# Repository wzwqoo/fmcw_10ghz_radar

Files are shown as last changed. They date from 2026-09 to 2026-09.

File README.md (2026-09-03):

# 10 GHz FMCW Radar Sensing Platform

A single-board **1TX / 3RX, 10 GHz FMCW radar**, its **Artix-7 range–Doppler–CFAR
backend**, and the **carrier board** that mounts the radar alongside a
global-shutter camera and an impact microphone.

The target application is a golf launch monitor: recover a ball's speed, launch
direction, spin rate and spin axis from one radar and one camera. That
application drives every architectural choice here — three non-collinear
receivers (the minimum that gives a radar-native spin axis), per-receiver
*complex* range–Doppler maps published to DDR3 (the phase the spin-axis
interferometer consumes), and a once-per-shot Ethernet offload so the heavy
post-processing runs on a host PC instead of in fabric.

```
┌─ rf_frontend/ — 10 GHz FMCW front-end ────────────────────────────────────┐
│                                                                           │
│  ADF4159 ramp PLL ──► HMC1163 10 GHz VCO ──► 4 dB branchline coupler      │
│                                                │             │            │
│                                     TX patch column    1→3 Wilkinson tree │
│                                                              │ LO         │
│  RX patch column ×3 ──► PMA3-14LN+ ──► LTC5548 ◄─────────────┘            │
│                                           │                               │
│                           ADA4940-2 IF ───┴──► ADAR7251  4 ch, 16-bit,    │
│                                                          simultaneous     │
│                                                                           │
└───────────────────────────────────────────────────────────────────────────┘
                                        │  40-pin FPC
                                        ▼
┌─ carrier_board/ — camera + radar carrier ─────────────────────────────────┐
│                                                                           │
│  radar 40-pin FPC ────────────────────────┐                               │
│  OV9281 ──MIPI──► TC358748 ──parallel─────┼──► 140-pin B2B ──► FPGA module│
│  INMP441 ──────────I2S────────────────────┘                               │
│                                                                           │
│  RTL8211F 1 GbE ◄─────────────────────────────────────────── UDP offload  │
│                                                                           │
└───────────────────────────────────────────────────────────────────────────┘
                                        │  parallel + I2S over the B2B connector
                                        ▼
┌─ fpga/ — Artix-7 backend ─────────────────────────────────────────────────┐
│                                                                           │
│  PPI bytes ──► TDM ──► BPF + Hilbert FIR ──► range FFT ×3 ──► DDR A       │
│                                                                │          │
│                        Doppler FFT ×3 ◄────────────────────────┘          │
│                              ├──► DDR B   per-RX complex RD maps          │
│                              └──► Σ|X|² ──► DDR C ──► CFAR ──► DDR D      │
│                                                                           │
│  audio + speed trigger ──► one-shot B/C/D dump ──► UDP packetizer         │
│                                                                           │
└───────────────────────────────────────────────────────────────────────────┘
                                        │
                                        ▼  host PC — trajectory, angle of arrival, spin
```

## Repository structure

| Path | Subsystem |
|---|---|
| [`rf_frontend/`](rf_frontend/) | The 10 GHz 1TX/3RX FMCW front-end: KiCad schematics and PCB on Isola 370HR, plus the ADS/Momentum EM results for every distributed structure |
| [`fpga/`](fpga/) | Artix-7 gateware: the raw-ADC → range–Doppler → CFAR pipeline, the DDR-to-host UDP offload path, MicroBlaze firmware, and the simulation stack |
| [`carrier_board/`](carrier_board/) | The carrier PCB that ties camera, radar, FPGA module, Ethernet and audio together, plus the CS-mount lens mechanics |

Each subsystem has its own README with the detail; the tables below are the map.

### `rf_frontend/` — 10 GHz FMCW front-end

A closed-loop fractional-N ramp PLL (ADF4159) drives a 10 GHz VCO (HMC1163)
across a 192 MHz sweep in 108 µs. The VCO fundamental is tapped through a 4 dB
branchline coupler and a 1→3 Wilkinson tree to supply a coherent LO to three
LNA-first receive chains (PMA3-14LN+ → LTC5548 → ADA4940-2), which land on an
ADAR7251's simultaneously-sampled channels. The antennas are series-fed patch
columns arranged in a staggered "^", stepped λ/2 between adjacent phase centres
in both array axes, so per-Doppler-bin angles never wrap.

→ [`rf_frontend/README.md`](rf_frontend/README.md)

### `fpga/` — Artix-7 digital backend

`01_adar7251_ppi_rx` → TDM mux → band-pass + Hilbert FIR → per-RX range FFT →
transposed DDR scatter (region A) → Doppler sequencer → per-RX Doppler FFT →
non-coherent integration (region C) + per-RX complex cache (region B) →
streaming cell-averaging CFAR (region D). A 128 × 256 grid, double-buffered so
software never reads a torn frame. An audio-plus-speed trigger picks the first
frame after impact that clears both gates and dumps its B/C/D regions to the
host over UDP.

→ [`fpga/README.md`](fpga/README.md)

### `carrier_board/` — camera + radar carrier

Hosts the camera FPC, the radar's 40-pin FPC, a 140-pin B2B connector to the
FPGA module, I2S audio headers, gigabit Ethernet and the power tree. Two
revisions live here: the current OV9281 design (schematics complete, layout not
yet drawn) and the earlier IMX477 design, which is where the completed layout
is.

→ [`carrier_board/README.md`](carrier_board/README.md)

## Status

| Item | State |
|---|---|
| `rf_frontend/` schematics + PCB layout | Complete; every distributed structure verified in ADS/Momentum |
| `fpga/` RTL pipeline (`01`…`08`) | Complete; unit tests and a raw-ADC-to-CFAR xsim run against the real Xilinx FFT/FIR IP |
| `fpga/` host offload (streamer, packetizer, receiver) | Complete and unit-tested |
| `fpga/firmware/audio_dsp.c` | Complete |
| `fpga/firmware/fusion_control.c` | **Work in progress** — the audio + speed trigger FSM and its frame-selection policy are still being written |
| `carrier_board/ov9281/` | **Work in progress** — schematics done, PCB layout not yet started |
| `carrier_board/imx477/` | Obsolete and not optimized — rolling-shutter sensor, hand-unfriendly USB 3.0 BGA. Kept as the revision with a finished layout |

## Toolchain

| Tool | Used for |
|---|---|
| KiCad ≥ 8 | `rf_frontend/kicad/`, `carrier_board/ov9281/`, `carrier_board/imx477/` |
| Keysight ADS + Momentum | EM verification of the antenna, coupler, splitter and LO tree |
| Vivado 2025.1 | Block design, IP generation, synthesis, the xsim end-to-end run |
| Icarus Verilog | The RTL unit tests — they need no vendor IP (`fpga/sim/run_unit_tests.sh`) |
| Python 3 (numpy, matplotlib) | Stimulus generation, CFAR golden checks, the UDP frame receiver |
| FreeCAD | `carrier_board/mechanical/CS-mount.FCStd` |

Large generated trees are deliberately out of the repository: the Vivado
project's `.runs`/`.gen`/`.cache` output, xsim build directories, and the ADS
workspace (its results are captured as images in `rf_frontend/ads/`).

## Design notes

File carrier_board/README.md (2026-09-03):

# `carrier_board/` — camera + radar carrier

The board everything else plugs into: the camera, the radar, the FPGA module,
the impact microphone, Ethernet, and the power tree.

Two revisions live here. **`ov9281/` is the current design and is a work in
progress** — the schematics are complete, the PCB layout is not yet drawn.
`imx477/` is the earlier revision, superseded but kept because it is the one
with a finished layout.

---

## `ov9281/` — current revision (work in progress)

Built around the **OV9281 global-shutter sensor**. Its interfaces:

| Sheet | Interface |
|---|---|
| `extension.kicad_sch` (CAM) | Camera **FPC connector**; the sensor's MIPI CSI-2 lanes into a **TC358748XBG** bridge, which presents them as a parallel bus (PD0–PD23, PCLK, HVALID, VVALID) the FPGA captures directly. PCA9543 I²C switch and TXS0108E level shifters alongside |
| `FPGA.kicad_sch` | **140-pin board-to-board connector** (2×70, 0.5 mm) carrying the parallel camera bus, radar bus and control to the FPGA module; JTAG; and the **I²S audio headers** (BCLK / LRCLK / SD) for the impact microphone |
| `FMCW.kicad_sch` | **40-pin shielded FPC connector** to the radar front-end, with TXS0108E level translation |
| `ETH.kicad_sch` | **Gigabit Ethernet**: RTL8211F-CG PHY, HY911130A RJ45 with integrated magnetics, SN74LVC2G34 buffers |
| `power.kicad_sch` | 12 V barrel jack → TPS54302 buck and TPS74801 LDO rails |
| `footprints/` | Project-local footprint libraries |

**Layout status: not started.** `ov9281/` is schematics only — there is no
`.kicad_pcb` in this revision.

### Why Ethernet and not USB 3.0

The IMX477 revision used a CYUSB3014 for the host link. That part is a
**121-ball TFBGA**, which is not realistically hand-reflowable, and it dictated
the whole main-board stackup and layout. The OV9281 revision drops it for
gigabit Ethernet through an RTL8211F, which is a QFN and reflows by hand
without difficulty.

That change also settled the processing split. Because frames are **buffered in
DDR and then sent to a PC for processing**, rather than being consumed live on
the FPGA, the **on-FPGA blob-detection logic from the IMX477 era is obsolete**.
The FPGA's job is now capture, buffer, and offload; detection, trajectory
fitting and spin estimation all happen on the host. The radar path in
[`../fpga`](../fpga) follows the same store-and-forward pattern.

---

## `imx477/` — earlier revision (obsolete)

Built around the **IMX477**, split across a `main_board/` (FPGA module, USB 3.0
host link, power) and a separate `sensor_board/`, joined by a DF40C/DF40HC
60-pin board-to-board pair.

**The IMX477 is obsolete for this application, and this revision is not
optimized.** The sensor is rolling-shutter, which smears a fast-moving ball
across the frame in a way no amount of downstream processing recovers — a
global-shutter sensor is the requirement, and that is what the OV9281 revision
exists to satisfy. The USB 3.0 host path is the second reason it was dropped
(see above).

It is kept here because it is the only revision that carries a completed PCB
layout, and because its power tree and B2B pinout carry over.

| Path | Contents |
|---|---|
| `imx477/main_board/main_board.kicad_pro` / `.kicad_sch` / `.kicad_pcb` | KiCad project, schematics, and the finished layout |
| `imx477/main_board/USB3.kicad_sch` | CYUSB3014 USB 3.0 controller, AT24CM02 config EEPROM, VBUS switching — the path replaced by Ethernet |
| `imx477/main_board/FPGA.kicad_sch` | 2×70 B2B to the FPGA module, JTAG |
| `imx477/main_board/extension.kicad_sch` | DF40HC 60-pin B2B to the sensor board |
| `imx477/main_board/power.kicad_sch` | TLV62130 / AP3417C / MIC5504 rails |
| `imx477/sensor_board/` | The IMX477 sensor board: `sensors.kicad_sch`, `power.kicad_sch`, and its layout |
| `imx477/footprints/` | Project-local footprint libraries |

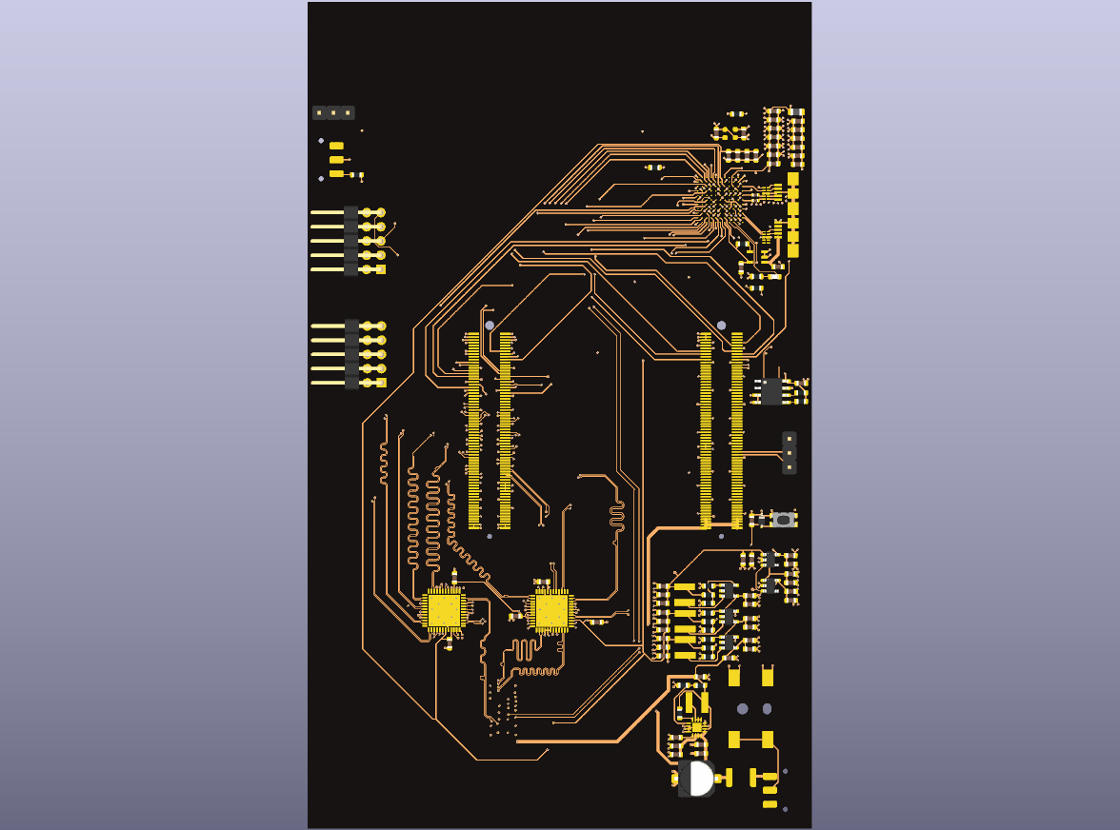
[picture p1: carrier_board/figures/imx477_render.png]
IMX477 main-board layout


---

## `mechanical/`

`CS-mount.FCStd` — a FreeCAD CS-mount lens holder, drawn for the IMX477 sensor
board. `lens_spec.png` records the optics it was sized around: a 4 mm lens
giving roughly 90° horizontal field of view, paired with 940 nm IR flood
illumination so exposures stay short enough for 200 fps and above.

---

## Opening the boards

```
kicad carrier_board/ov9281/hardware.kicad_pro           # KiCad 8 or newer
kicad carrier_board/imx477/main_board/main_board.kicad_pro
kicad carrier_board/imx477/sensor_board/sensor_board.kicad_pro
```

The render above was produced with `kicad-cli pcb render`.

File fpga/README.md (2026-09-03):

# `fpga/` — Artix-7 range–Doppler–CFAR backend

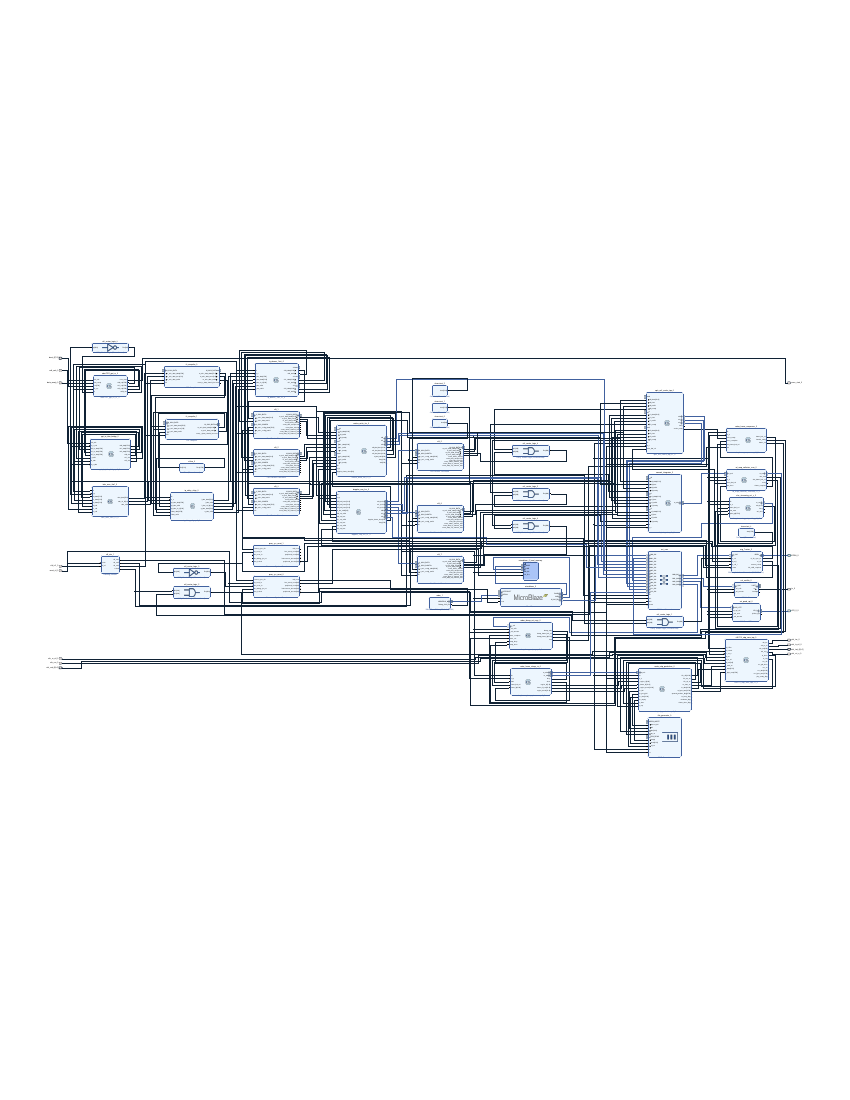
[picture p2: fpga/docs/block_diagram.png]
Block diagram


The digital half of the platform. It ingests raw ADAR7251 PPI bytes from
[`../rf_frontend`](../rf_frontend), turns them into three per-receiver complex
range–Doppler maps plus a summed power map and a packed CFAR detection map in
DDR3, and — once per shot — ships one selected frame to a host PC over UDP.

Everything that has to run at line rate is in fabric. Everything that benefits
from floating point and libraries (clustering, tracking, angle-of-arrival, the
spin-axis interferometry) is deliberately not: it runs on the host, on a frame
the FPGA has already reduced to ~516 KiB.

## Pipeline

```
 ADAR7251 PPI bytes
        │
   01   ├─ adar7251_ppi_rx          byte capture, channel framing
   01b  ├─ ppi_to_tdm_bridge
   02   ├─ tdm_mux_3to1             3 RX → one tagged TDM stream
        ├─ FIR Compiler             band-pass + Hilbert (quadrature by DSP,
        │                           not by a hardware I/Q receiver)
   03   ├─ iq_delay_align           matches the Hilbert group delay on I
   04   ├─ iq_demux_1to3            back out to 3 per-RX lanes
        ├─ xfft ×3                  range FFT, 128 bins
   05a  ├─ scatter_write_3rx  ─────► DDR region A   (transposed / range-major,
        │                                            ping-pong)
   05b  ├─ doppler_seq_3rx    ◄─────  reads each range bin as one burst
        ├─ xfft ×3                  Doppler FFT, 256 bins
   06b  ├─ cplx_cell_cache_top ────► DDR region B   3 × complex RD map, 384 KiB
   06a  ├─ noncoh_integrator        Σ|X|² across the 3 receivers
   07a  ├─ rd_map_collector_summed ► DDR region C   summed power map, 128 KiB
   08   └─ cfar_detector      ─────► DDR region D   packed detections, 4 KiB
```

**Grid:** 128 range bins × 256 Doppler bins. **Corner turn:** done in the DDR
address map rather than in a transpose buffer — the range-FFT scatter writer
stores each receiver's output range-major, so the Doppler sequencer reads each
range bin as a single contiguous burst.

**Publication protocol:** region A ping-pongs on its own; B, C and D switch
together on one `frame_buf_sel` bit, so software can never read region B from
one frame and region D from another. `rtl/radar_params.vh` is the single source
of truth for the geometry and the whole address map.

## Host offload

The FPGA does not stream continuously. It buffers, waits for a trigger, then
sends exactly one frame:

```
DDR3 ─AXI4─► radar_frame_dump_streamer ─AXIS─► radar_udp_packetizer ─► FIFO ─► udp_tx ─► PHY ─► host
```

Region A is not dumped — B is the Doppler transform of A, so A is redundant for
every target metric, and it has an independent ping-pong that would need
freezing to stay coherent. B + C + D is ~516 KiB per shot, 1040-byte UDP
packets, 16-byte big-endian header. `host/recv_radar_frame_udp.py` reassembles
it and can render the range–Doppler map.

`host/README.md` has the packet format, the region table, and the block-design
wiring.

## Layout

| Path | Contents |
|---|---|
| [`rtl/`](rtl/) | The pipeline, numbered in dataflow order `01_adar7251_ppi_rx.v` … `08_cfar_detector.v`, plus `radar_params.vh` |
| [`host/`](host/) | Frame sequencer, DDR dump streamer, UDP packetizer, AXI-Lite control registers, their testbenches, and the Python host receiver — see [`host/README.md`](host/README.md) |
| [`firmware/`](firmware/) | MicroBlaze C: `audio_dsp` (I2S impact detector) and `fusion_control` (the trigger FSM) |
| [`sim/`](sim/) | Unit tests and the raw-ADC-to-CFAR end-to-end run — see [`sim/README.md`](sim/README.md) |
| [`utilization/`](utilization/) | Per-module out-of-context utilization reports and their `summary.txt` |
| [`docs/`](docs/) | Block diagram, resource-breakdown and timing-budget figures, and `block_design.pdf` (the full Vivado block design) |

## Firmware (`firmware/`)

`audio_dsp.c` is the impact detector: an INMP441 over AXI-I2S into a DMA'd
ring buffer, then high-pass → onset detection → feature extraction →
club/no-club classification. It forwards labels to the trigger FSM and never
resets it.

`fusion_control.c` is the trigger FSM: on a club label it arms a short window;
for each completed frame it scans the region-C summed power map already in DDR
for peak, mean, SNR and the peak's Doppler velocity; the first armed frame that
clears both the speed and the SNR gate requests that frame's dump and asserts
`halt`, so the 2-deep ping-pong cannot overwrite the chosen frame while it
streams. With only two buffer sets, "remember the best frame across the whole
trajectory" is not available — first-over-threshold with an early stop is.

> **`fusion_control.c` is still a work in progress.** The state machine and the
> host-testable scaffolding are there (`-DTRIG_TESTBENCH`), but the gates in
> `fusion_control.h` are placeholders: `TRIG_VEL_RES_CMS` in particular must be
> derived from the real chirp rate and PRF rather than the value currently
> stubbed in, and the DDR region-C scan is not yet wired to the AXI register
> block that pulses `start`.

## Resource utilization (`utilization/`)

Out-of-context synthesis of every block-design IP plus the RTL, targeting
`xc7a100tfgg484-2`. The radar datapath itself is small — 942 LUT and 6 DSP for
every hand-written module except CFAR — and total device usage is dominated by
the AXI SmartConnect (~24.5k LUT), the MIG (~5.2k LUT) and MicroBlaze (~1.2k
LUT). The design fits comfortably on `xc7a100t` at ~58% LUT; it does not fit
`xc7a35t` without reducing the interconnect.

> Read `summary.txt`'s `cfar_streaming_axi_verilog` row and its `TOTAL` with
> care. Synthesized out of context, CFAR's 37-row sliding window infers as
> registers and F7/F8 muxes rather than BRAM (that row reports 0 BRAM against
> 702k FF), so both it and the summed total are artifacts of OOC synthesis, not
> the in-context cost. The per-module rows for everything else are
> representative.

## Building and running

Unit tests need only Icarus Verilog:

```bash
bash sim/run_unit_tests.sh          # expect RESULT: PASS from each testbench
```

The end-to-end simulation instantiates the real Xilinx FFT and FIR IP, so it
needs Vivado and a generated block design:

```bash
export VIVADO_SETTINGS=/path/to/Vivado/settings64.sh
export BD_GEN=/path/to/<project>.gen/sources_1/bd/<bd_name>
bash sim/run_e2e_3rx.sh             # ~30 min with the real FFT IP
```

The Vivado project itself (`.runs`, `.gen`, `.cache` — several hundred MB of
generated output) is not tracked. `docs/block_design.pdf` is the block design it
builds; regenerate the IP in Vivado before running the end-to-end simulation.

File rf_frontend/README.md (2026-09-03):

# `rf_frontend/` — 10 GHz 1TX/3RX FMCW front-end

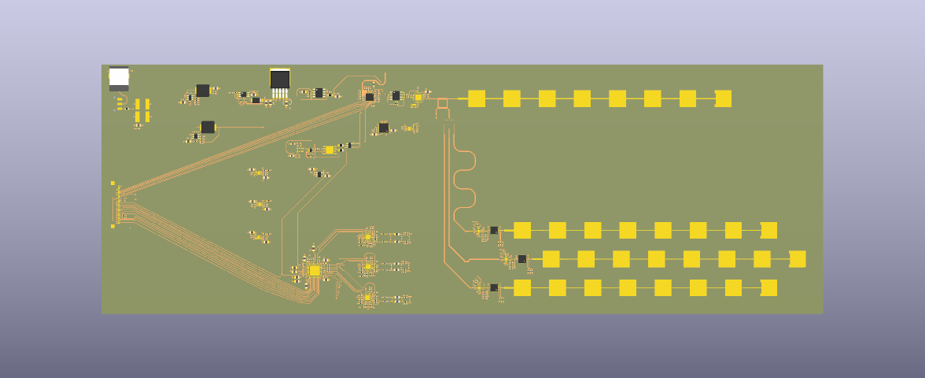
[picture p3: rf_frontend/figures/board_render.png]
Board render — the four series-fed patch columns are on the right edge


The analog half of the platform: a coherent FMCW radar that sweeps 192 MHz
around 10 GHz in 108 µs, radiates it from a series-fed patch column, and lands
three receive chains on an ADAR7251's simultaneously-sampled ADC channels.
Simultaneous sampling is the point — it is what preserves the inter-receiver
phase that angle-of-arrival and the spin-axis interferometer downstream consume.

Everything is discrete MMIC rather than an integrated transceiver, so each
channel's gain, noise figure and LO drive is set and measurable on its own.

## Signal chain

```
                     ┌──────────────┐
  KT2520K ──ref──►   │   ADF4159    │  fractional-N ramp PLL, type 2
                     │  ramp gen +  │──── CP ──► ADA4625-1 loop filter ──┐
                     │     PFD      │                                    │
                     └──────▲───────┘                                    ▼
                            │ ÷2 output (feedback only)          ┌──────────────┐
                            └────────────────────────────────────│   HMC1163    │
                                                                 │ 10 GHz VCO   │
                                                                 └──────┬───────┘
                                                        11 dBm fundamental
                                                                        │
                                        ┌───────── 4 dB branchline coupler ─────────┐
                                        │                                           │
                              TX patch column                          1 → 3 Wilkinson tree
                                (+7 dBm radiated)                       │      │      │
                                                                        ▼      ▼      ▼
     RX column ×3 ──► PMA3-14LN+ ──► LTC5548 ◄──────────────────────── LO (≈0 dBm at each mixer)
                       (+22.6 dB)      │
                                       ▼
                                  ADA4940-2 differential IF driver ──► ADAR7251 (4 ch, 16-bit)
```

Key consequence of the LNA-first ordering: the LNA contributes no line of its
own to the link budget — it lifts signal and noise together — but it is why the
cascaded noise figure is ≈2 dB rather than the ≈12 dB of a mixer-first chain.
The LTC5548's ≈8.5 dB conversion loss enters only as added noise, divided down
by the LNA gain.

## Key components

| Function | Part |
|---|---|
| Ramp PLL (fractional-N, type 2) | ADF4159 |
| VCO, 10 GHz fundamental + ÷2 | HMC1163 |
| Loop-filter amplifier (JFET input) | ADA4625-1 |
| Reference oscillator / buffer | KT2520K, NB3N551 |
| LNA, ×3 | PMA3-14LN+ |
| Downconversion mixer, ×3 | LTC5548 |
| Differential IF driver | ADA4940-2 |
| ADC — 4 channels, simultaneous sampling | ADAR7251 |
| LO distribution | 4 dB branchline coupler + 1→3 Wilkinson splitter (both distributed, on-board) |
| Pad attenuators | PAT1220 (4 dB / 6 dB) |
| Supplies | TPS7A4701 and TPS7A91 (low-noise LDO for the RF rails), TPS54302, MIC29302A, ADP1613 boost |
| Host interface | 40-pin shielded FPC to the carrier board |

## Antenna array

Three receive columns plus one transmit column, all series-fed patches on the
top layer:

- **Series-fed columns, not single patches.** On this substrate a lone patch
  radiates poorly at 10 GHz; an 8-element column reaches ≈15.5 dBi directivity
  and ≈8.5 dBi realized gain at ≈18% radiation efficiency, so the column's
  directivity buys back most of what the dielectric burns as heat.
- **Staggered "^" geometry.** Adjacent phase centres are stepped λ/2 (15 mm) in
  *both* array axes, so neither measured adjacent-pair phase ever wraps, and
  their sum supplies a full-λ baseline whose ambiguity is already spent. The
  solve stays unambiguous across ±90° on both principal axes.
- **TX–RX separation of 75 mm** — simultaneously the isolation the array needs
  and the largest separation the LO trace-loss budget allows.

## Substrate

Isola 370HR, Dk 3.92, tanδ 0.025, 0.254 mm dielectric. It is a lossy laminate
for X-band, chosen deliberately over a PTFE alternative on cost; the antenna
design in `ads/` is what makes it work rather than the substrate.

## Layout

| Path | Contents |
|---|---|
| `kicad/hardware.kicad_pro`, `hardware.kicad_sch` | KiCad project and top-level sheet |
| `kicad/TX.kicad_sch` | VCO, ramp PLL, loop filter, coupler, LO tree, TX feed |
| `kicad/RX.kicad_sch` | 3× LNA → mixer receive chains |
| `kicad/IF.kicad_sch` | IF conditioning and the ADAR7251 |
| `kicad/power.kicad_sch` | Power tree, with the RF rails on low-noise LDOs |
| `kicad/hardware.kicad_pcb` | Board layout |
| `kicad/Design1.pll`, `Design2.pll` | ADIsimPLL loop designs |
| `kicad/footprints/` | Project-local libraries — including the hand-drawn `antenna`, `splitter` and `branchline` distributed structures |
| `ads/` | Momentum results (see below) |
| `figures/` | Link budget, array spacing / precision, near-field analysis, board render |

The distributed structures are *footprints*, not components: the patch column,
the Wilkinson splitter and the branchline coupler are drawn as copper in
`kicad/footprints/*.pretty` and placed like parts.

## EM verification (`ads/`)

Each on-board distributed structure was simulated in ADS/Momentum on the 370HR
stackup before being committed to copper. The workspace itself is too large to
track, so each result is captured as an image:

| File | Result |
|---|---|
| `patch_antenna.png`, `patch_antenna_schema.png`, `patch_antenna_result.png` | The series-fed column: geometry, feed schema, and realized gain / efficiency |
| `splitter_result.png` | 1→3 Wilkinson tree, per-port split and match |
| `coupler_result.png` | 4 dB branchline coupler |
| `LO_tree.png`, `LO_tree_result.png` | The assembled coupler + splitter LO distribution — ≈0 dBm landing at each mixer, −11 dB worst-case tree loss from the 11 dBm VCO |
| `LNA_gain.png` | Receive-chain gain |
| `TX_RX_isolation.png` | ≈−60 dB against a −30 dB requirement |
| `3RX_coupling.png` | Adjacent-RX coupling of −35 to −45 dB, which bounds worst-case angle-of-arrival error below 0.5° |

## Opening the board

```
kicad rf_frontend/kicad/hardware.kicad_pro     # KiCad 8 or newer
```

The render at the top of this page was produced with `kicad-cli pcb render`.

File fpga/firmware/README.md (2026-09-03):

# `fpga/firmware/` — MicroBlaze C

Two modules. `audio_dsp` decides *that* a ball was struck; `fusion_control`
decides *which* radar frame to keep and ship. Both are written so the logic
compiles and runs on a host PC with no Xilinx BSP in sight — the board-specific
layer is behind `#ifdef`.

| File | Role |
|---|---|
| `audio_dsp.c` / `.h` | INMP441 impact detector |
| `fusion_control.c` / `.h` | Audio + speed trigger FSM and frame selection |

## `audio_dsp`

INMP441 → AXI I2S receiver → AXI DMA (simple S2MM, no scatter-gather) → a pair
of ping-pong buffers. From there, per hop:

```
hpf_process() → check_onset() → extract_features() → classify()
```

Features are peak frequency and spectral centroid (both approximated from
zero-crossing rate), ZCR itself, decay time constant, and crest factor; an LDA
classifier turns them into `CLUB` / `WALL` / `OTHER` / `NONE`. Labels are
forwarded to `fusion_control_submit_audio()`. This module never resets the
trigger FSM — that is `fusion_control`'s alone.

Three compilation tiers:

| Define | Compiles |
|---|---|
| *(none)* | The DSP core only — portable C, no board dependencies |
| `MICROBLAZE_AUDIO_MAIN` | The hardware layer: DMA init, the FreeRTOS task, `audio_main()` |
| `TESTBENCH` | Introspection hooks (`audio_dsp_feat_win_size`, `audio_dsp_hpf_gain`) for host-side checks of the filter and framing constants |

## `fusion_control` — work in progress

The trigger FSM: `IDLE → ARMED → COOLDOWN`.

1. A `CLUB` label from `audio_dsp` arms a short window.
2. For each completed radar frame, scan the region-C summed |X|² map already in
   DDR for peak, mean, SNR (`peak/mean`) and the peak's Doppler velocity. All in
   software — there is no hardware peak tracker.
3. The **first** armed frame that clears both the speed gate and the SNR gate
   requests that frame's dump and asserts `halt`, so the 2-deep ping-pong cannot
   overwrite it mid-stream.

With only two buffer sets, keeping the best frame across a whole trajectory is
not possible — it gets overwritten. First-over-threshold with an early stop is
the policy that fits the memory budget.

The FSM logic and its host tests are done:

```bash
gcc -O2 -DTRIG_TESTBENCH fusion_control.c -lm -o trig_tb && ./trig_tb
# RESULT: PASS
```

**What is still outstanding:**

- The gates in `fusion_control.h` are placeholders. `TRIG_VEL_RES_CMS`
  (cm/s per Doppler bin) is stubbed at 55 and must be derived from the real
  chirp rate and PRF; `TRIG_SPEED_CMS` and the SNR ratio are first guesses.
- The region-C scan is not yet wired to `radar_dump_axi_regs.v`, the AXI-Lite
  block that actually pulses `start` on the frame dump streamer.
- No camera / computer-vision fusion, despite the module's name — the current
  scope is audio plus radar speed only.

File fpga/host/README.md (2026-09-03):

# radar_3rx host readout — one-shot B/C/D frame dump over UDP

Ships the **highest-power radar frame**'s post-Doppler DDR3 product regions
(B/C/D) to a host PC so the host can run post-CFAR / trajectory / spin
processing. One-shot per shot, bounded (~516 KiB for 3 RX), triggered by
software (the audio+speed fusion FSM decides *which* frame is the highest-power
one and pulses `start`).

Region **A** (range-FFT scratch) is intentionally **not** dumped: B is the
Doppler transform of A (so A is redundant for all target metrics), and A has an
independent ping/pong that would need freezing to stay coherent. Dumping only
B/C/D — which share one `frame_buf_sel` — makes the transfer coherent with a
single select bit.

## Datapath

```
DDR3 (MIG) ─AXI4─ AXI SmartConnect ─AXI4─ radar_frame_dump_streamer ─AXIS(32b)─ radar_udp_packetizer ─32b─ fifo_generator ─ udp_tx ─ PHY ─► host
                                          (.m_axis + sideband)         (.s_axis + sideband)         (Vivado IP)   (UDP core)
```

Two verified blocks in this folder, feeding the block design's FIFO + UDP core:

- **`radar_frame_dump_streamer.v`** — AXI4 read master that walks B→C→D of the
  selected frame buffer and emits the frame as one 32-bit AXI-Stream:
  - `start` (1-cycle) + `frame_buf_sel` (0=B0/C0/D0, 1=B1/C1/D1) +
    `frame_id` → `busy`, then `done` (1-cycle) after region D's last beat.
  - Sideband while a region streams: `region_id` (0=A,1=B,2=C,3=D), `frame_id_out`,
    `region_words`; `tuser` marks a region's first beat, `tlast` its last beat.
  - Output skid holds `tvalid`/`tdata` until `tready` — correct under UDP FIFO
    backpressure (verified by `tb_radar_frame_dump_streamer.v`).

- **`radar_udp_packetizer.v`** — drives the `fifo_generator` + `udp_tx`
  `tx_start_en/tx_data/tx_byte_num/tx_req/tx_done` idiom. Chops the stream into
  fixed `PAYLOAD_WORDS`-word UDP packets (default 256 = 1024-byte payload, +16-byte
  header = `PACKET_BYTES`=1040), filling the header from the streamer sideband and
  driving `region_first`/`region_last` flags from offsets. Header words are
  big-endian on the wire; payload words are byte-swapped to little-endian to match
  the host `recv_radar_frame_udp.py` (`>IIBBHI` header, `<u4` payload). Verified by
  `tb_radar_udp_packetizer.v`.

  Every region word-count is an exact multiple of `PAYLOAD_WORDS`, so all packets
  are full — there is no padding or ragged-tail logic.

## UDP packet header (16 bytes, big-endian)

| offset | size | field | notes |
|---:|-----:|---|---|
| 0 | u32  | magic | `0x52414446` = `'RADF'` |
| 4 | u32  | frame_id | echo of `frame_id_out` |
| 8 | u8 | region_id | 0=A, 1=B, 2=C, 3=D |
| 9 | u8 | flags | bit0 = region_first, bit1 = region_last  |
| 10 | u16  | reserved | 0 |
| 12 | u32  | byte_offset  | byte offset of this payload in region |

Payload after the header is raw little-endian `uint32` region data.

## Region sizes (3 RX, from radar_params.vh)

| region | id | contents | bytes |
|---|----|---|---|
| B | 1  | per-RX complex RD map (3 RX)  | 384 KiB |
| C | 2  | summed \|X\|² RD map | 128 KiB |
| D | 3  | packed CFAR det map | 4 KiB |

Total ~516 KiB. Region A (id 0) is not dumped. C is one summed map
(RX-independent): 128×256×4 = 128 KiB, the range-Doppler magnitude image.

## How to connect (block design wiring)

Five connection groups. The streamer is an **AXI4 read master** and an **AXIS
master**; the packetizer is the AXIS slave + the existing FIFO/UDP TX path.

1. **Clock/reset** — drive `clk`/`rst_n` of both blocks from the same domain as
   the MIG user clock (or cross with a CDC FIFO if your UDP core runs on a
   different clock). `rst_n` active-low.

2. **Streamer AXI4 read → SmartConnect → MIG.** Wire `m_axi_ar*`/`m_axi_r*` to a
   slave port of the AXI SmartConnect that already feeds the MIG (the same one
   `doppler_seq_*` / `cfar` read through). Tie `m_axi_arsize`/`arburst` are driven
   by the block. No write channel needed (read-only).

3. **Streamer AXIS + sideband → packetizer.**
   `m_axis_tdata/tvalid/tready/tlast/tuser` → `s_axis_*`, and the sideband
   `region_id → s_region_id`, `frame_id_out → s_frame_id`, `region_words →
   s_region_words`.

4. **Packetizer → FIFO Generator → udp_tx.** Connect
   `fifo_din/fifo_wr_en/fifo_full/fifo_prog_full` and `fifo_dout/fifo_rd_en/
   fifo_empty` to a Vivado **FIFO Generator** (32-bit, common clock, depth ≥ a few
   packets = ≥ ~1024 words), and `tx_start_en/tx_data/tx_byte_num/tx_req/tx_done`
   to the `udp`/`udp_tx` core.

5. **Control (the trigger).** Pulse `start` for one cycle with `frame_buf_sel` and
   `frame_id` valid. Source options:
   - **Software (recommended for "highest-power frame"):** a MicroBlaze AXI-Lite
     register block — `radar_dump_axi_regs.v` in this folder — whose write sets
     `frame_buf_sel`/`frame_id` and pulses `start`. The audio+speed trigger FSM
     ([`../firmware/fusion_control.c`](../firmware/fusion_control.c), still a
     work in progress) decides which buffered frame is the highest-power one and
     issues the dump.
   - **Hardware:** gate `start` off `cplx_cell_cache_top.cache_ready` (frame
     complete) when a peak-power threshold is met. `busy` blocks re-triggering;
     wait for `done` before the next `start`.

```verilog
radar_frame_dump_streamer u_dump (
    .clk(clk), .rst_n(rst_n),
    .start(dump_start), .frame_buf_sel(dump_sel),
    .frame_id(dump_frame_id), .busy(dump_busy), .done(dump_done),
    // AXI4 read -> SmartConnect slave port -> MIG
    .m_axi_araddr(ar_addr), .m_axi_arlen(ar_len), .m_axi_arsize(ar_size),
    .m_axi_arburst(ar_burst), .m_axi_arvalid(ar_valid), .m_axi_arready(ar_ready),
    .m_axi_rdata(r_data), .m_axi_rresp(r_resp), .m_axi_rlast(r_last),
    .m_axi_rvalid(r_valid), .m_axi_rready(r_ready),
    // AXIS payload + sideband -> packetizer
    .m_axis_tdata(ax_tdata), .m_axis_tvalid(ax_tvalid), .m_axis_tlast(ax_tlast),
    .m_axis_tuser(ax_tuser), .m_axis_tready(ax_tready),
    .region_id(ax_region), .frame_id_out(ax_frame), .region_words(ax_words)
);

radar_udp_packetizer #(.PAYLOAD_WORDS(256), .PACKET_BYTES(16'd1040)) u_pkt (
    .clk(clk), .rst_n(rst_n),
    .s_axis_tdata(ax_tdata), .s_axis_tvalid(ax_tvalid), .s_axis_tready(ax_tready),
    .s_axis_tuser(ax_tuser), .s_axis_tlast(ax_tlast),
    .s_region_id(ax_region), .s_frame_id(ax_frame), .s_region_words(ax_words),
    .fifo_din(fifo_din), .fifo_wr_en(fifo_wr_en), .fifo_full(fifo_full),
    .fifo_prog_full(fifo_prog_full), .fifo_dout(fifo_dout),
    .fifo_rd_en(fifo_rd_en), .fifo_empty(fifo_empty),
    .tx_start_en(tx_start_en), .tx_data(tx_data), .tx_byte_num(tx_byte_num),
    .tx_done(tx_done), .tx_req(tx_req),
    .queued_packets_dbg(), .tx_busy_dbg(), .underrun_dbg(), .frame_done_dbg()
);
```

> Ordering rule: only `start` a dump on a frame buffer software has *finished*
> reading-back is not required, but PL must not be overwriting that same
> `frame_buf_sel` B/C/D set while it streams. Trigger on a completed, idle buffer.

## Host receiver

```
python3 recv_radar_frame_udp.py --port 6000 --outdir ./capture --show
```

Reassembles each region by `byte_offset`, writes `frame_<id>_B/C/D.bin`, prints
a completeness report, and with `--show` renders the C range-Doppler map.

## Simulation

```
iverilog -g2012 -I ../rtl -o /tmp/dump_tb \
    tb_radar_frame_dump_streamer.v radar_frame_dump_streamer.v
vvp /tmp/dump_tb        # expect: total_beats = 230400, errors = 0, RESULT: PASS
```

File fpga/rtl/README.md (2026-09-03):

# `fpga/rtl/` — the pipeline

Files are numbered in dataflow order. Everything runs on one fast clock domain
except the ADC byte-capture front end, and every module that crosses an AXI
`RVALID`/`TVALID` seam carries a skid buffer so it stays correct under
backpressure.

| File | Module | Does |
|---|---|---|
| `01_adar7251_ppi_rx.v` | `adar7251_ppi_rx` | Byte capture from a single ADAR7251 in PPI byte-wide mode. The part always streams all four physical channels (8 bytes per sample set), so this receives all 8 bytes — preserving SCLK / DATA_READY timing and the byte-7 valid pulse — and exposes the three that are wired to antennas |
| `01b_ppi_to_tdm_bridge.v` | `ppi_to_tdm_bridge` | Adapts three simultaneously-valid channels (one `sclk_adc` cycle every ~833 ns) into the staggered one-per-cycle presentation the TDM mux expects |
| `02_tdm_mux_3to1.v` | `tdm_mux_3to1` | Three slow channels into one tagged TDM stream at 3× the input rate |
| `03_iq_delay_align.v` | `iq_delay_align` | Delays I to match the Hilbert FIR's group delay on Q, so the pair recombines in phase |
| `04_iq_demux_1to3.v` | `iq_demux_1to3` | Splits the TDM I/Q stream back into three per-RX lanes |
| `05a_scatter_write_master.v` | `scatter_write_master` | Writes one receiver's range-FFT output to DDR3 **transposed** (column-major), at `buf_base + rx·RX_STRIDE + (k·N_CHIRPS + n)·SAMPLE_BYTES`, with the A-region ping-pong integrated |
| `05a_scatter_write_3rx.v` | `scatter_write_3rx` | Three-lane wrapper — one writer per range FFT |
| `05b_doppler_seq_ctrl.v` | `doppler_seq_ctrl` | Reads region A back as one contiguous `N_CHIRPS`-beat burst per range bin and streams it into a Doppler FFT. The transpose done on the write side is what makes this a single burst |
| `05b_doppler_seq_3rx.v` | `doppler_seq_3rx` | Three-lane wrapper, one per Doppler FFT IP |
| `06a_noncoh_integrator.v` | `noncoh_integrator` | Per cell, `Σ_rx (I² + Q²)` across the three receivers, saturated to `OUT_W` bits |
| `06b_cplx_cell_writer.v` | `cplx_cell_writer` | Writes one receiver's complex Doppler-FFT output to DDR3 region B — the per-Doppler-bin phase the host's AoA and spin-axis processing reads |
| `06b_cplx_cell_cache_top.v` | `cplx_cell_cache_top` | Three writers, three separate AXI4 master ports; the SmartConnect arbitrates on the MIG side |
| `07a_rd_map_collector_summed.v` | `rd_map_collector_summed` | Writes the summed power map to region C and hands it to CFAR |
| `08_cfar_detector.v` | `cfar_streaming_axi_verilog` | Streaming 2-D cell-averaging CFAR: a 37-row sliding window held in BRAM, one cell per cycle, packed detections to region D |
| `radar_params.vh` | — | Frame geometry and the complete DDR address map |

## `radar_params.vh`

Every stage and every testbench includes it, and nothing else defines these
numbers:

```
RADAR_RANGE_BINS    128
RADAR_DOPPLER_BINS  256
RADAR_RX_COUNT      3
```

Per-frame DDR products, and the ping-pong discipline:

| Region | Contents | Size |
|---|---|---|
| A | Range-FFT scratch, transposed, 3 RX | 384 KiB — ping-pongs independently |
| B | Per-RX complex range–Doppler maps | 384 KiB |
| C | Summed \|X\|² map, and the CFAR input image | 128 KiB |
| D | Packed CFAR detection bitmap | 4 KiB |

B, C and D switch together on one `frame_buf_sel` bit and are spaced on a 1 MiB
stride. Software must never read B from one frame and D from another — that is
the reason for the single select bit rather than three.

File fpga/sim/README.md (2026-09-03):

# `fpga/sim/` — simulation

Two tiers: unit tests that need nothing but Icarus Verilog, and a full
raw-ADC-to-CFAR run that instantiates the real Xilinx FFT and FIR IP.

## Unit tests

```bash
bash run_unit_tests.sh          # each testbench prints RESULT: PASS
```

| Test | Verifies |
|---|---|
| `tb_noncoh_integrator3.v` | 3-input Σ\|X\|² with saturation, and `tlast` propagation through the adder tree |
| `tb_tdm_frontend3.v` | `tdm_mux_3to1` mod-3 tag sequencing and `iq_demux_1to3` routing |
| `../host/tb_radar_frame_dump_streamer.v` | B→C→D DDR dump: region order, `region_id`, `tuser`/`tlast`, and correctness under backpressure |
| `../host/tb_radar_udp_packetizer.v` | Packet chopping, header fields, byte order, `region_first`/`region_last` |
| `../host/tb_radar_dump_regs.v` | AXI-Lite control register block |
| `../host/tb_radar_frame_sequencer.v` | `bundle_ready` pulse, frame-set report, `frame_buf_sel` toggle, and that `halt` holds the toggle |

The script builds into `$TMPDIR/radar_3rx_tests` and needs no vendor IP.

## End-to-end (`run_e2e_3rx.sh`)

One shot of raw ADAR7251 PPI bytes all the way to CFAR detections, through the
real vendor FFT/FIR IP — which is why it needs Vivado's `xsim` and a generated
block design rather than Icarus:

```
raw PPI → 3ch TDM → 3 range FFTs → scatter_write_3rx → DDR A
        → doppler_seq_3rx → 3 Doppler FFTs → {cplx_cell_cache, noncoh ×3} → C
        → CFAR → D
```

Each stage is checked for having written and read its DDR region.

```bash
export VIVADO_SETTINGS=/path/to/Vivado/settings64.sh
export BD_GEN=/path/to/<project>.gen/sources_1/bd/<bd_name>
bash run_e2e_3rx.sh
bash run_e2e_3rx.sh clean       # remove the xsim build directory
```

`BD_GEN` must point at the block design's generated IP tree — the script pulls
the FIR `.mif` files and the six FFT instances (3 range + 3 Doppler) from it,
and compiles the shared Xilinx IP support VHDL into a local `xsim.dir`.

Runtime is roughly 30 minutes with the real FFT IP. It defaults to turbo mode
(fast ADC byte clock, short clock periods); every knob is an environment
variable at the top of the script — `SMOKE_MODE=1` and `STIM_LIMIT_BYTES` give
a much shorter smoke run.

## Supporting scripts

| File | Purpose |
|---|---|
| `gen_ppi_hex_3rx.py` | Generates one frame of ADAR7251 PPI stimulus: a synthetic FMCW point target at a chosen range and velocity, with per-channel phases matching the array geometry in [`../../rf_frontend`](../../rf_frontend). Writes `ppi_stream.hex` (for `$readmemh`), a `.bin`, and a JSON metadata sidecar. No arguments — edit the constants at the top |
| `check_cfar_output.py` | Golden check on the CFAR detection map dumped from region D |
| `tb_e2e_3rx.v` | Behavioral end-to-end testbench |
| `tb_e2e_3rx_xsim.v` | The xsim variant, with the 3-lane behavioral DDR model that `run_e2e_3rx.sh` elaborates |

The summed region-C map and the region-D CFAR output are receiver-independent,
so the golden checks apply unchanged regardless of how the per-RX maps are
combined upstream.

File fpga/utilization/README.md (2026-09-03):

# `fpga/utilization/` — resource reports

Out-of-context (OOC) synthesis of every block-design IP plus the pipeline RTL,
targeting `xc7a100tfgg484-2` under Vivado 2025.1. One `.rpt` per module, plus
`summary.txt`, which is the LUT / FF / DSP / BRAM column extracted from each.

## What it says

The radar datapath itself is cheap. Summing every hand-written module in
`summary.txt` except CFAR (see below) gives **942 LUT, 2102 FF, 6 DSP** — the
whole `01`…`07` chain plus the three host-offload blocks. Device usage is
dominated by infrastructure, not by radar:

| Block | LUT |
|---|---|
| AXI SmartConnect | ~24.5k |
| MIG (DDR3 controller) | ~5.2k |
| MicroBlaze | ~1.2k |
| Each FFT instance (6 of them) | 628–660 |

The design fits `xc7a100t` at roughly 58% LUT. It does **not** fit `xc7a35t`
without cutting the interconnect down — the SmartConnect alone is most of a
35T.

## Reading `summary.txt`

Two rows are misleading and should not be taken at face value:

- **`cfar_streaming_axi_verilog` (432k LUT / 702k FF / 0 BRAM).** Synthesized
  out of context, CFAR's 37-row sliding window has nothing telling it to use
  block RAM, so it infers as registers and F7/F8 muxes. In context it maps to
  BRAM. The OOC number is an artifact of how the report was generated, not the
  module's real cost.
- **`TOTAL (sum of OOC)`.** It carries that artifact, so it is far above the
  real device usage.

Every other per-module row is representative.

Each `.rpt` is `report_utilization` output on a separately-synthesized module;
regenerate them from the Vivado project, which is not tracked here.

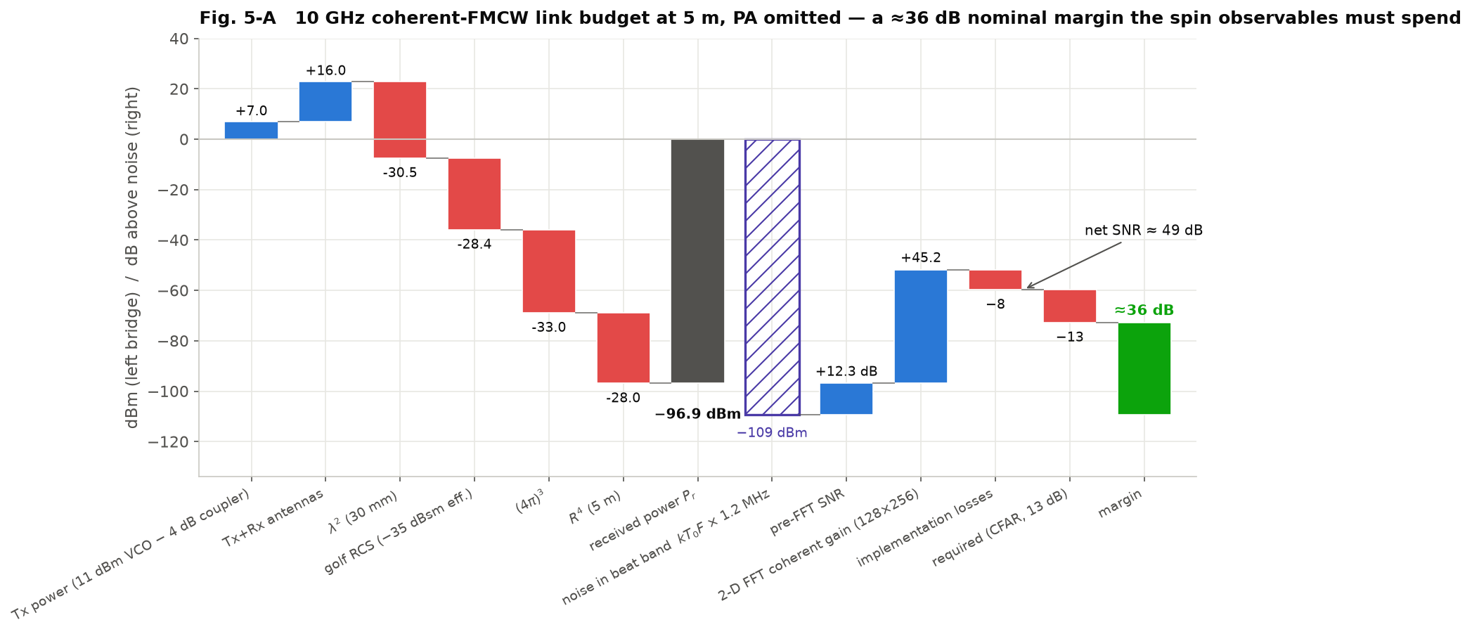
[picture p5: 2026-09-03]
rf_frontend/figures/fig_r5_linkbudget.png

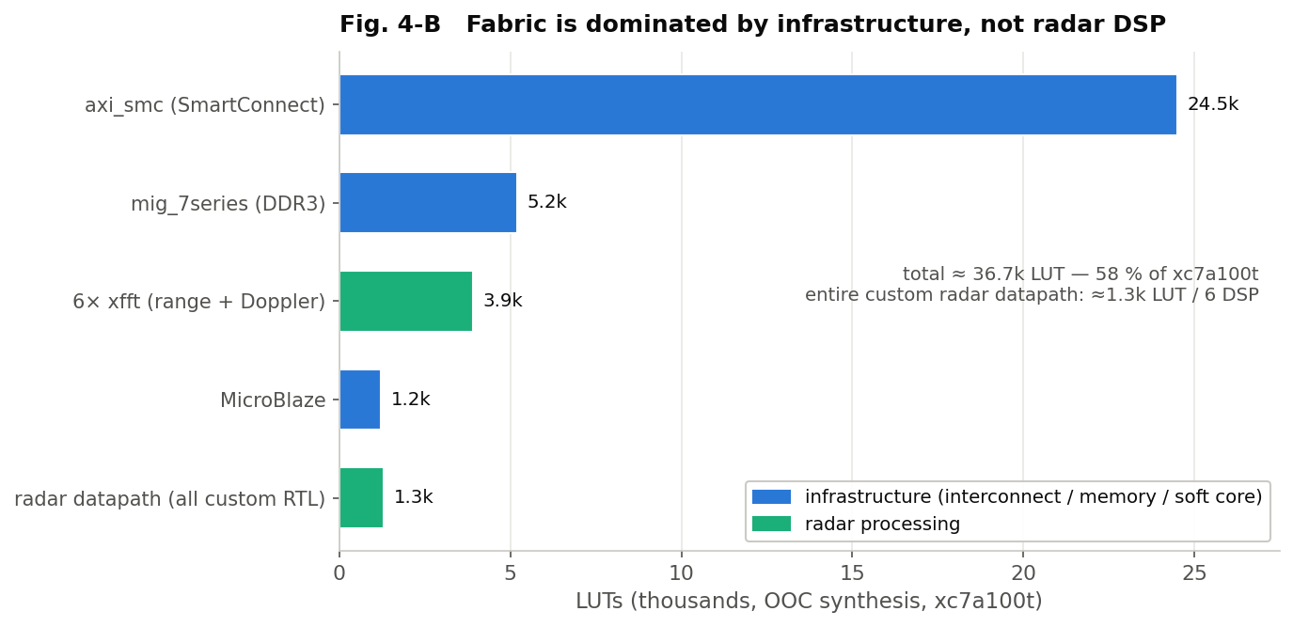
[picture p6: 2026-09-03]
fpga/docs/resource_breakdown.png

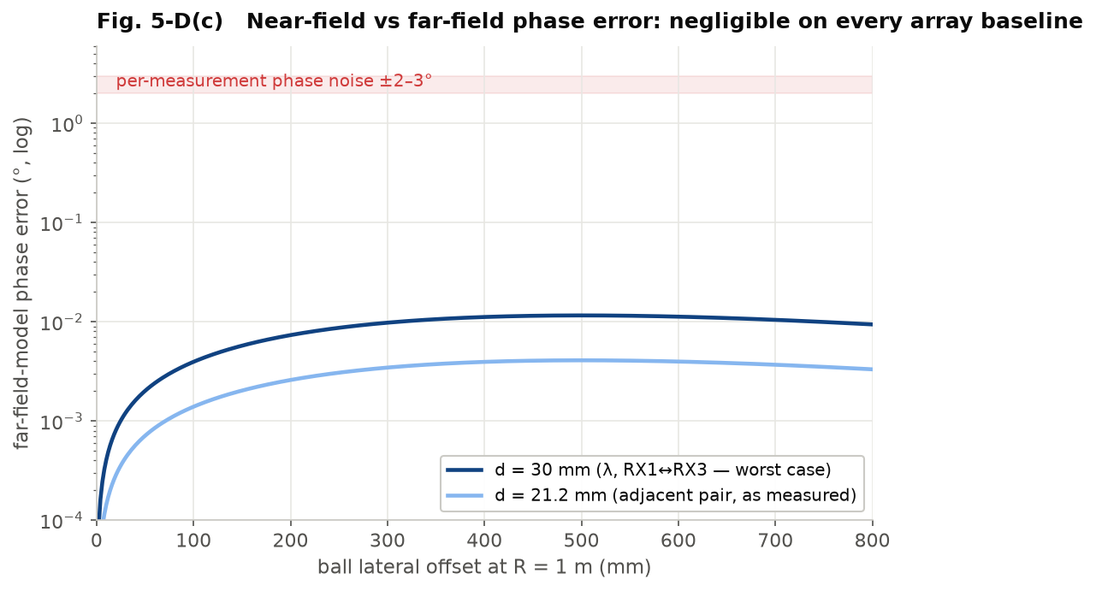
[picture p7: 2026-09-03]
rf_frontend/figures/fig_r5_nearfield.png

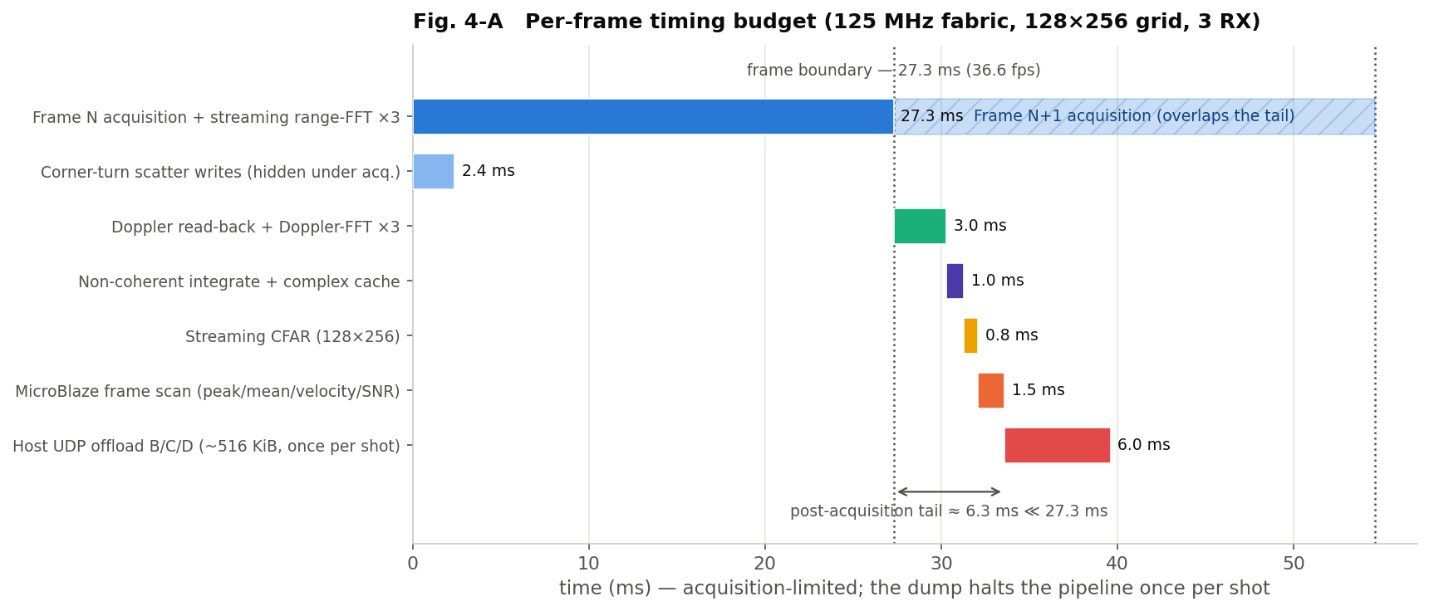
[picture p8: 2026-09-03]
fpga/docs/timing_budget.png

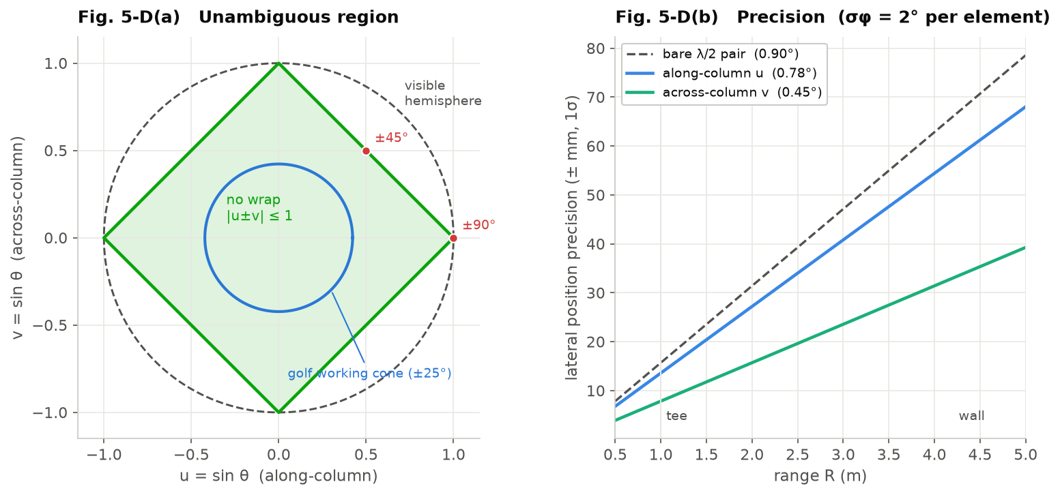
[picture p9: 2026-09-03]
rf_frontend/figures/fig_r5_array_spacing.png

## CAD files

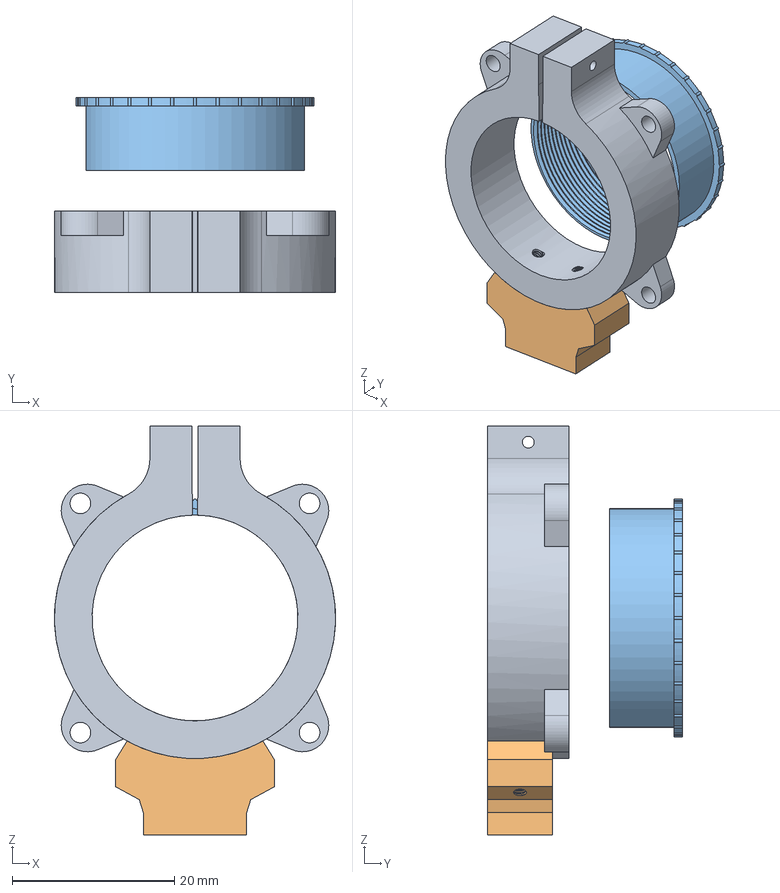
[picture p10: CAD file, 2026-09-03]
carrier_board/mechanical/CS-mount.FCStd
34.7 x 24.0 x 50.5 mm
ring
tripod mount
FlangeAdjustmentRIng

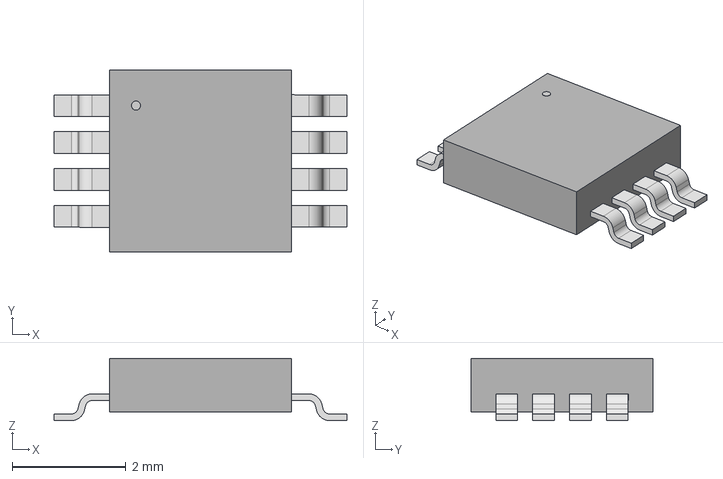
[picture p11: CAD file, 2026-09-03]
rf_frontend/kicad/footprints/ADP1613ARMZ_R7/RM_8_ADI.step
5.16 x 3.20 x 1.09 mm

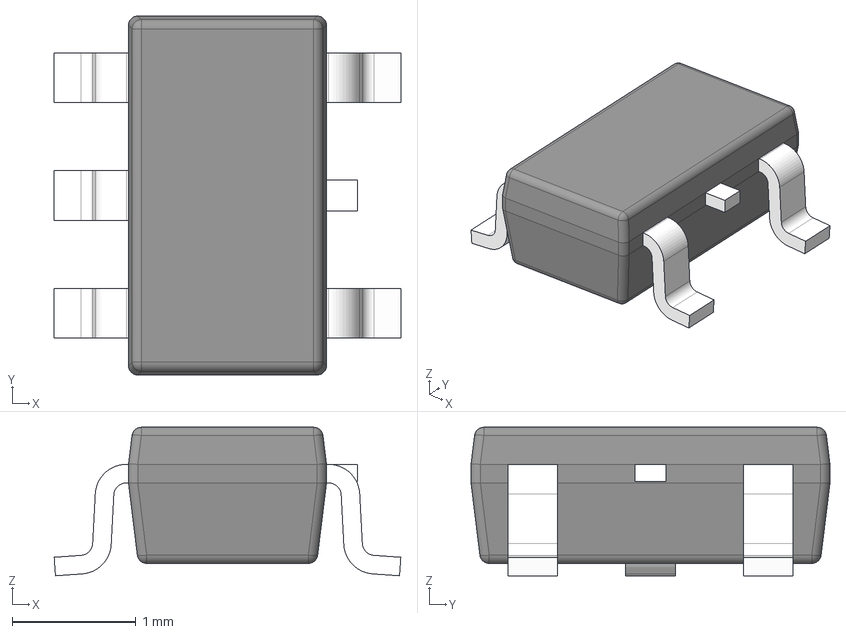
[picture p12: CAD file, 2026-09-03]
rf_frontend/kicad/footprints/SN74LVC1G17DBVR/DBV0005A.stp
2.80 x 2.90 x 1.20 mm
BODY-SOT
LEAD-SOT x 5
LEAD-DUMMY

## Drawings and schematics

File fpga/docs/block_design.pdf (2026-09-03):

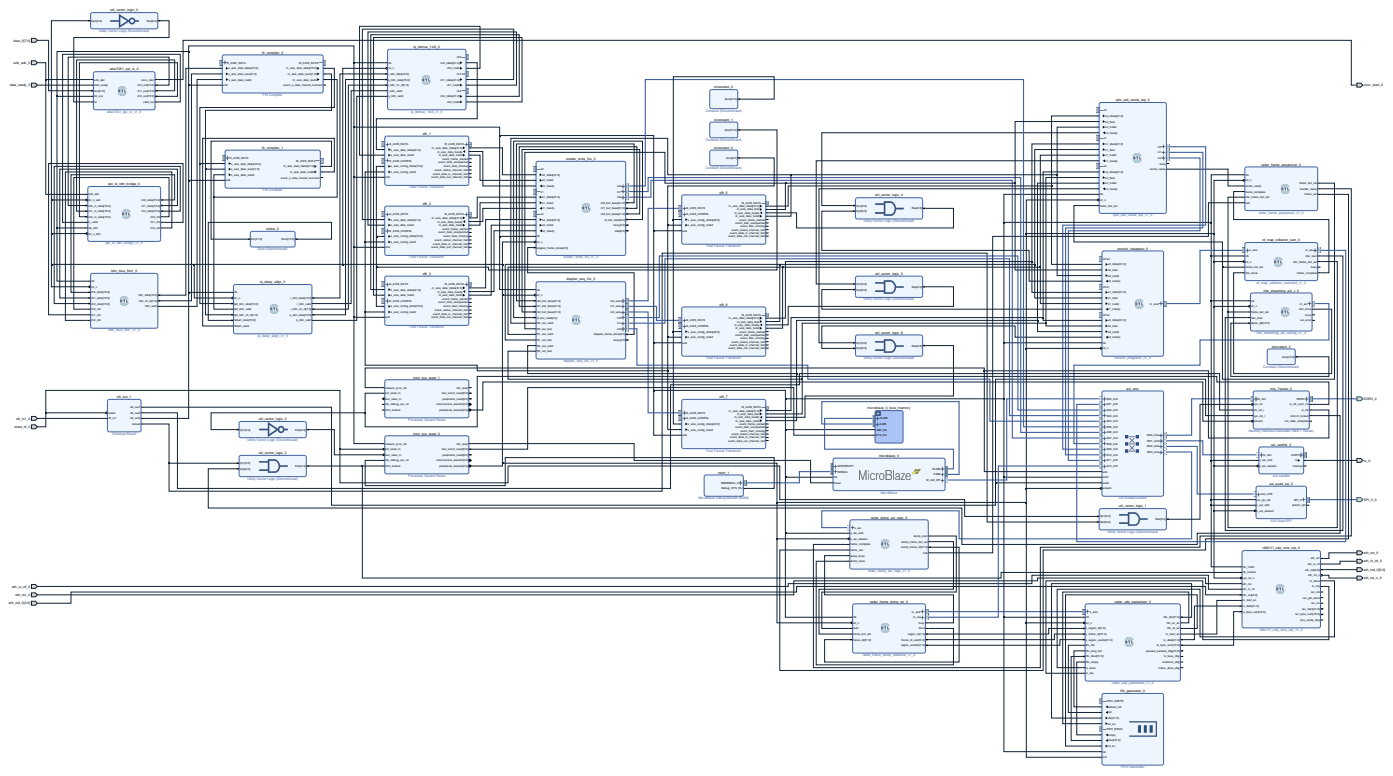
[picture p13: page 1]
DDR3_0; SPI_0_0; adar7251_ppi_rx_0; adar7251_ppi_rx_v1_0; sclk_adc data_ready dout[7:0]; conv_start ch0_out[15:0] ch1_out[15:0] ch2_out[15:0] valid_out clk_sys; rst; axi_quad_spi_0; SPI_0 AXI_LITE ext_spi_clk s_axi_aclk s_axi_aresetn; ip2intc_irpt; axi_smc; AXI SmartConnect; S00_AXI S01_AXI S02_AXI S03_AXI S04_AXI S05_AXI S06_AXI S07_AXI S08_AXI S09_AXI S10_AXI S11_AXI S12_AXI; M00_AXI M01_AXI M02_AXI M03_AXI; aclk aclk1; aclk2 aresetn; axi_uartlite_0; AXI Uartlite; S_AXI; UART; s_axi_aclk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

Utility Vector Logic (Discontinued)

fir_compiler_0 | iq_demux_1to3_0 ch0 clk rst_n ch0_tdata[31:0] ch0_tvalid i_tdm_data[15:0] q_tdm_data[15:0] ch1 ch1_tdata[31:0] ch1_tvalid i_tdm_ch_id[1:0] i_tdm_valid ch2 q_tdm_valid ch2_tdata[31:0] ch2_tvalid

ppi_to_tdm_bridge_0 sclk_adc rst_n_adc ch0_data[15:0] ch1_data[15:0] ch2_data[15:0] ch0_vld ch0_in_data[15:0] ch1_in_data[15:0] ch2_in_data[15:0] in_valid ch1_vld clk_tdm rst_n_tdm ch2_vld ppi_to_tdm_bridge_v1_0 | FIR Compiler | Fast Fourier Transform xfft_2 | xfft_5 | util_vector_logic_4

Fast Fourier Transform

Processor System Reset

Memory Interface Generator (MIG 7 Series)

MicroBlaze Debug Module (MDM)

AXI Quad SPI

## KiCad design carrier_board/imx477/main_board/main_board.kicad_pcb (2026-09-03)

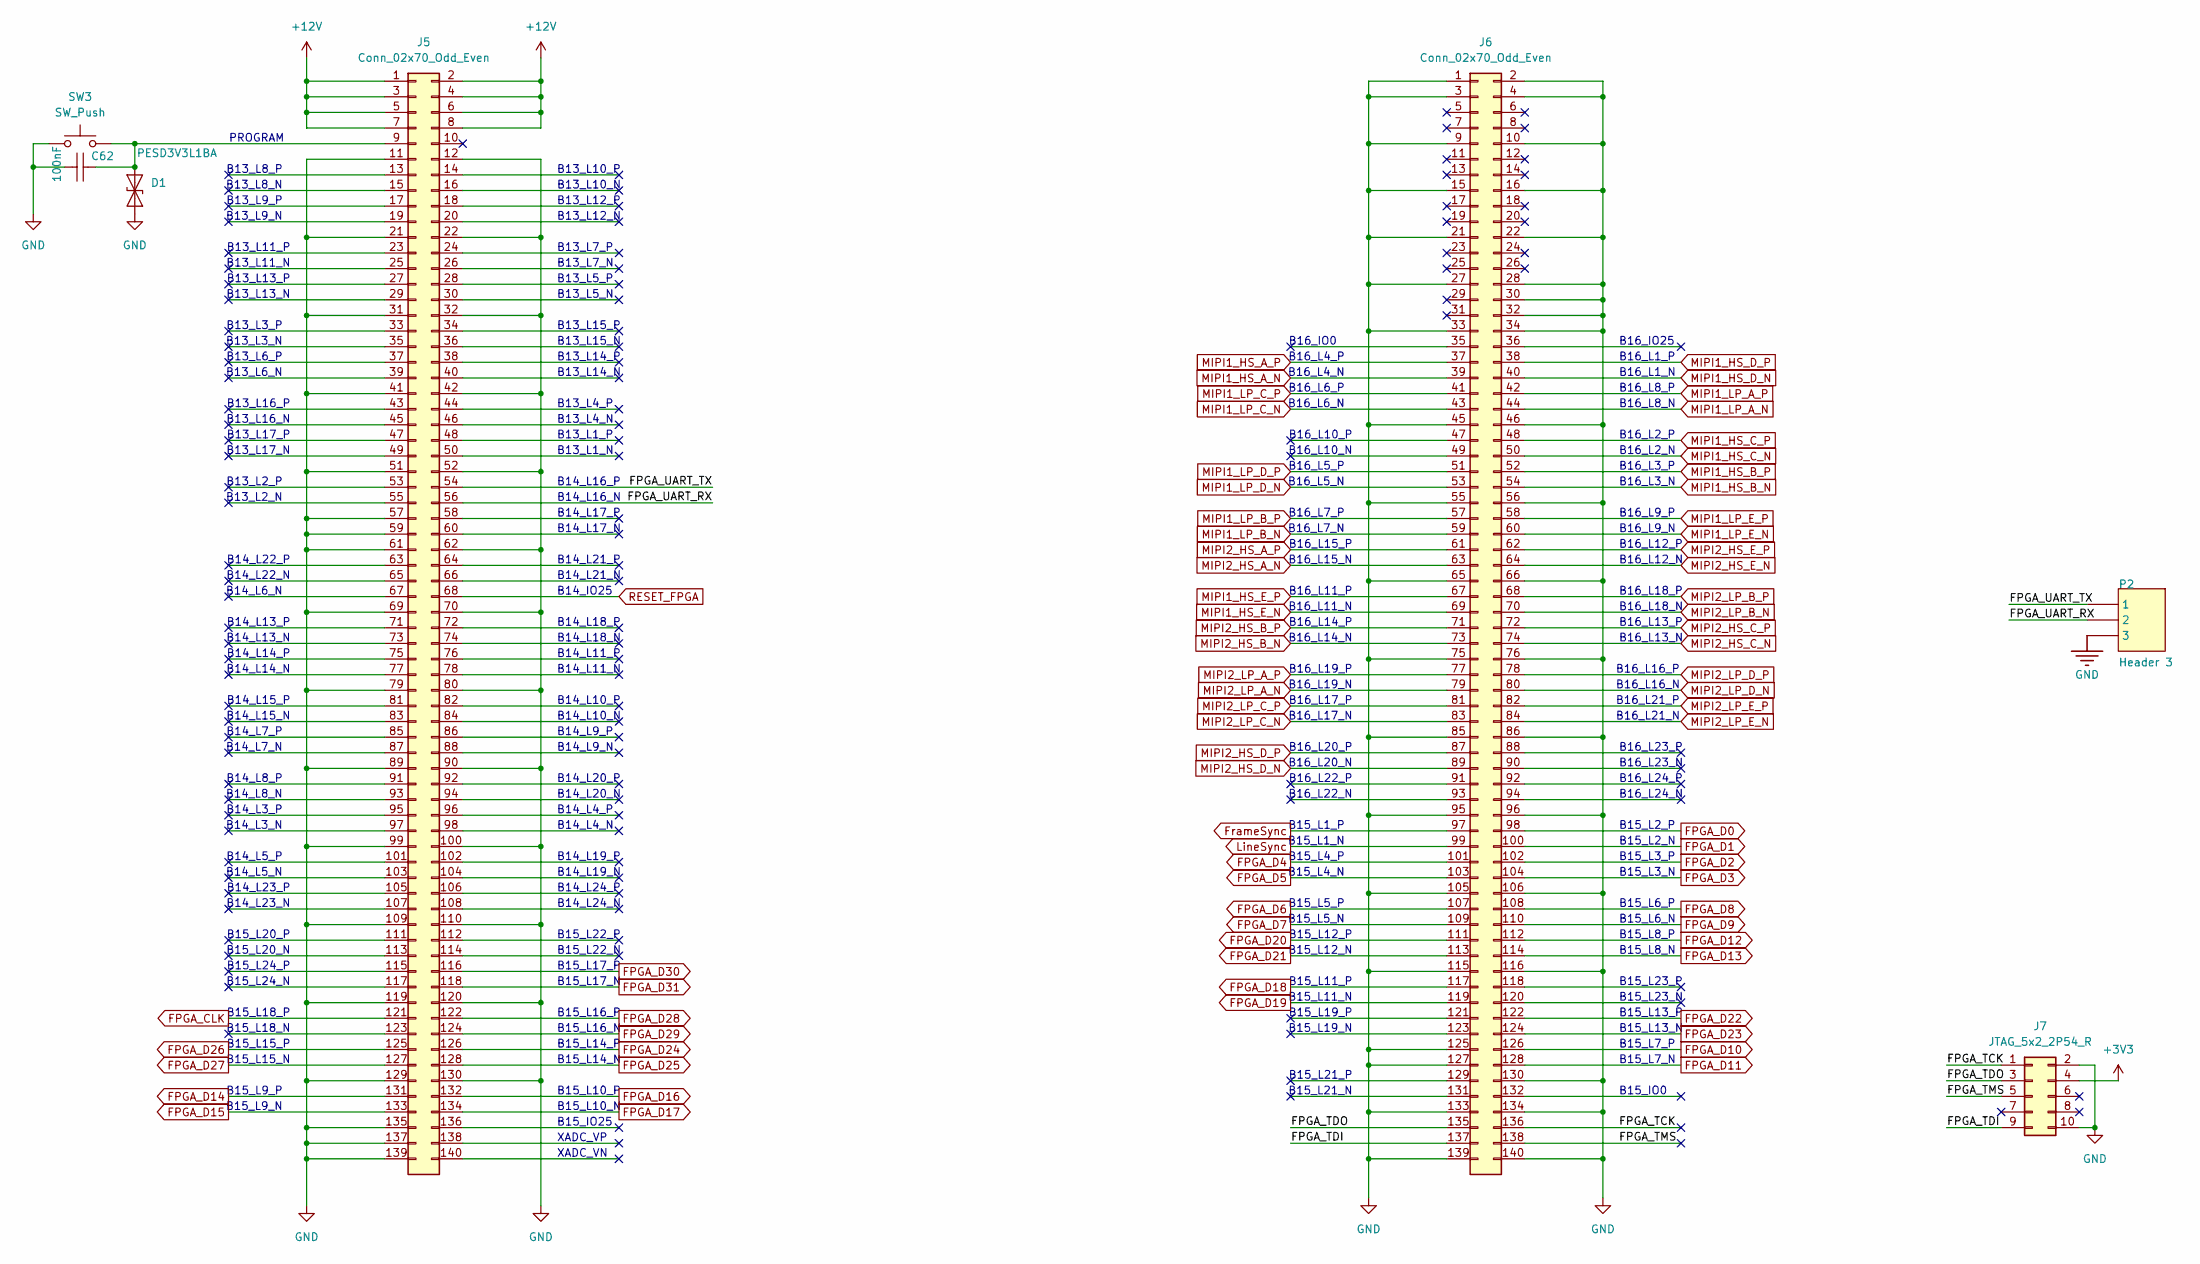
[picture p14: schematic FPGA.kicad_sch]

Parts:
C62: 100nF; C_0603_1608Metric; TOLERANCE ±10%; RATINGS 16V; X7R; MANUFACTURER PART NUMBE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 CC0402KRX7R7BB103
D1: PESD3V3L1BA; D_SOD-323
J5, J6: Conn_02x70_Odd_Even; CONN-SMD_140P-P0.50_B2BM-2X70-0P5_BZOOC
J7: JTAG_5x2_2P54_R; PinHeader_2x05_P2.54mm_Horizontal
P2: Header 3; PinHeader_1x03_P2.54mm_Vertical
SW3: SW_Push; SW_Push_1P1T_NO_CK_KMR2; Part# KMR242NGLFS; LCSC Part # C2804669

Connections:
+3V3: J7.4; also elsewhere on the board
+12V: J5.1, J5.2, J5.3, J5.4, J5.5, J5.6, J5.7, J5.8; also elsewhere on the board
/FPGA/FPGA_TCK: J6.136, J7.1
/FPGA/FPGA_TDI: J6.137, J7.9
/FPGA/FPGA_TDO: J6.135, J7.3
/FPGA/FPGA_TMS: J6.138, J7.5
/FPGA/FPGA_UART_RX: J5.56, P2.2
/FPGA/FPGA_UART_TX: J5.54, P2.1
FPGA_CLK: J5.121; also elsewhere on the board
FPGA_D0: J6.98; also elsewhere on the board
FPGA_D1: J6.100; also elsewhere on the board
FPGA_D2: J6.102; also elsewhere on the board
FPGA_D3: J6.104; also elsewhere on the board
FPGA_D4: J6.101; also elsewhere on the board
FPGA_D5: J6.103; also elsewhere on the board
FPGA_D6: J6.107; also elsewhere on the board
FPGA_D7: J6.109; also elsewhere on the board
FPGA_D8: J6.108; also elsewhere on the board
FPGA_D9: J6.110; also elsewhere on the board
FPGA_D10: J6.126; also elsewhere on the board
FPGA_D11: J6.128; also elsewhere on the board
FPGA_D12: J6.112; also elsewhere on the board
FPGA_D13: J6.114; also elsewhere on the board
FPGA_D14: J5.131; also elsewhere on the board
FPGA_D15: J5.133; also elsewhere on the board
FPGA_D16: J5.132; also elsewhere on the board
FPGA_D17: J5.134; also elsewhere on the board
FPGA_D18: J6.117; also elsewhere on the board
FPGA_D19: J6.119; also elsewhere on the board
FPGA_D20: J6.111; also elsewhere on the board
FPGA_D21: J6.113; also elsewhere on the board
FPGA_D22: J6.122; also elsewhere on the board
FPGA_D23: J6.124; also elsewhere on the board
FPGA_D24: J5.126; also elsewhere on the board
FPGA_D25: J5.128; also elsewhere on the board
FPGA_D26: J5.125; also elsewhere on the board
FPGA_D27: J5.127; also elsewhere on the board
FPGA_D28: J5.122; also elsewhere on the board
FPGA_D29: J5.124; also elsewhere on the board
FPGA_D30: J5.116; also elsewhere on the board
FPGA_D31: J5.118; also elsewhere on the board
FrameSync: J6.97; also elsewhere on the board
GND: C62.2, D1.1 (A1), J5.11, J5.12, J5.21, J5.22, J5.31, J5.32, J5.41, J5.42, J5.51, J5.52, J5.57, J5.59, J5.61, J5.62, J5.69, J5.70, J5.79, J5.80, J5.89, J5.90, J5.99, J5.100, J5.109, J5.110, J5.119, J5.120, J5.129, J5.130, J5.135, J5.137, J5.139, J6.1, J6.2, J6.3, J6.4, J6.9, J6.10, J6.15, J6.16, J6.21, J6.22, J6.27, J6.28, J6.30, J6.32, J6.33, J6.34, J6.45, J6.46, J6.55, J6.56, J6.65, J6.66, J6.75, J6.76, J6.85, J6.86, J6.95, J6.96, J6.105, J6.106, J6.115, J6.116, J6.125, J6.127, J6.130, J6.133, J6.134, J6.139, J6.140, J7.2, J7.10, P2.3, SW3.1; also elsewhere on the board
LineSync: J6.99; also elsewhere on the board
MIPI1_HS_A_N: J6.39; also elsewhere on the board
MIPI1_HS_A_P: J6.37; also elsewhere on the board
MIPI1_HS_B_N: J6.54; also elsewhere on the board
MIPI1_HS_B_P: J6.52; also elsewhere on the board
MIPI1_HS_C_N: J6.50; also elsewhere on the board
MIPI1_HS_C_P: J6.48; also elsewhere on the board
MIPI1_HS_D_N: J6.40; also elsewhere on the board
MIPI1_HS_D_P: J6.38; also elsewhere on the board
MIPI1_HS_E_N: J6.69; also elsewhere on the board
MIPI1_HS_E_P: J6.67; also elsewhere on the board
MIPI1_LP_A_N: J6.44; also elsewhere on the board
MIPI1_LP_A_P: J6.42; also elsewhere on the board
MIPI1_LP_B_N: J6.59; also elsewhere on the board
MIPI1_LP_B_P: J6.57; also elsewhere on the board
MIPI1_LP_C_N: J6.43; also elsewhere on the board
MIPI1_LP_C_P: J6.41; also elsewhere on the board
MIPI1_LP_D_N: J6.53; also elsewhere on the board
MIPI1_LP_D_P: J6.51; also elsewhere on the board
MIPI1_LP_E_N: J6.60; also elsewhere on the board
MIPI1_LP_E_P: J6.58; also elsewhere on the board
MIPI2_HS_A_N: J6.63; also elsewhere on the board
MIPI2_HS_A_P: J6.61; also elsewhere on the board
MIPI2_HS_B_N: J6.73; also elsewhere on the board
MIPI2_HS_B_P: J6.71; also elsewhere on the board
MIPI2_HS_C_N: J6.74; also elsewhere on the board
MIPI2_HS_C_P: J6.72; also elsewhere on the board
MIPI2_HS_D_N: J6.89; also elsewhere on the board
MIPI2_HS_D_P: J6.87; also elsewhere on the board
MIPI2_HS_E_N: J6.64; also elsewhere on the board
MIPI2_HS_E_P: J6.62; also elsewhere on the board
MIPI2_LP_A_N: J6.79; also elsewhere on the board
MIPI2_LP_A_P: J6.77; also elsewhere on the board
MIPI2_LP_B_N: J6.70; also elsewhere on the board
MIPI2_LP_B_P: J6.68; also elsewhere on the board
MIPI2_LP_C_N: J6.83; also elsewhere on the board
MIPI2_LP_C_P: J6.81; also elsewhere on the board
MIPI2_LP_D_N: J6.80; also elsewhere on the board
MIPI2_LP_D_P: J6.78; also elsewhere on the board
MIPI2_LP_E_N: J6.84; also elsewhere on the board
MIPI2_LP_E_P: J6.82; also elsewhere on the board
unnamed: C62.1, D1.2 (A2), J5.9, SW3.2
RESET_FPGA: J5.68; also elsewhere on the board

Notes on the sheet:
B16_L14_N
B14_L24_P
B14_L15_P
B16_L1_P
B14_L22_N
B15_L5_P
B16_L3_P
B16_L13_N
B15_L17_N
B13_L6_P
B16_L21_N
B14_L14_P
B15_L1_N
B13_L2_P
B15_L24_P
B15_L15_P
B14_IO25
B16_L20_P
B14_L18_P
B13_L13_N
B16_L24_N
B15_L7_P
B13_L16_N
B13_L13_P
B15_L11_N
B15_L21_N
B15_L22_P
B15_L20_P
B13_L1_P
B14_L9_P
B13_L4_P
B13_L14_N
B15_L14_P
B15_L24_N
B16_L11_P
B14_L3_P
B15_L8_N
B13_L8_N
B13_L14_P
B15_L23_P

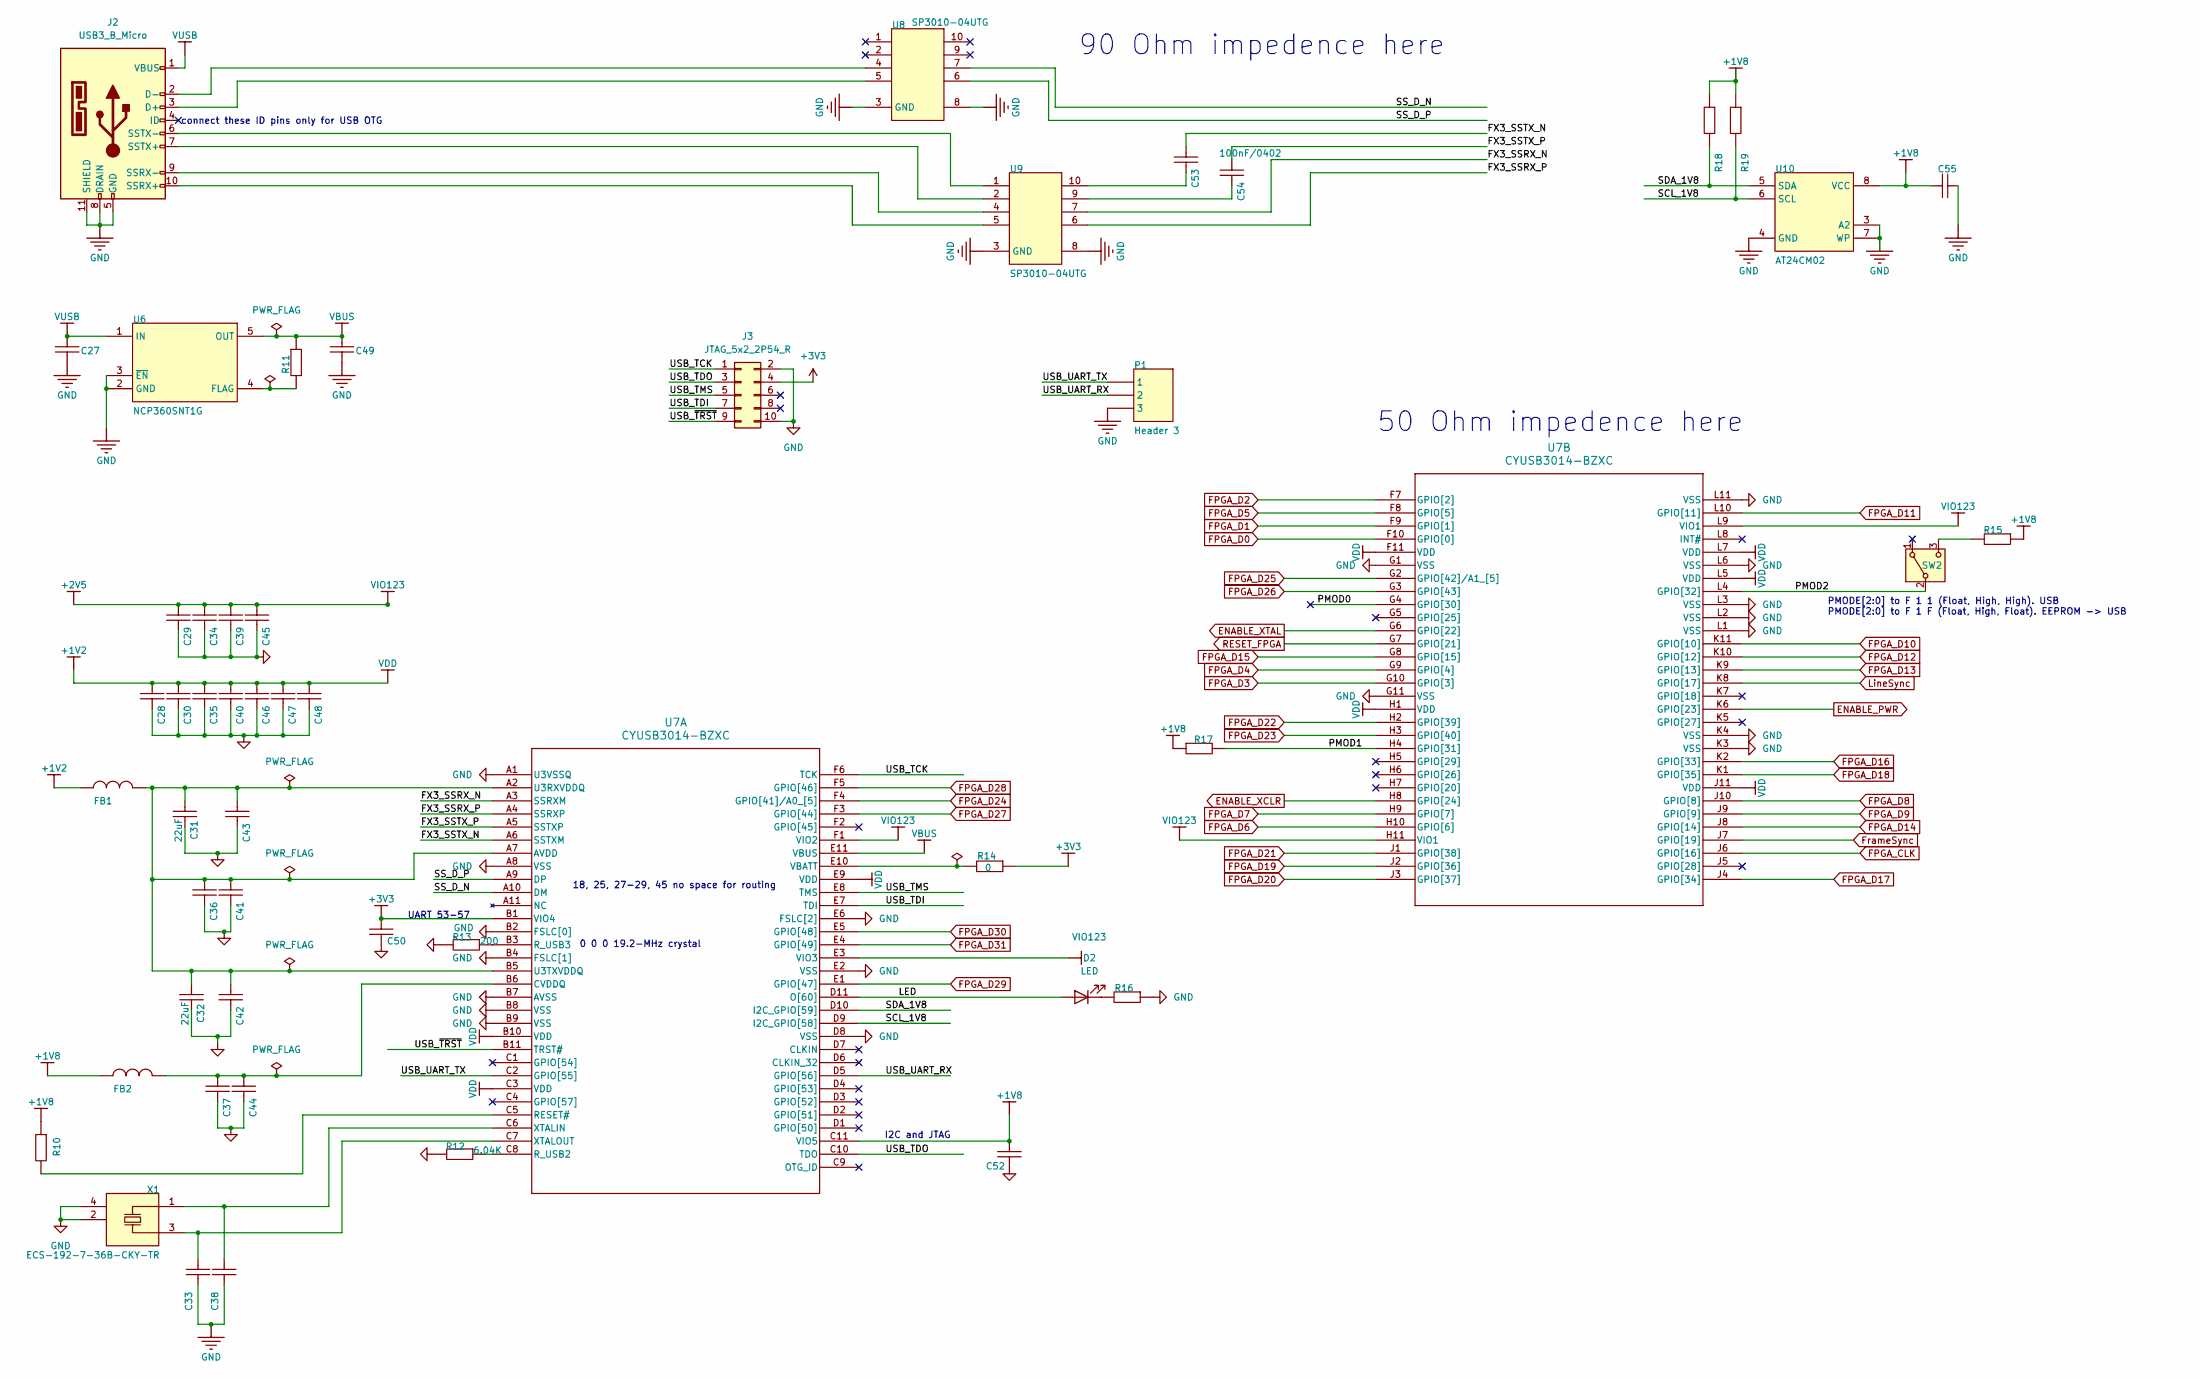
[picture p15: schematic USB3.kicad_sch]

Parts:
C27, C49: 10uF; C_0603_1608Metric; TOLERANCE ±20%; RATINGS 50V; X5R; MANUFACTURER PART NUMBE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 UMK325BJ106MM-T
C28, C29, C30, C33, C34, C35, C36, C37, C38, C39, C40, C42, C43, C44, C45, C46, C47, C48, C50, C52, C55: 100nF; C_0603_1608Metric; TOLERANCE ±10%; RATINGS 16V; X7R; MANUFACTURER PART NUMBE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 CC0402KRX7R7BB103
C31, C32: 22uF; C_0603_1608Metric; RATINGS 50V; NP0; MANUFACTURER PART NUMBE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 06035A561JAT2A
C41: 2.2uF; C_0603_1608Metric; TOLERANCE ±10%; RATINGS 16V; X7R; MANUFACTURER PART NUMBE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 CC0402KRX7R7BB103
C53, C54: 100nF/0402; C_0402_1005Metric; TOLERANCE ±10%; RATINGS 16V; X7R; MANUFACTURER PART NUMBE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 CC0402KRX7R7BB103
D2: LED; LED_0603_1608Metric
FB1, FB2: 100Ω at 100 MHz; L_0805_2012Metric; Part# MPZ2012S101ATD25; LCSC Part # C307776
J2: USB3_B_Micro; USB3_Micro-B_Connfly_DS1104-01
J3: JTAG_5x2_2P54_R; PinHeader_2x05_P2.54mm_Horizontal
P1: Header 3; PinHeader_1x03_P2.54mm_Vertical
R10, R11, R15, R16, R17, R18, R19: 3.3K; R_0603_1608Metric; RATINGS 1/16 W; TOLERANCE ±5%; MANUFACTURER PART NUMBE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 RC0402JR-073K3L
R12: 6.04K; R_0603_1608Metric; RATINGS 1/16 W; TOLERANCE ±5%; MANUFACTURER PART NUMBE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 RC0402JR-073K3L
R13: 200; R_0603_1608Metric; RATINGS 1/16 W; TOLERANCE ±5%; MANUFACTURER PART NUMBE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 RC0402JR-073K3L
R14: 0; R_0603_1608Metric; RATINGS 1/16 W; TOLERANCE ±5%; MANUFACTURER PART NUMBE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 RC0402JR-073K3L
SW2: SW_SPDT; SW_SPDT_CK_JS102011SAQN; Part# JS102011SAQN; LCSC Part # C221660
U6: NCP360SNT1G; TSOP5_3X1P5_ONS; Part# NCP360SNT1G; LCSC Part # C603707
U7: CYUSB3014-BZXC; PG-TFBGA-121-800_INF
U8, U9: SP3010-04UTG; Diodes_UDFN-10_1.0x2.5mm_P0.5mm; Part# SP3010-04UTG; LCSC Part # C126837
U10: AT24CM02; SOIC-8-1EP_3.9x4.9mm_P1.27mm_EP2.29x3mm; Part# AT24CM02-SSHM-T; LCSC Part # C779670
X1: ECS-192-7-36B-CKY-TR; Oscillator_SMD_ECS_2520MV-xxx-xx-4Pin_2.5x2.0mm; Part# ECS ECS-192-7-36B-CKY-TR; LCSC Part # C2450510

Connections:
+1V2: C28.2, C30.2, C35.2, C40.2, C46.2, C47.2, C48.2, FB1.1, U7.B10 (VDD), U7.C3 (VDD), U7.E9 (VDD), U7.F11 (VDD), U7.H1 (VDD), U7.J11 (VDD), U7.L5 (VDD), U7.L7 (VDD); also elsewhere on the board
+1V8: C52.2, C55.2, FB2.1, R10.1, R15.2, R17.2, R18.1, R19.1, U7.C11 (VIO5), U10.8 (VCC); also elsewhere on the board
+2V5: C29.2, C34.2, C39.2, C45.2, U7.E3 (VIO3), U7.F1 (VIO2), U7.H11 (VIO1), U7.L9 (VIO1); also elsewhere on the board
+3V3: C50.2, J3.4, R14.2, U7.B1 (VIO4); also elsewhere on the board
/USB3/FX3_SSRX_N: U7.A3 (SSRXM), U9.7
/USB3/FX3_SSRX_P: U7.A4 (SSRXP), U9.6
/USB3/FX3_SSTX_N: C53.2, U7.A6 (SSTXM)
/USB3/FX3_SSTX_P: C54.2, U7.A5 (SSTXP)
/USB3/LED: D2.2 (A), U7.D11 (O[60])
/USB3/PMOD0: U7.G4 (GPIO[30])
/USB3/PMOD1: R17.1, U7.H4 (GPIO[31])
/USB3/PMOD2: SW2.2 (B), U7.L4 (GPIO[32])
/USB3/SCL_1V8: R19.2, U7.D9 (I2C_GPIO[58]), U10.6 (SCL)
/USB3/SDA_1V8: R18.2, U7.D10 (I2C_GPIO[59]), U10.5 (SDA)
/USB3/SS_D_N: U7.A10 (DM), U8.7
/USB3/SS_D_P: U7.A9 (DP), U8.6
/USB3/USB_TCK: J3.1, U7.F6 (TCK)
/USB3/USB_TDI: J3.7, U7.E7 (TDI)
/USB3/USB_TDO: J3.3, U7.C10 (TDO)
/USB3/USB_TMS: J3.5, U7.E8 (TMS)
/USB3/USB_UART_RX: P1.2, U7.D5 (GPIO[56])
/USB3/USB_UART_TX: P1.1, U7.C2 (GPIO[55])
/USB3/USB_~TRST: J3.9, U7.B11 (TRST#)
ENABLE_PWR: U7.K6 (GPIO[23]); also elsewhere on the board
ENABLE_XCLR: U7.H8 (GPIO[24]); also elsewhere on the board
ENABLE_XTAL: U7.G6 (GPIO[22]); also elsewhere on the board
FPGA_CLK: U7.J6 (GPIO[16]); also elsewhere on the board
FPGA_D0: U7.F10 (GPIO[0]); also elsewhere on the board
FPGA_D1: U7.F9 (GPIO[1]); also elsewhere on the board
FPGA_D2: U7.F7 (GPIO[2]); also elsewhere on the board
FPGA_D3: U7.G10 (GPIO[3]); also elsewhere on the board
FPGA_D4: U7.G9 (GPIO[4]); also elsewhere on the board
FPGA_D5: U7.F8 (GPIO[5]); also elsewhere on the board
FPGA_D6: U7.H10 (GPIO[6]); also elsewhere on the board
FPGA_D7: U7.H9 (GPIO[7]); also elsewhere on the board
FPGA_D8: U7.J10 (GPIO[8]); also elsewhere on the board
FPGA_D9: U7.J9 (GPIO[9]); also elsewhere on the board
FPGA_D10: U7.K11 (GPIO[10]); also elsewhere on the board
FPGA_D11: U7.L10 (GPIO[11]); also elsewhere on the board
FPGA_D12: U7.K10 (GPIO[12]); also elsewhere on the board
FPGA_D13: U7.K9 (GPIO[13]); also elsewhere on the board
FPGA_D14: U7.J8 (GPIO[14]); also elsewhere on the board
FPGA_D15: U7.G8 (GPIO[15]); also elsewhere on the board
FPGA_D16: U7.K2 (GPIO[33]); also elsewhere on the board
FPGA_D17: U7.J4 (GPIO[34]); also elsewhere on the board
FPGA_D18: U7.K1 (GPIO[35]); also elsewhere on the board
FPGA_D19: U7.J2 (GPIO[36]); also elsewhere on the board
FPGA_D20: U7.J3 (GPIO[37]); also elsewhere on the board
FPGA_D21: U7.J1 (GPIO[38]); also elsewhere on the board
FPGA_D22: U7.H2 (GPIO[39]); also elsewhere on the board
FPGA_D23: U7.H3 (GPIO[40]); also elsewhere on the board
FPGA_D24: U7.F4 (GPIO[41]/A0_[5]); also elsewhere on the board
FPGA_D25: U7.G2 (GPIO[42]/A1_[5]); also elsewhere on the board
FPGA_D26: U7.G3 (GPIO[43]); also elsewhere on the board
FPGA_D27: U7.F3 (GPIO[44]); also elsewhere on the board
FPGA_D28: U7.F5 (GPIO[46]); also elsewhere on the board
FPGA_D29: U7.E1 (GPIO[47]); also elsewhere on the board
FPGA_D30: U7.E5 (GPIO[48]); also elsewhere on the board
FPGA_D31: U7.E4 (GPIO[49]); also elsewhere on the board
FrameSync: U7.J7 (GPIO[19]); also elsewhere on the board
GND: C27.2, C28.1, C29.1, C30.1, C31.2, C32.2, C33.2, C34.1, C35.1, C36.1, C37.1, C38.2, C39.1, C40.1, C41.1, C42.1, C43.1, C44.1, C45.1, C46.1, C47.1, C48.1, C49.2, C50.1, C52.1, C55.1, J2.5 (GND), J2.8 (DRAIN), J2.11 (SHIELD), J3.2, J3.10, P1.3, R12.1, R13.1, R16.2, U6.2 (GND), U6.3 (~EN), U7.A1 (U3VSSQ), U7.A8 (VSS), U7.B2 (FSLC[0]), U7.B4 (FSLC[1]), U7.B7 (AVSS), U7.B8 (VSS), U7.B9 (VSS), U7.D8 (VSS), U7.E2 (VSS), U7.E6 (FSLC[2]), U7.G1 (VSS), U7.G11 (VSS), U7.K3 (VSS), U7.K4 (VSS), U7.L1 (VSS), U7.L2 (VSS), U7.L3 (VSS), U7.L6 (VSS), U7.L11 (VSS), U8.3 (GND), U8.8 (GND), U9.3 (GND), U9.8 (GND), U10.3 (A2), U10.4 (GND), U10.7 (WP), X1.2 (NC), X1.4 (NC); also elsewhere on the board
LineSync: U7.K8 (GPIO[17]); also elsewhere on the board
unnamed: C53.1, U9.10
unnamed: C54.1, U9.9
unnamed: D2.1 (K), R16.1
unnamed: J2.3 (D+), U8.5
unnamed: J2.2 (D-), U8.4
unnamed: J2.10 (SSRX+), U9.5
unnamed: J2.9 (SSRX-), U9.4
unnamed: J2.7 (SSTX+), U9.2
unnamed: J2.6 (SSTX-), U9.1
unnamed: R15.1, SW2.3 (C)
unnamed: R11.1, U6.4 (FLAG)
unnamed: C31.1, C32.1, C36.2, C41.2, C42.2, C43.2, FB1.2, U7.A2 (U3RXVDDQ), U7.A7 (AVDD), U7.B5 (U3TXVDDQ)
unnamed: C37.2, C44.2, FB2.2, U7.B6 (CVDDQ)
unnamed: R10.2, U7.C5 (RESET#)
unnamed: R12.2, U7.C8 (R_USB2)
unnamed: R13.2, U7.B3 (R_USB3)
unnamed: R14.1, U7.E10 (VBATT)
unnamed: C38.1, U7.C6 (XTALIN), X1.1 (X1)
unnamed: C33.1, U7.C7 (XTALOUT), X1.3 (X2)
RESET_FPGA: U7.G7 (GPIO[21]); also elsewhere on the board
VBUS: C49.1, R11.2, U6.5 (OUT), U7.E11 (VBUS)
VUSB: C27.1, J2.1 (VBUS), U6.1 (IN)

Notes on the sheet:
0 0 0 19.2-MHz crystal
UART 53-57
connect these ID pins only for USB OTG
I2C and JTAG
18, 25, 27-29, 45 no space for routing
90 Ohm impedence here
PMODE[2:0] to F 1 1 (Float, High, High). USB PMODE[2:0] to F 1 F (Float, High, Float). EEPROM -> USB
50 Ohm impedence here

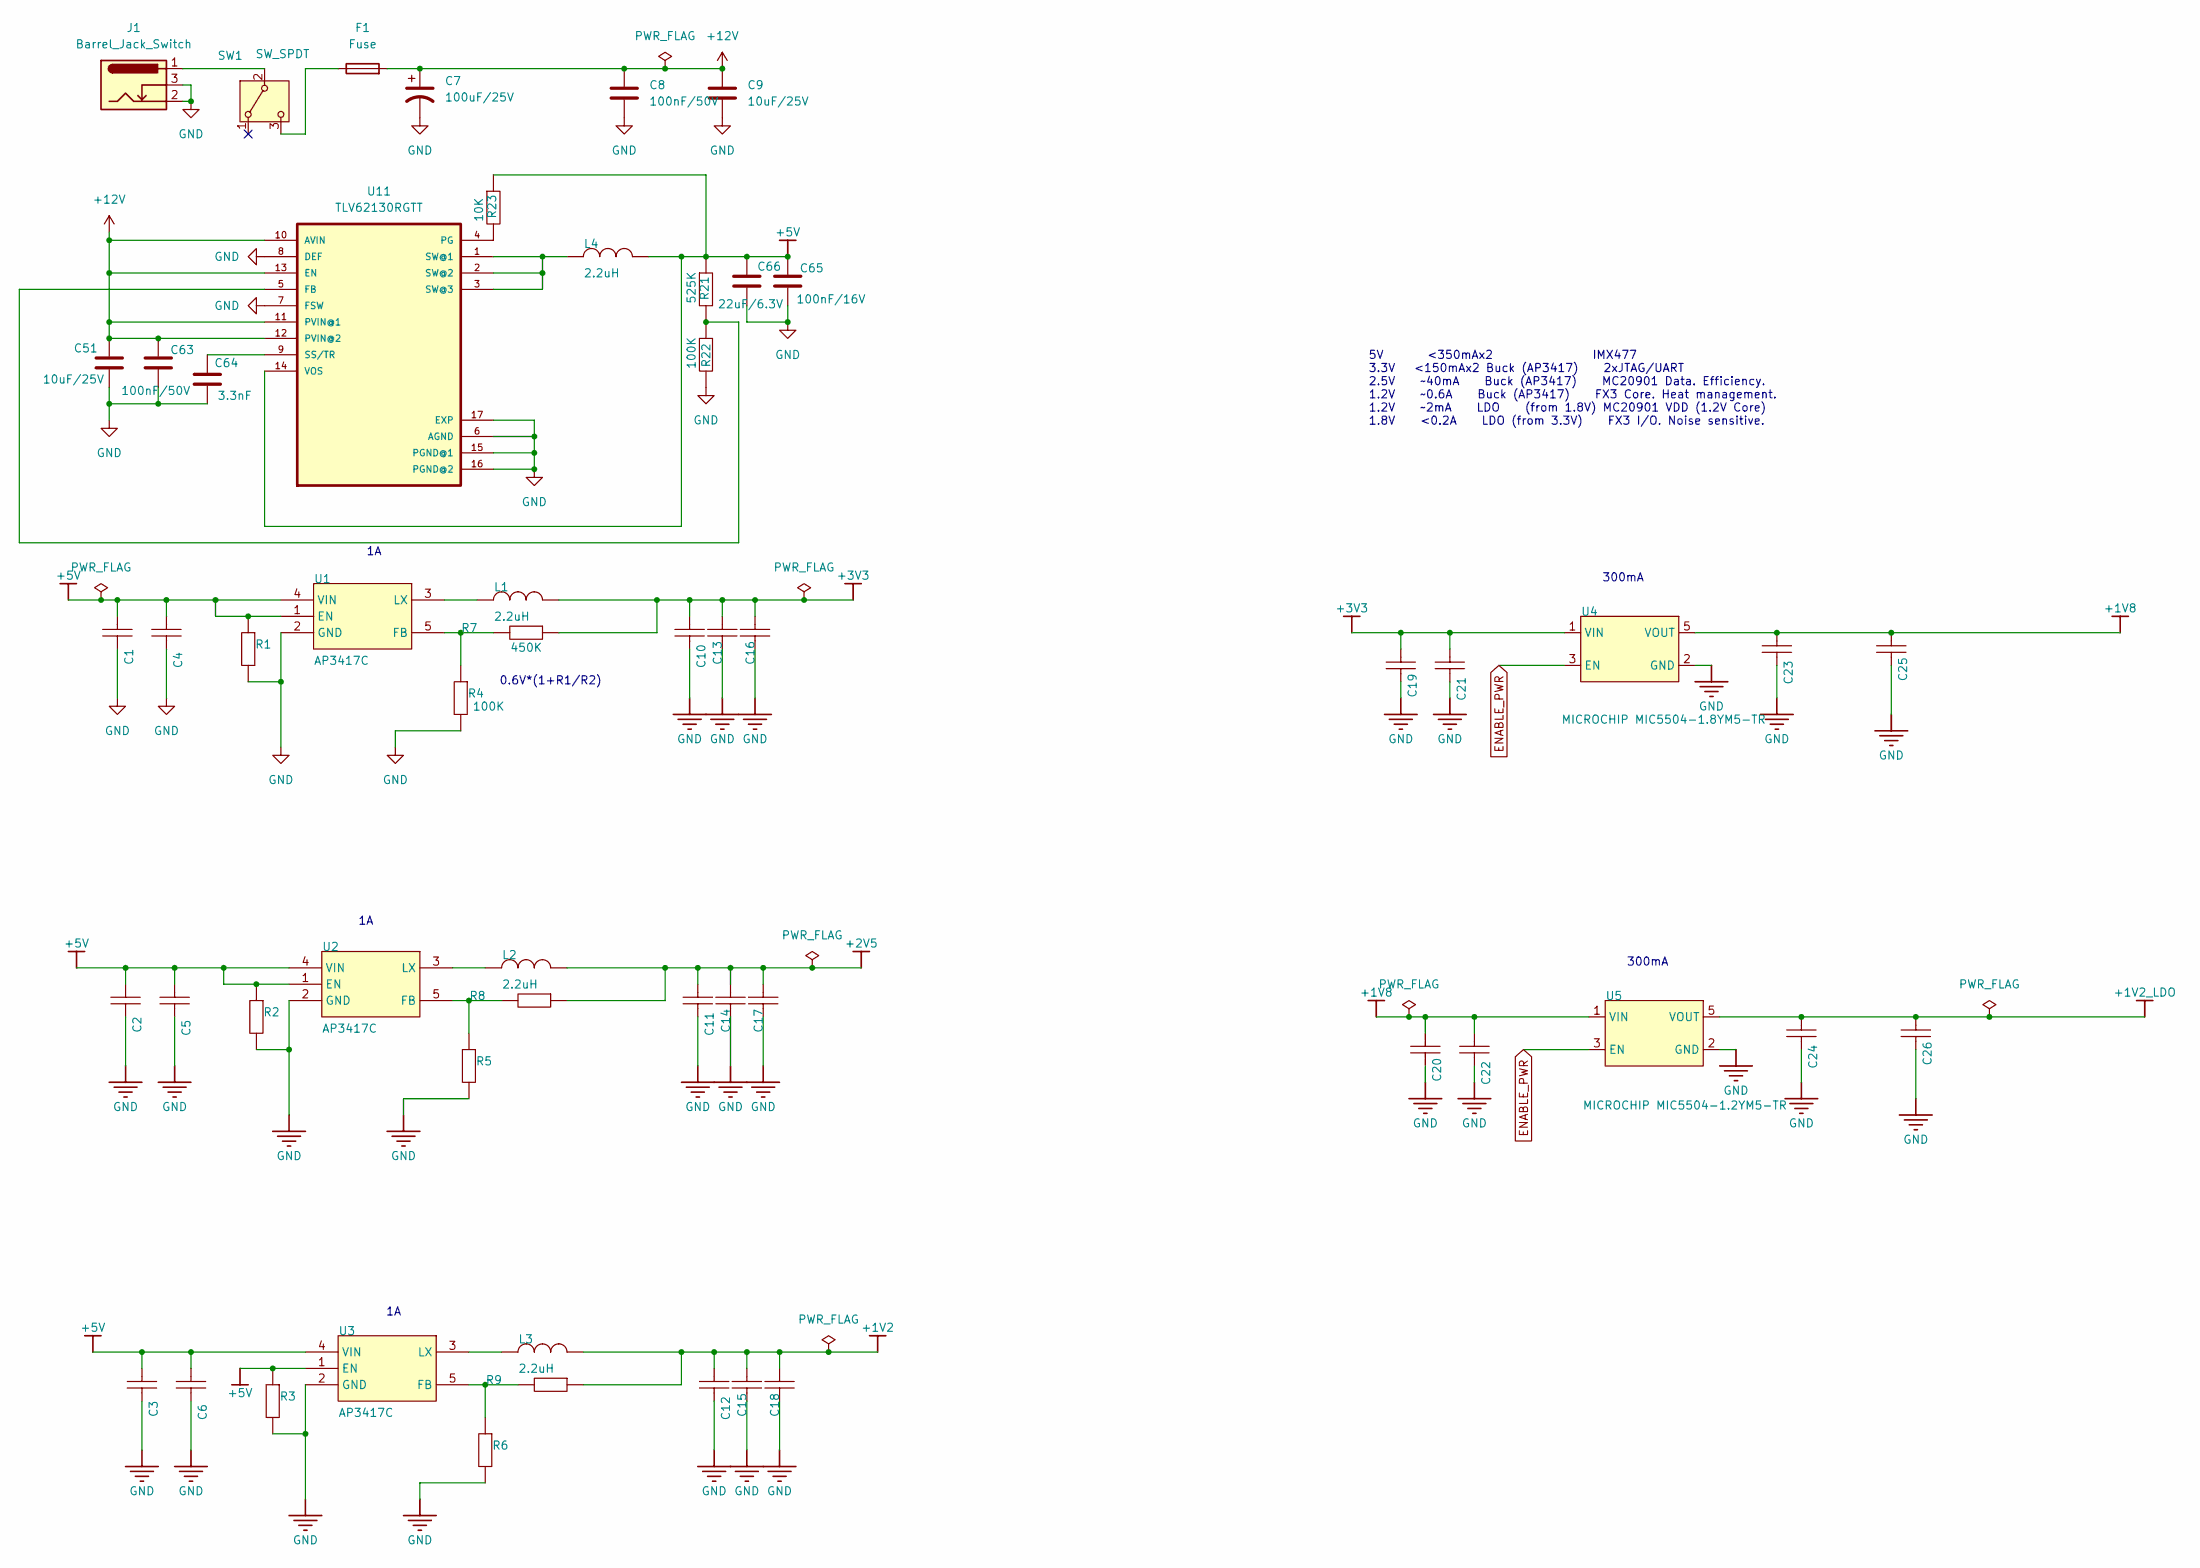
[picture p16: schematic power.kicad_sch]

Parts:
C1, C2, C3, C19, C20, C25, C26: 10uF; C_0603_1608Metric; RATINGS 50V; NP0; MANUFACTURER PART NUMBE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 06035A561JAT2A
C4, C5, C6, C10, C11, C12, C21, C22, C23, C24: 100nF; C_0603_1608Metric; TOLERANCE ±10%; RATINGS 16V; X7R; MANUFACTURER PART NUMBE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 CC0402KRX7R7BB103
C7: 100uF/25V; CP_Elec_6.3x5.7
C8, C63: 100nF/50V; C_0603_1608Metric
C9, C51: 10uF/25V; C_0603_1608Metric
C13, C14, C15, C16, C17, C18: 10uF; C_0603_1608Metric; TOLERANCE ±10%; RATINGS 16V; X5R; MANUFACTURER PART NUMBE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 EMK212BJ475KG-T
C64: 3.3nF; C_0603_1608Metric
C65: 100nF/16V; C_0603_1608Metric
C66: 22uF/6.3V; C_0603_1608Metric
F1: Fuse; Fuse_1812_4532Metric; Part# SMD1812P200TF16; LCSC Part # C20812
J1: Barrel_Jack_Switch; BarrelJack_CLIFF_FC681465S_SMT_Horizontal; Part# TBD
L1, L2, L3, L4: 2.2uH; L_Taiyo-Yuden_MD-4040; Part# CMLO0420H2R2MTT; LCSC Part # C438930
R1, R2, R3, R23: 10K; R_0603_1608Metric; RATINGS 1/16 W; TOLERANCE ±5%; MANUFACTURER PART NUMBE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 RC0402JR-073K3L
R4, R5, R6, R9, R22: 100K; R_0603_1608Metric; RATINGS 1/16 W; TOLERANCE ±5%; MANUFACTURER PART NUMBE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 RC0402JR-073K3L
R7: 450K; R_0603_1608Metric; RATINGS 1/16 W; TOLERANCE ±5%; MANUFACTURER PART NUMBE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 RC0402JR-073K3L
R8: 320K; R_0603_1608Metric; RATINGS 1/16 W; TOLERANCE ±5%; MANUFACTURER PART NUMBE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 RC0402JR-073K3L
R21: 525K; R_0603_1608Metric; RATINGS 1/16 W; TOLERANCE ±5%; MANUFACTURER PART NUMBE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 RC0402JR-073K3L
SW1: SW_SPDT; SW_SPDT_CK_JS102011SAQN; Part# JS102011SAQN; LCSC Part # C221660
U1, U2, U3: AP3417C; SOT-23-5; Part# AP3417CKTR-G1; LCSC Part # C500759
U4: MICROCHIP MIC5504-1.8YM5-TR; SOT-23-5; Part# MIC5504-1.8YM5-TR; LCSC Part # C626116
U5: MICROCHIP MIC5504-1.2YM5-TR; SOT-23-5; Part# MIC5504-1.8YM5-TR; LCSC Part # C626116
U11: TLV62130RGTT; VQFN-16-1EP_3x3mm_P0.5mm_EP1.6x1.6mm; DigiKey_Part_Number 296-32407-1-ND

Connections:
+1V2: C12.2, C15.1, C18.1, L3.2, R9.2; also elsewhere on the board
+1V2_LDO: C24.2, C26.1, U5.5 (VOUT); also elsewhere on the board
+1V8: C20.1, C22.2, C23.2, C25.1, U4.5 (VOUT), U5.1 (VIN); also elsewhere on the board
+2V5: C11.2, C14.1, C17.1, L2.2, R8.2; also elsewhere on the board
+3V3: C10.2, C13.1, C16.1, C19.1, C21.2, L1.2, R7.2, U4.1 (VIN); also elsewhere on the board
+5V: C1.1, C2.1, C3.1, C4.2, C5.2, C6.2, C65.1, C66.1, L4.2, R1.2, R2.2, R3.2, R21.2, R23.2, U1.1 (EN), U1.4 (VIN), U2.1 (EN), U2.4 (VIN), U3.1 (EN), U3.4 (VIN), U11.14 (VOS); also elsewhere on the board
+12V: C7.1, C8.1, C9.1, C51.1, C63.1, F1.2, U11.10 (AVIN), U11.11 (PVIN@1), U11.12 (PVIN@2), U11.13 (EN); also elsewhere on the board
ENABLE_PWR: U4.3 (EN), U5.3 (EN); also elsewhere on the board
GND: C1.2, C2.2, C3.2, C4.1, C5.1, C6.1, C7.2, C8.2, C9.2, C10.1, C11.1, C12.1, C13.2, C14.2, C15.2, C16.2, C17.2, C18.2, C19.2, C20.2, C21.1, C22.1, C23.1, C24.1, C25.2, C26.2, C51.2, C63.2, C64.2, C65.2, C66.2, J1.2, J1.3, R1.1, R2.1, R3.1, R4.1, R5.1, R6.1, R22.1, U1.2 (GND), U2.2 (GND), U3.2 (GND), U4.2 (GND), U5.2 (GND), U11.6 (AGND), U11.7 (FSW), U11.8 (DEF), U11.15 (PGND@1), U11.16 (PGND@2), U11.17 (EXP); also elsewhere on the board
unnamed: J1.1, SW1.2 (B)
unnamed: F1.1, SW1.3 (C)
unnamed: R4.2, R7.1, U1.5 (FB)
unnamed: L1.1, U1.3 (LX)
unnamed: R5.2, R8.1, U2.5 (FB)
unnamed: L2.1, U2.3 (LX)
unnamed: R6.2, R9.1, U3.5 (FB)
unnamed: L3.1, U3.3 (LX)
unnamed: R21.1, R22.2, U11.5 (FB)
unnamed: R23.1, U11.4 (PG)
unnamed: C64.1, U11.9 (SS/TR)
unnamed: L4.1, U11.1 (SW@1), U11.2 (SW@2), U11.3 (SW@3)

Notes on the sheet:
300mA
0.6V*(1+R1/R2)
5V <350mAx2 IMX477 3.3V <150mAx2 Buck (AP3417) 2xJTAG/UART 2.5V ~40mA Buck (AP3417) MC20901 Data. Efficiency. 1.2V ~0.6A Buck (AP3417) FX3 Core. Heat management. 1.2V ~2mA LDO (from 1.8V) MC20901 VDD (1.2V Core) 1.8V <0.2A LDO (from 3.3V) FX3 I/O. Noise sensitive.

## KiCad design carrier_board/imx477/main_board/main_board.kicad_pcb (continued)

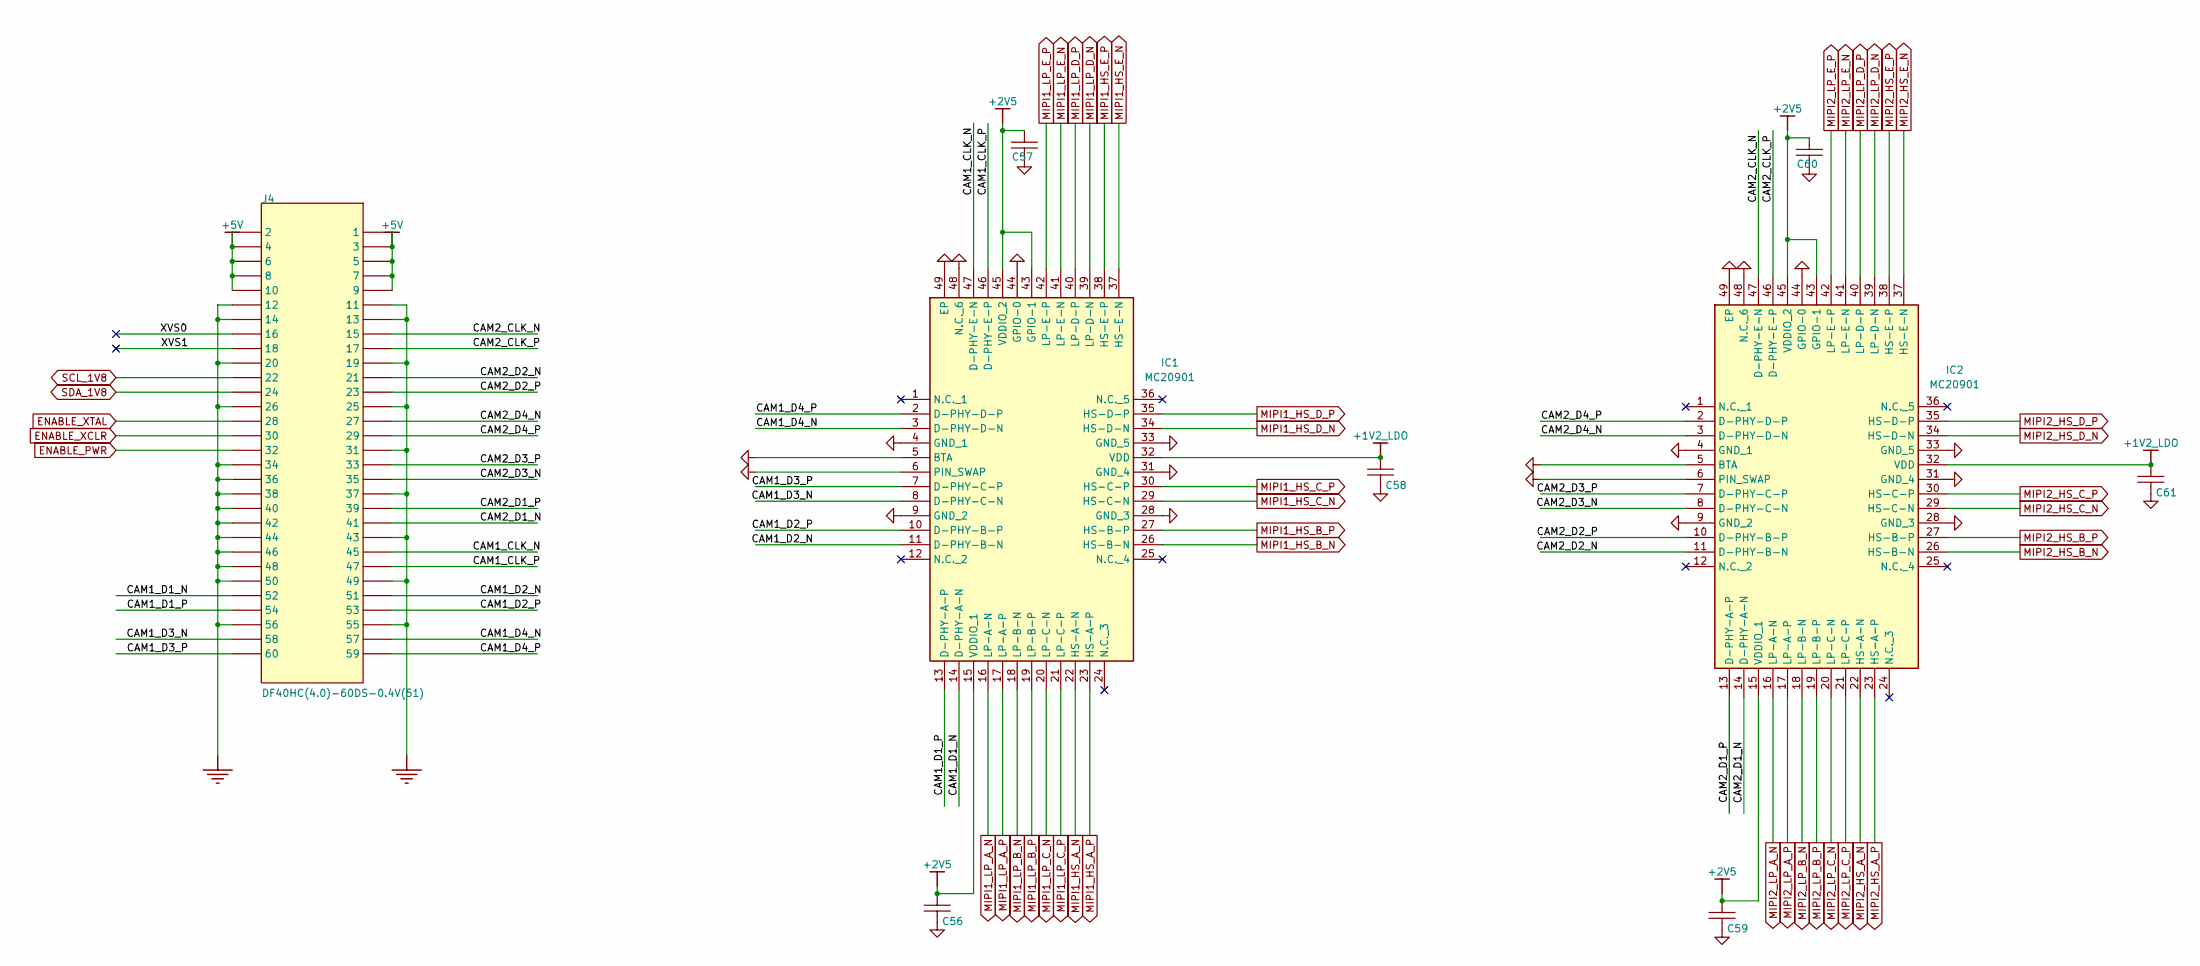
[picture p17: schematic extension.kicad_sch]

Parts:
C56, C57, C58, C59, C60, C61: 100nF; C_0603_1608Metric; TOLERANCE ±10%; RATINGS 16V; X7R; MANUFACTURER PART NUMBE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 CC0402KRX7R7BB103
IC1, IC2: MC20901; QFN50P700X700X80-49N-D; Manufacturer_Part_Number MC20901
J4: DF40HC(4.0)-60DS-0.4V(51); Hirose_DF40HC(4.0)-60DS-0.4V_2x30_P0.4mm

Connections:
+1V2_LDO: C58.2, C61.2, IC1.32 (VDD), IC2.32 (VDD); also elsewhere on the board
+2V5: C56.2, C57.2, C59.2, C60.2, IC1.15 (VDDIO_1), IC1.43 (GPIO-1), IC1.45 (VDDIO_2), IC2.15 (VDDIO_1), IC2.43 (GPIO-1), IC2.45 (VDDIO_2); also elsewhere on the board
+5V: J4.1, J4.2, J4.3, J4.4, J4.5, J4.6, J4.7, J4.8, J4.9, J4.10; also elsewhere on the board
/extension/CAM1_CLK_N: IC1.47 (D-PHY-E-N), J4.45
/extension/CAM1_CLK_P: IC1.46 (D-PHY-E-P), J4.47
/extension/CAM1_D1_N: IC1.14 (D-PHY-A-N), J4.52
/extension/CAM1_D1_P: IC1.13 (D-PHY-A-P), J4.54
/extension/CAM1_D2_N: IC1.11 (D-PHY-B-N), J4.51
/extension/CAM1_D2_P: IC1.10 (D-PHY-B-P), J4.53
/extension/CAM1_D3_N: IC1.8 (D-PHY-C-N), J4.58
/extension/CAM1_D3_P: IC1.7 (D-PHY-C-P), J4.60
/extension/CAM1_D4_N: IC1.3 (D-PHY-D-N), J4.57
/extension/CAM1_D4_P: IC1.2 (D-PHY-D-P), J4.59
/extension/CAM2_CLK_N: IC2.47 (D-PHY-E-N), J4.15
/extension/CAM2_CLK_P: IC2.46 (D-PHY-E-P), J4.17
/extension/CAM2_D1_N: IC2.14 (D-PHY-A-N), J4.41
/extension/CAM2_D1_P: IC2.13 (D-PHY-A-P), J4.39
/extension/CAM2_D2_N: IC2.11 (D-PHY-B-N), J4.21
/extension/CAM2_D2_P: IC2.10 (D-PHY-B-P), J4.23
/extension/CAM2_D3_N: IC2.8 (D-PHY-C-N), J4.35
/extension/CAM2_D3_P: IC2.7 (D-PHY-C-P), J4.33
/extension/CAM2_D4_N: IC2.3 (D-PHY-D-N), J4.27
/extension/CAM2_D4_P: IC2.2 (D-PHY-D-P), J4.29
/extension/XVS0: J4.16
/extension/XVS1: J4.18
ENABLE_PWR: J4.32; also elsewhere on the board
ENABLE_XCLR: J4.30; also elsewhere on the board
ENABLE_XTAL: J4.28; also elsewhere on the board
GND: C56.1, C57.1, C58.1, C59.1, C60.1, C61.1, IC1.4 (GND_1), IC1.5 (BTA), IC1.6 (PIN_SWAP), IC1.9 (GND_2), IC1.28 (GND_3), IC1.31 (GND_4), IC1.33 (GND_5), IC1.44 (GPIO-0), IC1.48 (N.C._6), IC1.49 (EP), IC2.4 (GND_1), IC2.5 (BTA), IC2.6 (PIN_SWAP), IC2.9 (GND_2), IC2.28 (GND_3), IC2.31 (GND_4), IC2.33 (GND_5), IC2.44 (GPIO-0), IC2.48 (N.C._6), IC2.49 (EP), J4.11, J4.12, J4.13, J4.14, J4.19, J4.20, J4.25, J4.26, J4.31, J4.34, J4.36, J4.37, J4.38, J4.40, J4.42, J4.43, J4.44, J4.46, J4.48, J4.49, J4.50, J4.55, J4.56; also elsewhere on the board
MIPI1_HS_A_N: IC1.22 (HS-A-N); also elsewhere on the board
MIPI1_HS_A_P: IC1.23 (HS-A-P); also elsewhere on the board
MIPI1_HS_B_N: IC1.26 (HS-B-N); also elsewhere on the board
MIPI1_HS_B_P: IC1.27 (HS-B-P); also elsewhere on the board
MIPI1_HS_C_N: IC1.29 (HS-C-N); also elsewhere on the board
MIPI1_HS_C_P: IC1.30 (HS-C-P); also elsewhere on the board
MIPI1_HS_D_N: IC1.34 (HS-D-N); also elsewhere on the board
MIPI1_HS_D_P: IC1.35 (HS-D-P); also elsewhere on the board
MIPI1_HS_E_N: IC1.37 (HS-E-N); also elsewhere on the board
MIPI1_HS_E_P: IC1.38 (HS-E-P); also elsewhere on the board
MIPI1_LP_A_N: IC1.16 (LP-A-N); also elsewhere on the board
MIPI1_LP_A_P: IC1.17 (LP-A-P); also elsewhere on the board
MIPI1_LP_B_N: IC1.18 (LP-B-N); also elsewhere on the board
MIPI1_LP_B_P: IC1.19 (LP-B-P); also elsewhere on the board
MIPI1_LP_C_N: IC1.20 (LP-C-N); also elsewhere on the board
MIPI1_LP_C_P: IC1.21 (LP-C-P); also elsewhere on the board
MIPI1_LP_D_N: IC1.39 (LP-D-N); also elsewhere on the board
MIPI1_LP_D_P: IC1.40 (LP-D-P); also elsewhere on the board
MIPI1_LP_E_N: IC1.41 (LP-E-N); also elsewhere on the board
MIPI1_LP_E_P: IC1.42 (LP-E-P); also elsewhere on the board
MIPI2_HS_A_N: IC2.22 (HS-A-N); also elsewhere on the board
MIPI2_HS_A_P: IC2.23 (HS-A-P); also elsewhere on the board
MIPI2_HS_B_N: IC2.26 (HS-B-N); also elsewhere on the board
MIPI2_HS_B_P: IC2.27 (HS-B-P); also elsewhere on the board
MIPI2_HS_C_N: IC2.29 (HS-C-N); also elsewhere on the board
MIPI2_HS_C_P: IC2.30 (HS-C-P); also elsewhere on the board
MIPI2_HS_D_N: IC2.34 (HS-D-N); also elsewhere on the board
MIPI2_HS_D_P: IC2.35 (HS-D-P); also elsewhere on the board
MIPI2_HS_E_N: IC2.37 (HS-E-N); also elsewhere on the board
MIPI2_HS_E_P: IC2.38 (HS-E-P); also elsewhere on the board
MIPI2_LP_A_N: IC2.16 (LP-A-N); also elsewhere on the board
MIPI2_LP_A_P: IC2.17 (LP-A-P); also elsewhere on the board
MIPI2_LP_B_N: IC2.18 (LP-B-N); also elsewhere on the board
MIPI2_LP_B_P: IC2.19 (LP-B-P); also elsewhere on the board
MIPI2_LP_C_N: IC2.20 (LP-C-N); also elsewhere on the board
MIPI2_LP_C_P: IC2.21 (LP-C-P); also elsewhere on the board
MIPI2_LP_D_N: IC2.39 (LP-D-N); also elsewhere on the board
MIPI2_LP_D_P: IC2.40 (LP-D-P); also elsewhere on the board
MIPI2_LP_E_N: IC2.41 (LP-E-N); also elsewhere on the board
MIPI2_LP_E_P: IC2.42 (LP-E-P); also elsewhere on the board
SCL_1V8: J4.22
SDA_1V8: J4.24

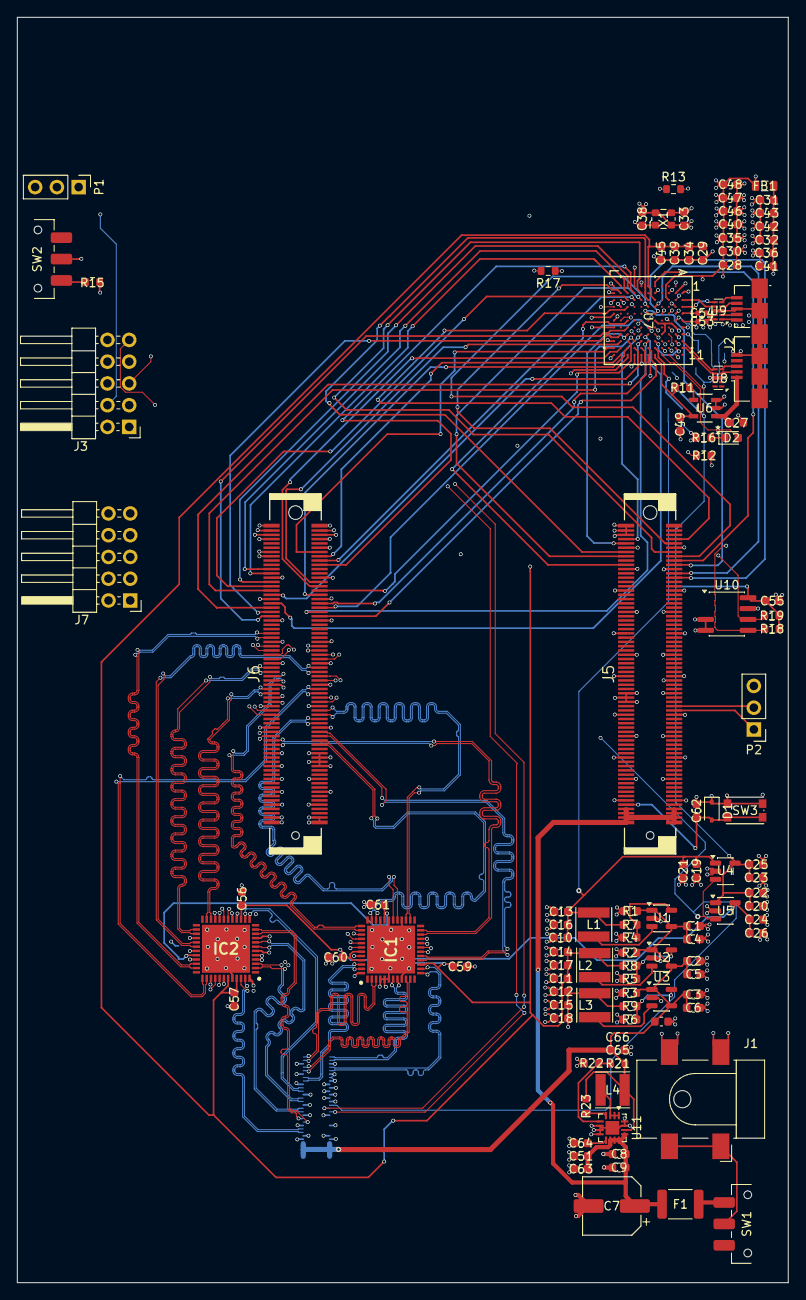
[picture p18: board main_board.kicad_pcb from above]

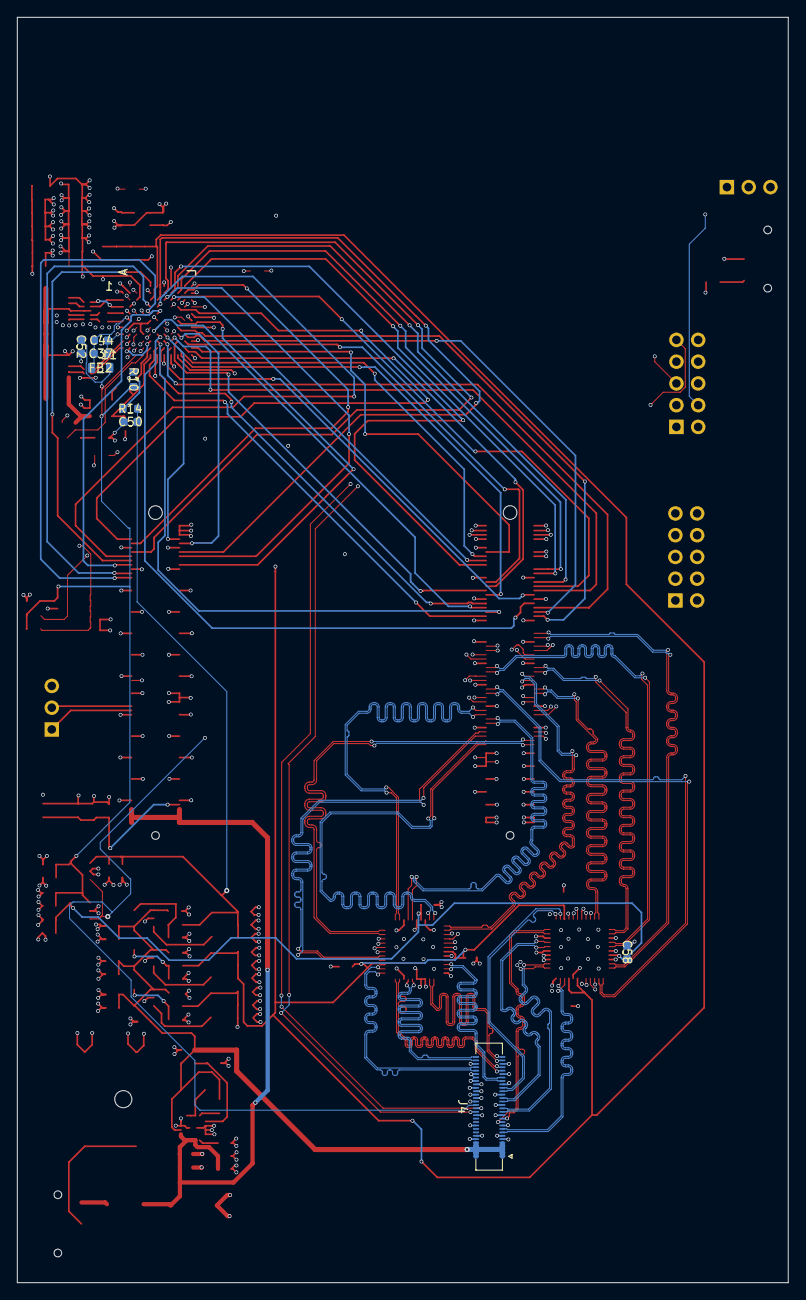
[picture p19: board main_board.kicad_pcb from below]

Board: 6 copper layers, 90.0 x 147.7 mm, 123 parts (9 on the bottom side), 165 nets.

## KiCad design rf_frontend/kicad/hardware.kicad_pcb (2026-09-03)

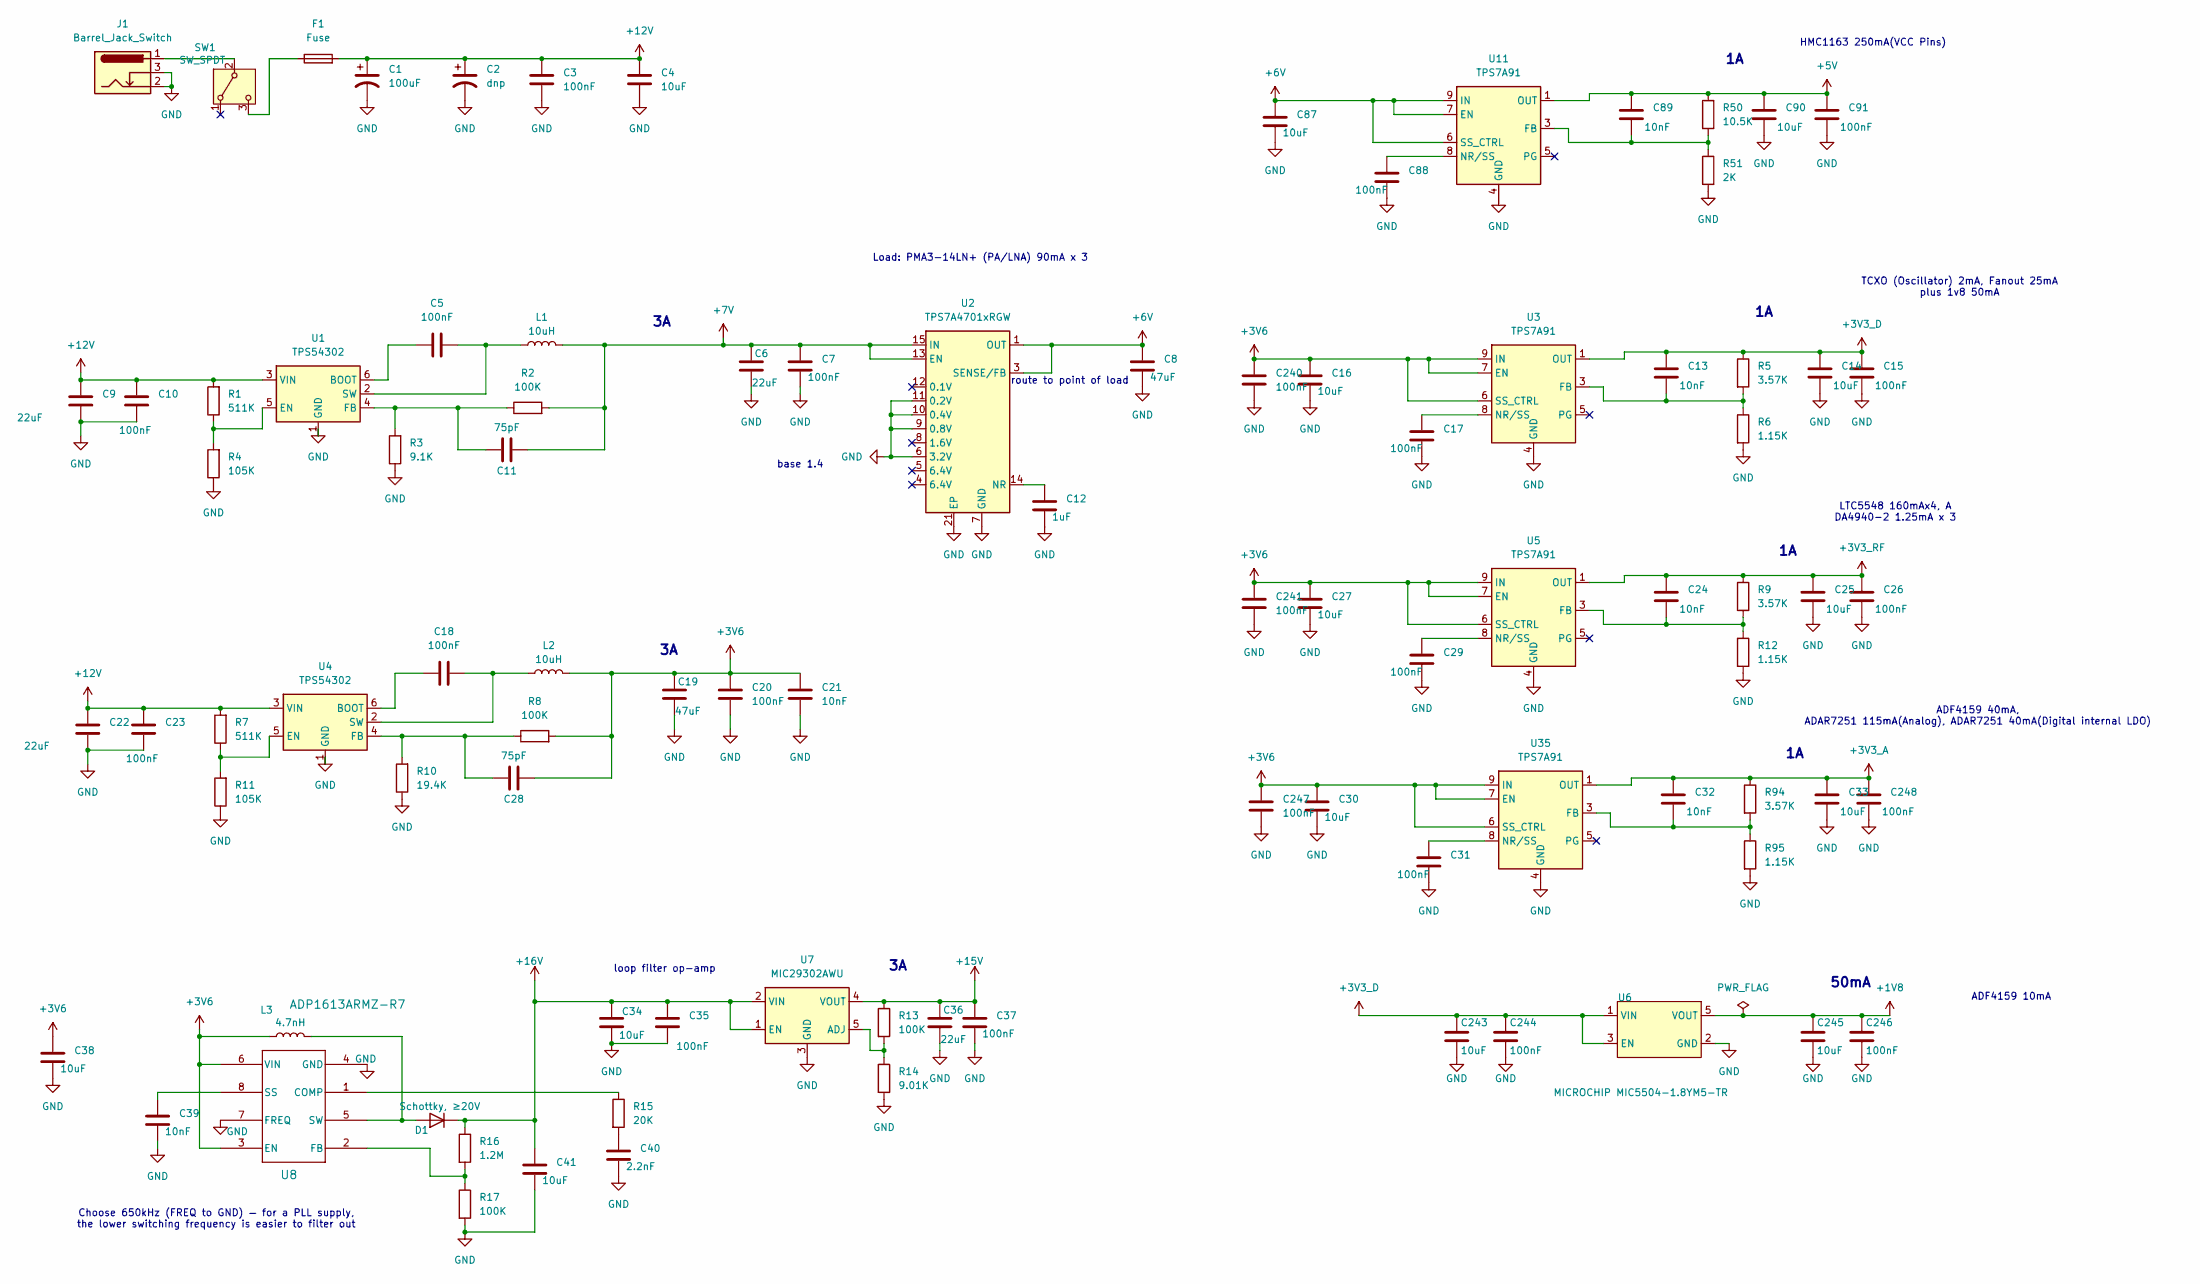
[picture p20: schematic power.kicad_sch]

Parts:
C1: 100uF; CAPC6153X670N
C2: dnp; CAPC6153X670N
C3, C5, C7, C10, C15, C17, C18, C20, C23, C26, C29, C31, C35, C37, C88, C91, C240, C241, C244, C246, C247, C248: 100nF; C_0402_1005Metric
C4, C14, C16, C25, C27, C30, C33, C34, C38, C41, C243, C245: 10uF; C_0805_2012Metric
C6, C9, C22, C36: 22uF; C_0805_2012Metric
C8, C19: 47uF; C_0805_2012Metric
C11, C28: 75pF; C_0402_1005Metric
C12: 1uF; C_0402_1005Metric
C13, C21, C24, C32, C39, C89: 10nF; C_0402_1005Metric
C40: 2.2nF; C_0402_1005Metric
C87, C90: 10uF; C_0402_1005Metric
D1: Schottky, ≥20V; D_SMA
F1: Fuse; Fuse_0603_1608Metric; LCSC Part # SMD1812P200TF16
J1: Barrel_Jack_Switch; BarrelJack_CUI_PJ-063AH_Horizontal
L1, L2: 10uH; L_Sunlord_MWSA0602S; Part# FXL0630-100-M
L3: 4.7nH; L_0402_1005Metric
R1, R7: 511K; R_0402_1005Metric
R2, R8, R13, R17: 100K; R_0402_1005Metric
R3: 9.1K; R_0402_1005Metric
R4, R11: 105K; R_0402_1005Metric
R5, R9, R94: 3.57K; R_0402_1005Metric
R6, R12, R95: 1.15K; R_0402_1005Metric
R10: 19.4K; R_0402_1005Metric
R14: 9.01K; R_0402_1005Metric
R15: 20K; R_0402_1005Metric
R16: 1.2M; R_0402_1005Metric
R50: 10.5K; R_0402_1005Metric
R51: 2K; R_0402_1005Metric
SW1: SW_SPDT; SW_SPDT_CK_JS102011SAQN; Part# JS102011SAQN; LCSC Part # C221660
U1, U4: TPS54302; SOT-23-6
U2: TPS7A4701xRGW; Texas_RGW0020A_VQFN-20-1EP_5x5mm_P0.65mm_EP3.15x3.15mm
U3, U5, U11, U35: TPS7A91; Texas_S-PDSO-N10_EP1.2x2mm
U6: MICROCHIP MIC5504-1.8YM5-TR; SOT-23-5; Part# MIC5504-1.8YM5-TR; LCSC Part # C626116
U7: MIC29302AWU; TO-263-5_TabPin3
U8: ADP1613ARMZ-R7; MSOP-8-1EP_3x3mm_P0.65mm_EP1.5x1.8mm

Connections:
+1V8: C245.1, C246.1, U6.5 (VOUT); also elsewhere on the board
+3V3_A: C32.1, C33.1, C248.1, R94.1, U35.1 (OUT), U35.2 (OUT); also elsewhere on the board
+3V3_D: C13.1, C14.1, C15.1, C243.1, C244.1, R5.1, U3.1 (OUT), U3.2 (OUT), U6.1 (VIN), U6.3 (EN); also elsewhere on the board
+3V3_RF: C24.1, C25.1, C26.1, R9.1, U5.1 (OUT), U5.2 (OUT); also elsewhere on the board
+3V6: C16.1, C19.1, C20.1, C21.1, C27.1, C28.2, C30.1, C38.1, C240.1, C241.1, C247.1, L2.2, L3.1, R8.2, U3.6 (SS_CTRL), U3.7 (EN), U3.9 (IN), U3.10 (IN), U5.6 (SS_CTRL), U5.7 (EN), U5.9 (IN), U5.10 (IN), U8.3 (EN), U8.6 (VIN), U35.6 (SS_CTRL), U35.7 (EN), U35.9 (IN), U35.10 (IN)
+5V: C89.1, C90.1, C91.1, R50.1, U11.1 (OUT), U11.2 (OUT); also elsewhere on the board
+6V: C8.1, C87.1, U2.1 (OUT), U2.3 (SENSE/FB), U2.20 (OUT), U11.6 (SS_CTRL), U11.7 (EN), U11.9 (IN), U11.10 (IN); also elsewhere on the board
+7V: C6.1, C7.1, C11.2, L1.2, R2.2, U2.13 (EN), U2.15 (IN), U2.16 (IN)
+12V: C1.1, C2.1, C3.1, C4.1, C9.1, C10.1, C22.1, C23.1, F1.2, R1.2, R7.2, U1.3 (VIN), U4.3 (VIN)
+15V: C36.1, C37.1, R13.1, U7.4 (VOUT); also elsewhere on the board
+16V: C34.1, C35.1, C41.1, D1.1 (K), R16.1, U7.1 (EN), U7.2 (VIN)
GND: C1.2, C2.2, C3.2, C4.2, C6.2, C7.2, C8.2, C9.2, C10.2, C12.2, C14.2, C15.2, C16.2, C17.2, C19.2, C20.2, C21.2, C22.2, C23.2, C25.2, C26.2, C27.2, C29.2, C30.2, C31.2, C33.2, C34.2, C35.2, C36.2, C37.2, C38.2, C39.2, C40.2, C41.2, C87.2, C88.2, C90.2, C91.2, C240.2, C241.2, C243.2, C244.2, C245.2, C246.2, C247.2, C248.2, J1.2, J1.3, R3.1, R4.1, R6.2, R10.1, R11.1, R12.2, R14.2, R17.2, R51.2, R95.2, U1.1 (GND), U2.6 (3.2V), U2.7 (GND), U2.9 (0.8V), U2.10 (0.4V), U2.11 (0.2V), U2.21 (EP), U3.4 (GND), U3.11 (GND), U4.1 (GND), U5.4 (GND), U5.11 (GND), U6.2 (GND), U7.3 (GND), U8.4 (GND), U8.7 (FREQ), U8.9, U11.4 (GND), U11.11 (GND), U35.4 (GND), U35.11 (GND); also elsewhere on the board
unnamed: C40.1, R15.2
unnamed: D1.2 (A), L3.2, U8.5 (SW)
unnamed: J1.1, SW1.2 (B)
unnamed: F1.1, SW1.3 (C)
unnamed: C5.1, U1.6 (BOOT)
unnamed: R1.1, R4.2, U1.5 (EN)
unnamed: C11.1, R2.1, R3.2, U1.4 (FB)
unnamed: C5.2, L1.1, U1.2 (SW)
unnamed: C12.1, U2.14 (NR)
unnamed: C13.2, R5.2, R6.1, U3.3 (FB)
unnamed: C17.1, U3.8 (NR/SS)
unnamed: C18.1, U4.6 (BOOT)
unnamed: R7.1, R11.2, U4.5 (EN)
unnamed: C28.1, R8.1, R10.2, U4.4 (FB)
unnamed: C18.2, L2.1, U4.2 (SW)
unnamed: C24.2, R9.2, R12.1, U5.3 (FB)
unnamed: C29.1, U5.8 (NR/SS)
unnamed: R13.2, R14.1, U7.5 (ADJ)
unnamed: R15.1, U8.1 (COMP)
unnamed: R16.2, R17.1, U8.2 (FB)
unnamed: C39.1, U8.8 (SS)
unnamed: C89.2, R50.2, R51.1, U11.3 (FB)
unnamed: C88.1, U11.8 (NR/SS)
unnamed: C32.2, R94.2, R95.1, U35.3 (FB)
unnamed: C31.1, U35.8 (NR/SS)

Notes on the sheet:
ADF4159 10mA
route to point of load
TCXO (Oscillator) 2mA, Fanout 25mA plus 1v8 50mA
Load: PMA3-14LN+ (PA/LNA) 90mA x 3
base 1.4
50mA
loop filter op-amp
LTC5548 160mAx4, A DA4940-2 1.25mA x 3
Choose 650kHz (FREQ to GND) — for a PLL supply, the lower switching frequency is easier to filter out
ADF4159 40mA, ADAR7251 115mA(Analog), ADAR7251 40mA(Digital internal LDO)
HMC1163 250mA(VCC Pins)

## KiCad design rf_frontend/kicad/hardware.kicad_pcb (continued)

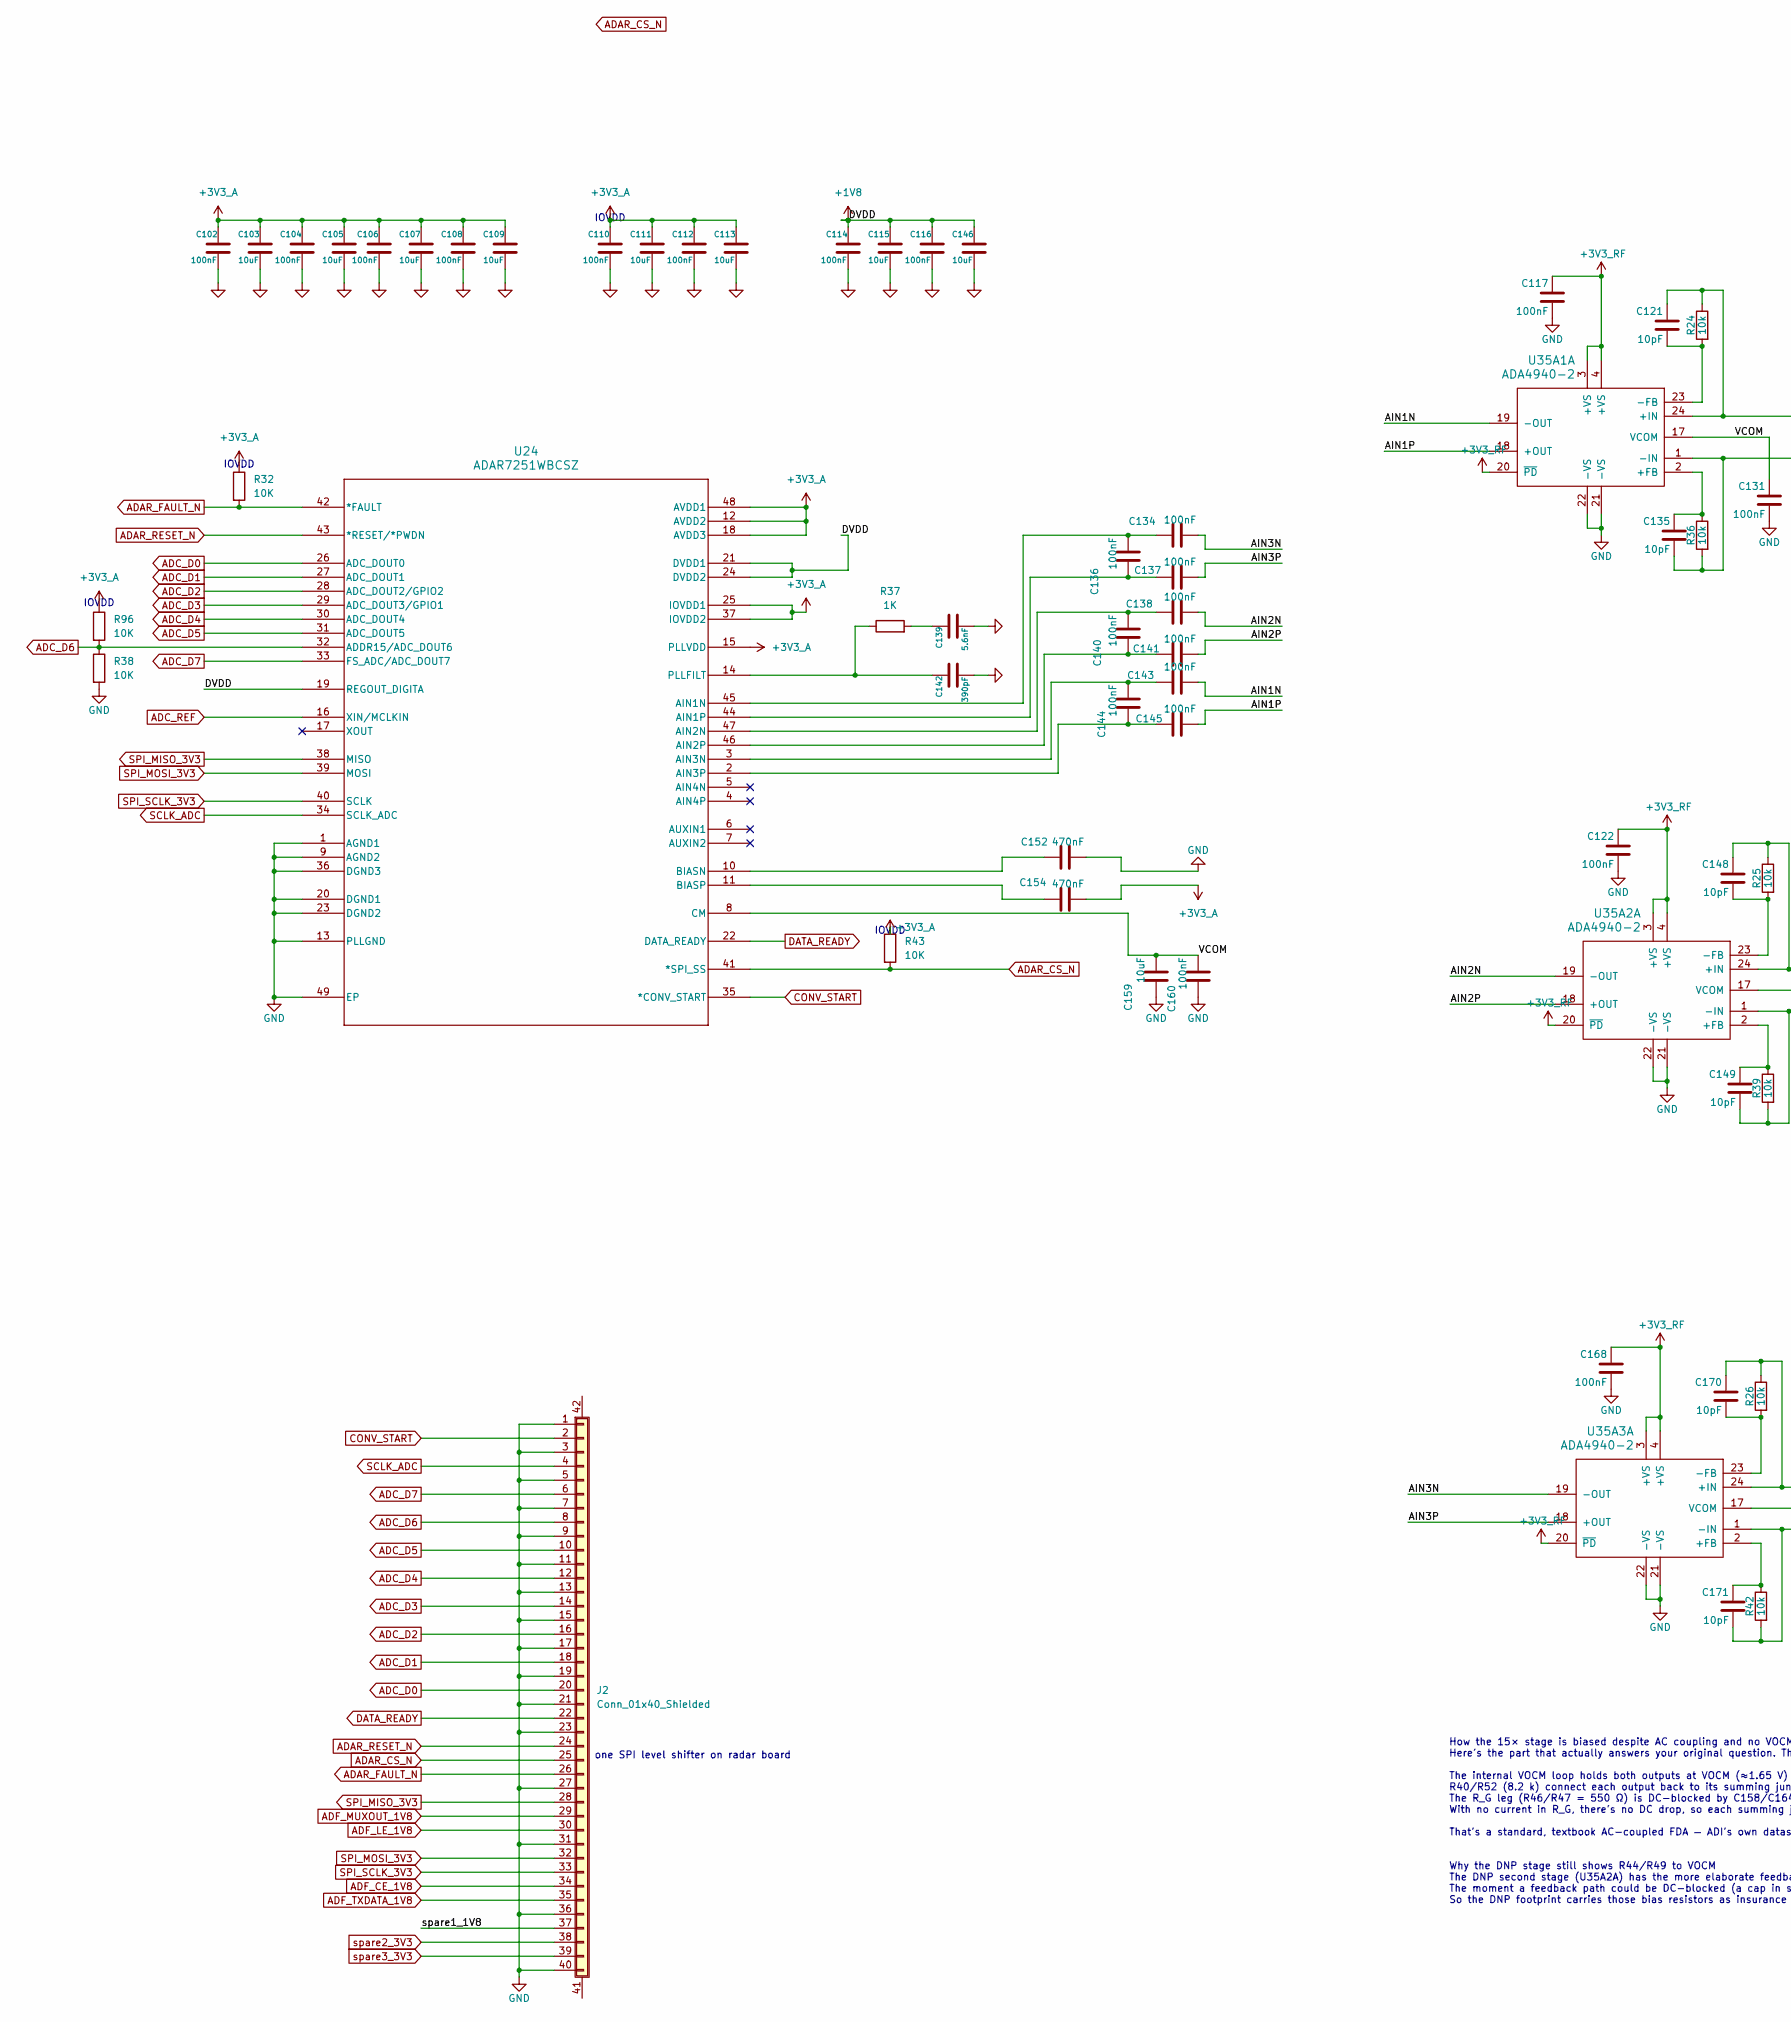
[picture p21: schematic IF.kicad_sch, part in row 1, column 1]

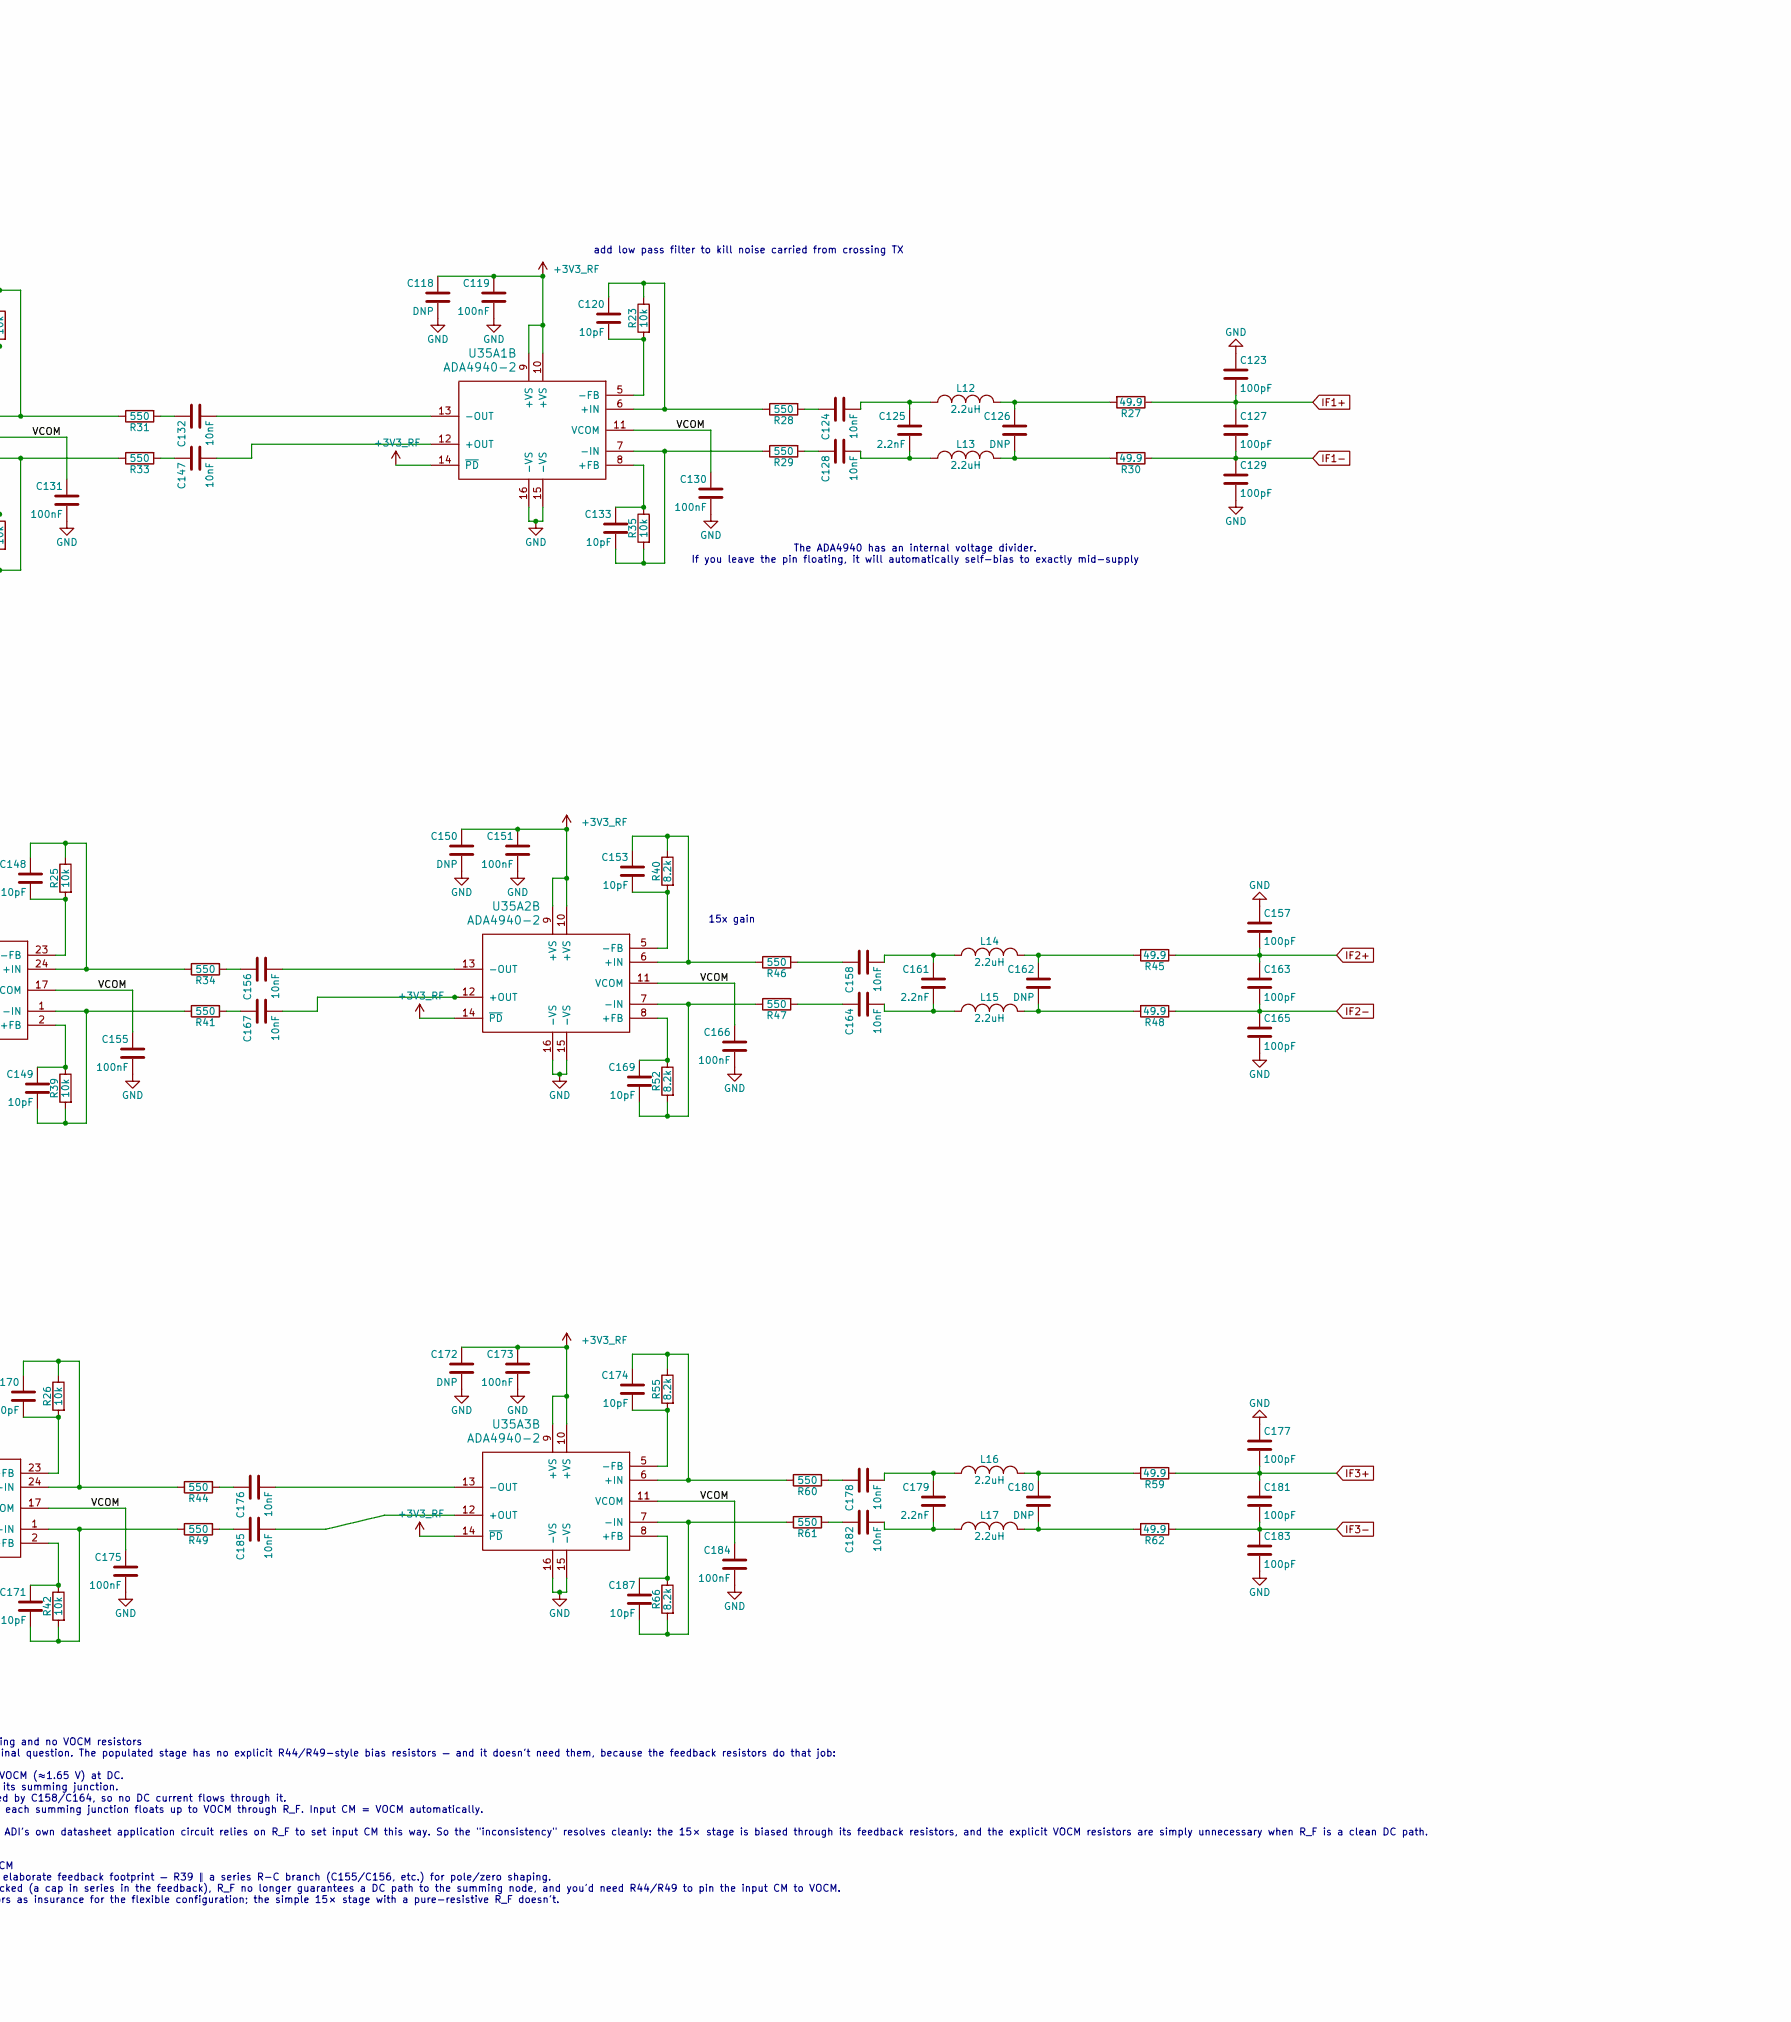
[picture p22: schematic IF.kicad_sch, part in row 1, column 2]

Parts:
C102, C104, C106, C108, C110, C112, C114, C116, C117, C119, C122, C130, C131, C134, C136, C137, C138, C140, C141, C143, C144, C145, C151, C155, C160, C166, C168, C173, C175, C184: 100nF; C_0402_1005Metric
C103, C105, C107, C109, C111, C113, C115, C146, C159: 10uF; C_0805_2012Metric
C118, C126, C150, C162, C172, C180: DNP; C_0402_1005Metric
C120, C121, C133, C135, C148, C149, C153, C169, C170, C171, C174, C187: 10pF; C_0402_1005Metric
C123, C127, C129, C157, C163, C165, C177, C181, C183: 100pF; C_0402_1005Metric
C124, C128, C132, C147, C156, C158, C164, C167, C176, C178, C182, C185: 10nF; C_0402_1005Metric
C125, C161, C179: 2.2nF; C_0402_1005Metric
C139: 5.6nF; C_0402_1005Metric
C142: 390pF; C_0402_1005Metric
C152, C154: 470nF; C_0402_1005Metric
J2: Conn_01x40_Shielded; FPC-SMD_40P-P0.50_XUNPU_FPC-05FB-40PH20; Part# FPC-05FB-40PH20; LCSC Part # C2856837
L12, L13, L14, L15, L16, L17: 2.2uH; L_0805_2012Metric
R23, R24, R25, R26, R35, R36, R39, R42: 10k; R_0402_1005Metric
R27, R30, R45, R48, R59, R62: 49.9; R_0402_1005Metric
R28, R29, R31, R33, R34, R41, R44, R46, R47, R49, R60, R61: 550; R_0402_1005Metric
R32, R38, R43, R96: 10K; R_0402_1005Metric
R37: 1K; R_0402_1005Metric
R40, R52, R55, R66: 8.2k; R_0402_1005Metric
U24: ADAR7251WBCSZ; LFCSP-VQ-48-1EP_7x7mm_P0.5mm
U35A1, U35A2, U35A3: ADA4940-2; LFCSP-24-1EP_4x4mm_P0.5mm_EP2.5x2.5mm

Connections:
+1V8: C114.1, C115.1, C116.1, C146.1, U24.19 (REGOUT_DIGITA), U24.21 (DVDD1), U24.24 (DVDD2); also elsewhere on the board
+3V3_A: C102.1, C103.1, C104.1, C105.1, C106.1, C107.1, C108.1, C109.1, C110.1, C111.1, C112.1, C113.1, C154.2, R32.1, R43.1, R96.1, U24.12 (AVDD2), U24.15 (PLLVDD), U24.18 (AVDD3), U24.25 (IOVDD1), U24.37 (IOVDD2), U24.48 (AVDD1); also elsewhere on the board
+3V3_RF: C117.1, C118.1, C119.1, C122.1, C150.1, C151.1, C168.1, C172.1, C173.1, U35A1.3 (+VS), U35A1.4 (+VS), U35A1.9 (+VS), U35A1.10 (+VS), U35A1.14 (~PD), U35A1.20 (~PD), U35A2.3 (+VS), U35A2.4 (+VS), U35A2.9 (+VS), U35A2.10 (+VS), U35A2.14 (~PD), U35A2.20 (~PD), U35A3.3 (+VS), U35A3.4 (+VS), U35A3.9 (+VS), U35A3.10 (+VS), U35A3.14 (~PD), U35A3.20 (~PD); also elsewhere on the board
/IF/AIN1N: C143.2, U35A1.19 (-OUT)
/IF/AIN1P: C145.2, U35A1.18 (+OUT)
/IF/AIN2N: C138.2, U35A2.19 (-OUT)
/IF/AIN2P: C141.2, U35A2.18 (+OUT)
/IF/AIN3N: C134.2, U35A3.19 (-OUT)
/IF/AIN3P: C137.2, U35A3.18 (+OUT)
/IF/VCOM: C130.1, C131.1, C155.1, C159.2, C160.2, C166.1, C175.1, C184.1, U24.8 (CM), U35A1.11 (VCOM), U35A1.17 (VCOM), U35A2.11 (VCOM), U35A2.17 (VCOM), U35A3.11 (VCOM), U35A3.17 (VCOM)
/IF/spare1_1V8: J2.37
ADAR_CS_N: J2.25, R43.2, U24.41 (*SPI_SS)
ADAR_FAULT_N: J2.26, R32.2, U24.42 (*FAULT)
ADAR_RESET_N: J2.24, U24.43 (*RESET/*PWDN)
ADC_D0: J2.20, U24.26 (ADC_DOUT0)
ADC_D1: J2.18, U24.27 (ADC_DOUT1)
ADC_D2: J2.16, U24.28 (ADC_DOUT2/GPIO2)
ADC_D3: J2.14, U24.29 (ADC_DOUT3/GPIO1)
ADC_D4: J2.12, U24.30 (ADC_DOUT4)
ADC_D5: J2.10, U24.31 (ADC_DOUT5)
ADC_D6: J2.8, R38.1, R96.2, U24.32 (ADDR15/ADC_DOUT6)
ADC_D7: J2.6, U24.33 (FS_ADC/ADC_DOUT7)
ADC_REF: U24.16 (XIN/MCLKIN); also elsewhere on the board
ADF_CE_1V8: J2.34; also elsewhere on the board
ADF_LE_1V8: J2.30; also elsewhere on the board
ADF_MUXOUT_1V8: J2.29; also elsewhere on the board
ADF_TXDATA_1V8: J2.35; also elsewhere on the board
CONV_START: J2.2, U24.35 (*CONV_START)
DATA_READY: J2.22, U24.22 (DATA_READY)
GND: C102.2, C103.2, C104.2, C105.2, C106.2, C107.2, C108.2, C109.2, C110.2, C111.2, C112.2, C113.2, C114.2, C115.2, C116.2, C117.2, C118.2, C119.2, C122.2, C123.1, C129.2, C130.2, C131.2, C139.2, C142.2, C146.2, C150.2, C151.2, C152.2, C155.2, C157.1, C159.1, C160.1, C165.2, C166.2, C168.2, C172.2, C173.2, C175.2, C177.1, C183.2, C184.2, J2.1, J2.3, J2.5, J2.7, J2.9, J2.11, J2.13, J2.15, J2.17, J2.19, J2.21, J2.23, J2.27, J2.31, J2.36, J2.40, R38.2, U24.1 (AGND1), U24.9 (AGND2), U24.13 (PLLGND), U24.20 (DGND1), U24.23 (DGND2), U24.36 (DGND3), U24.49 (EP), U35A1.15 (-VS), U35A1.16 (-VS), U35A1.21 (-VS), U35A1.22 (-VS), U35A1.25, U35A2.15 (-VS), U35A2.16 (-VS), U35A2.21 (-VS), U35A2.22 (-VS), U35A2.25, U35A3.15 (-VS), U35A3.16 (-VS), U35A3.21 (-VS), U35A3.22 (-VS), U35A3.25; also elsewhere on the board
IF1+: C123.2, C127.1, R27.1; also elsewhere on the board
IF1-: C127.2, C129.1, R30.1; also elsewhere on the board
IF2+: C157.2, C163.1, R45.1; also elsewhere on the board
IF2-: C163.2, C165.1, R48.1; also elsewhere on the board
IF3+: C177.2, C181.1, R59.1; also elsewhere on the board
IF3-: C181.2, C183.1, R62.1; also elsewhere on the board
unnamed: C124.1, R28.2
unnamed: C124.2, C125.1, L12.2
unnamed: C125.2, C128.2, L13.2
unnamed: C126.1, L12.1, R27.2
unnamed: C126.2, L13.1, R30.2
unnamed: C128.1, R29.2
unnamed: C132.1, R31.2
unnamed: C139.1, R37.2
unnamed: C147.1, R33.2
unnamed: C156.1, R34.2
unnamed: C158.1, R46.2
unnamed: C158.2, C161.1, L14.2
unnamed: C161.2, C164.2, L15.2
unnamed: C162.1, L14.1, R45.2
unnamed: C162.2, L15.1, R48.2
unnamed: C164.1, R47.2
unnamed: C167.1, R41.2
unnamed: C176.1, R44.2
unnamed: C178.1, R60.2
unnamed: C178.2, C179.1, L16.2
unnamed: C179.2, C182.2, L17.2
unnamed: C180.1, L16.1, R59.2
unnamed: C180.2, L17.1, R62.2
unnamed: C182.1, R61.2
unnamed: C185.1, R49.2
unnamed: C134.1, C136.2, U24.45 (AIN1N)
unnamed: C136.1, C137.1, U24.44 (AIN1P)
unnamed: C138.1, C140.2, U24.47 (AIN2N)
unnamed: C140.1, C141.1, U24.46 (AIN2P)
unnamed: C143.1, C144.2, U24.3 (AIN3N)
unnamed: C144.1, C145.1, U24.2 (AIN3P)
unnamed: C152.1, U24.10 (BIASN)
unnamed: C154.1, U24.11 (BIASP)
unnamed: C142.1, R37.1, U24.14 (PLLFILT)
unnamed: C135.1, R36.1, U35A1.2 (+FB)
unnamed: C121.1, R24.1, R31.1, U35A1.24 (+IN)
unnamed: C121.2, R24.2, U35A1.23 (-FB)
unnamed: C135.2, R33.1, R36.2, U35A1.1 (-IN)
unnamed: C133.1, R35.1, U35A1.8 (+FB)
unnamed: C120.1, R23.1, R28.1, U35A1.6 (+IN)
unnamed: C147.2, U35A1.12 (+OUT)
unnamed: C120.2, R23.2, U35A1.5 (-FB)
unnamed: C133.2, R29.1, R35.2, U35A1.7 (-IN)
unnamed: C132.2, U35A1.13 (-OUT)
unnamed: C149.1, R39.1, U35A2.2 (+FB)
unnamed: C148.1, R25.1, R34.1, U35A2.24 (+IN)
unnamed: C148.2, R25.2, U35A2.23 (-FB)
unnamed: C149.2, R39.2, R41.1, U35A2.1 (-IN)
unnamed: C169.1, R52.1, U35A2.8 (+FB)
unnamed: C153.1, R40.1, R46.1, U35A2.6 (+IN)
unnamed: C167.2, U35A2.12 (+OUT)
unnamed: C153.2, R40.2, U35A2.5 (-FB)
unnamed: C169.2, R47.1, R52.2, U35A2.7 (-IN)
unnamed: C156.2, U35A2.13 (-OUT)
unnamed: C171.1, R42.1, U35A3.2 (+FB)
unnamed: C170.1, R26.1, R44.1, U35A3.24 (+IN)
unnamed: C170.2, R26.2, U35A3.23 (-FB)
unnamed: C171.2, R42.2, R49.1, U35A3.1 (-IN)
unnamed: C187.1, R66.1, U35A3.8 (+FB)
unnamed: C174.1, R55.1, R60.1, U35A3.6 (+IN)
unnamed: C185.2, U35A3.12 (+OUT)
unnamed: C174.2, R55.2, U35A3.5 (-FB)
unnamed: C187.2, R61.1, R66.2, U35A3.7 (-IN)
unnamed: C176.2, U35A3.13 (-OUT)
SCLK_ADC: J2.4, U24.34 (SCLK_ADC)
SPI_MISO_3V3: J2.28, U24.38 (MISO)
SPI_MOSI_3V3: J2.32, U24.39 (MOSI); also elsewhere on the board
SPI_SCLK_3V3: J2.33, U24.40 (SCLK); also elsewhere on the board
spare2_3V3: J2.38
spare3_3V3: J2.39

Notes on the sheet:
add low pass filter to kill noise carried from crossing TX
IOVDD
The ADA4940 has an internal voltage divider. If you leave the pin floating, it will automatically self-bias to exactly mid-supply
15x gain
How the 15× stage is biased despite AC coupling and no VOCM resistors Here's the part that actually answers your original question. The populated stage has no explicit R44/R49-style bias resistors — and it doesn't need them, because the feedback resistors do that job: The internal VOCM loop holds b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
one SPI level shifter on radar board

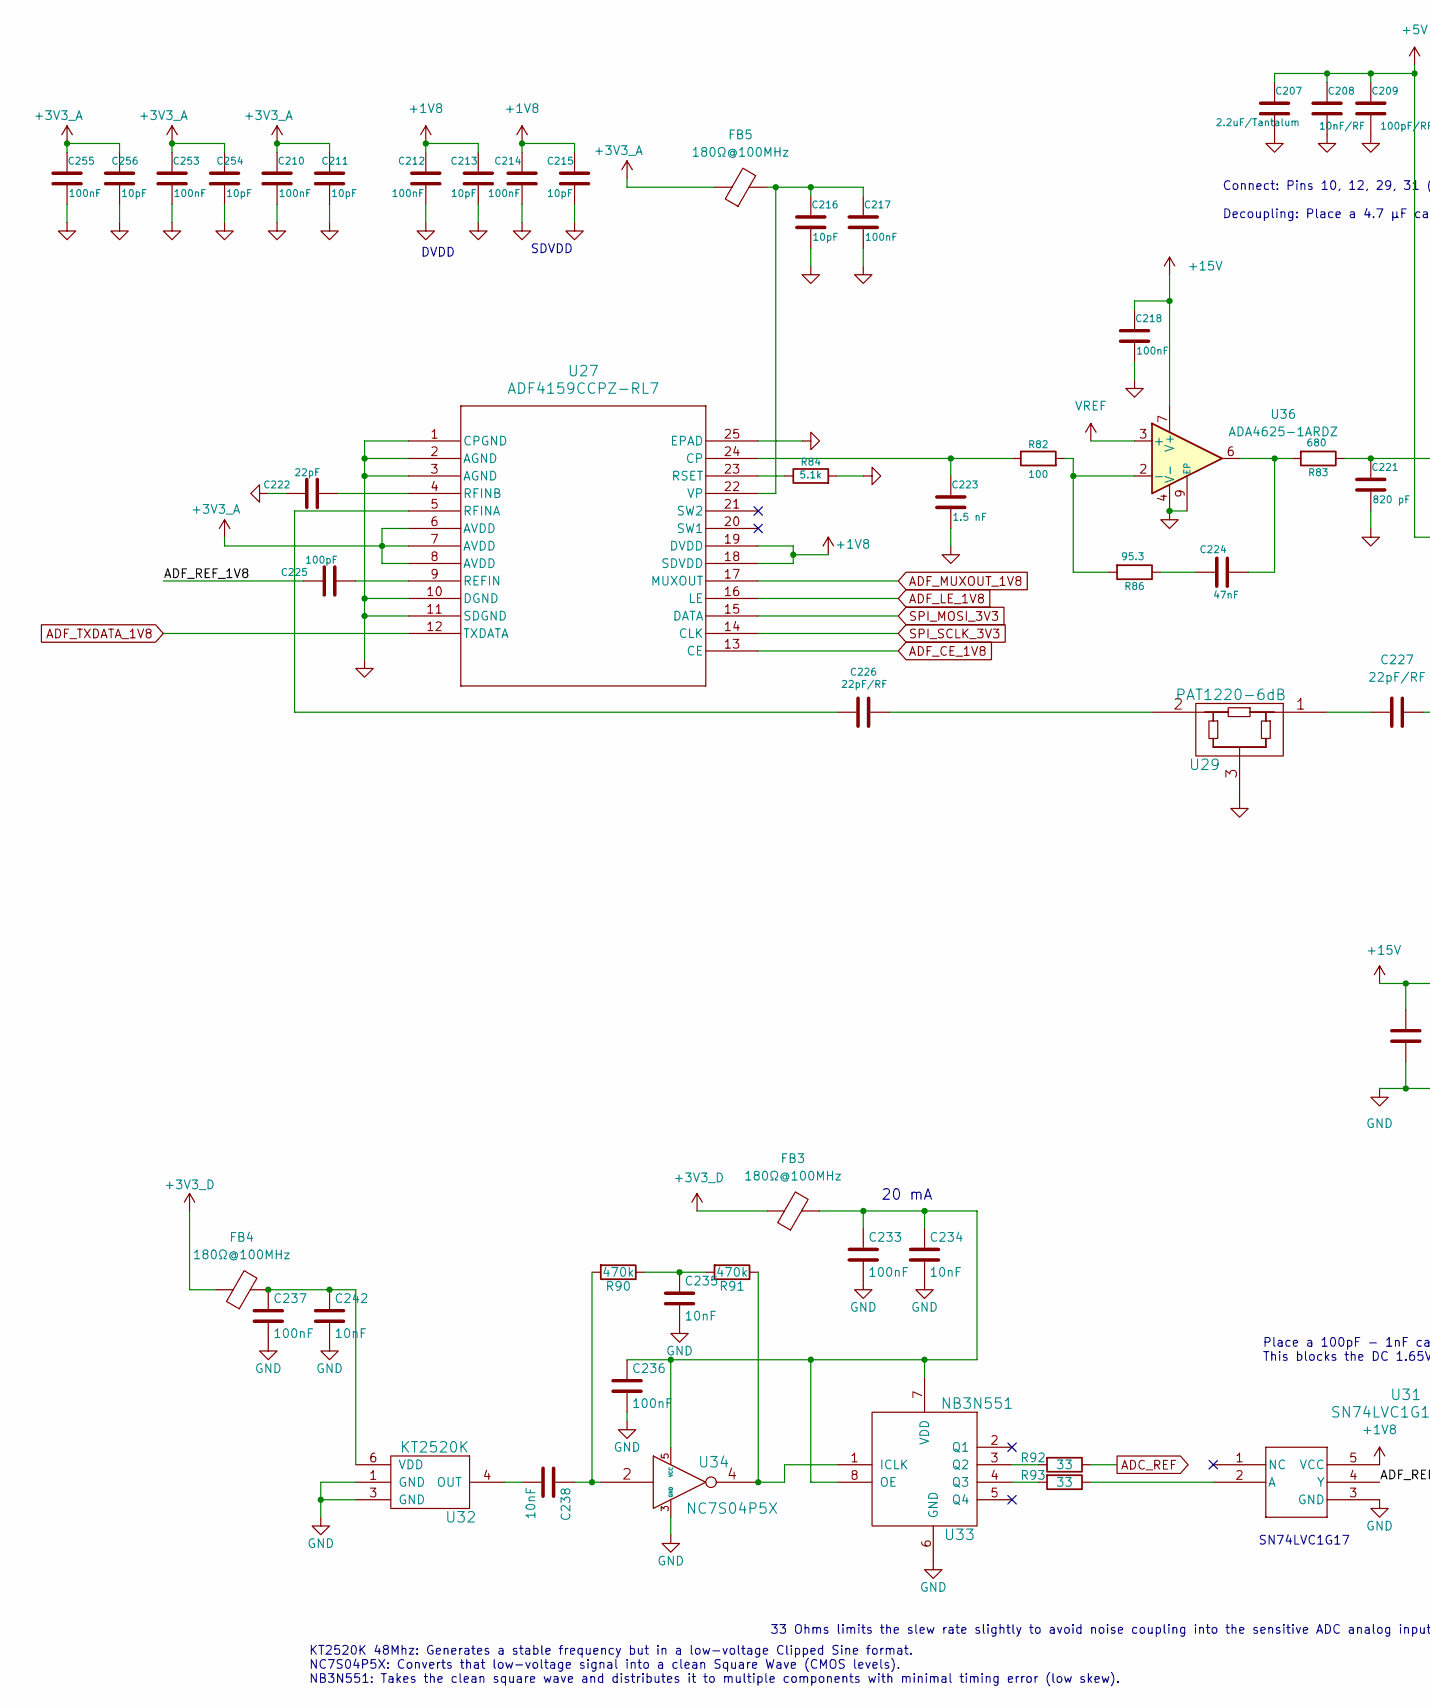
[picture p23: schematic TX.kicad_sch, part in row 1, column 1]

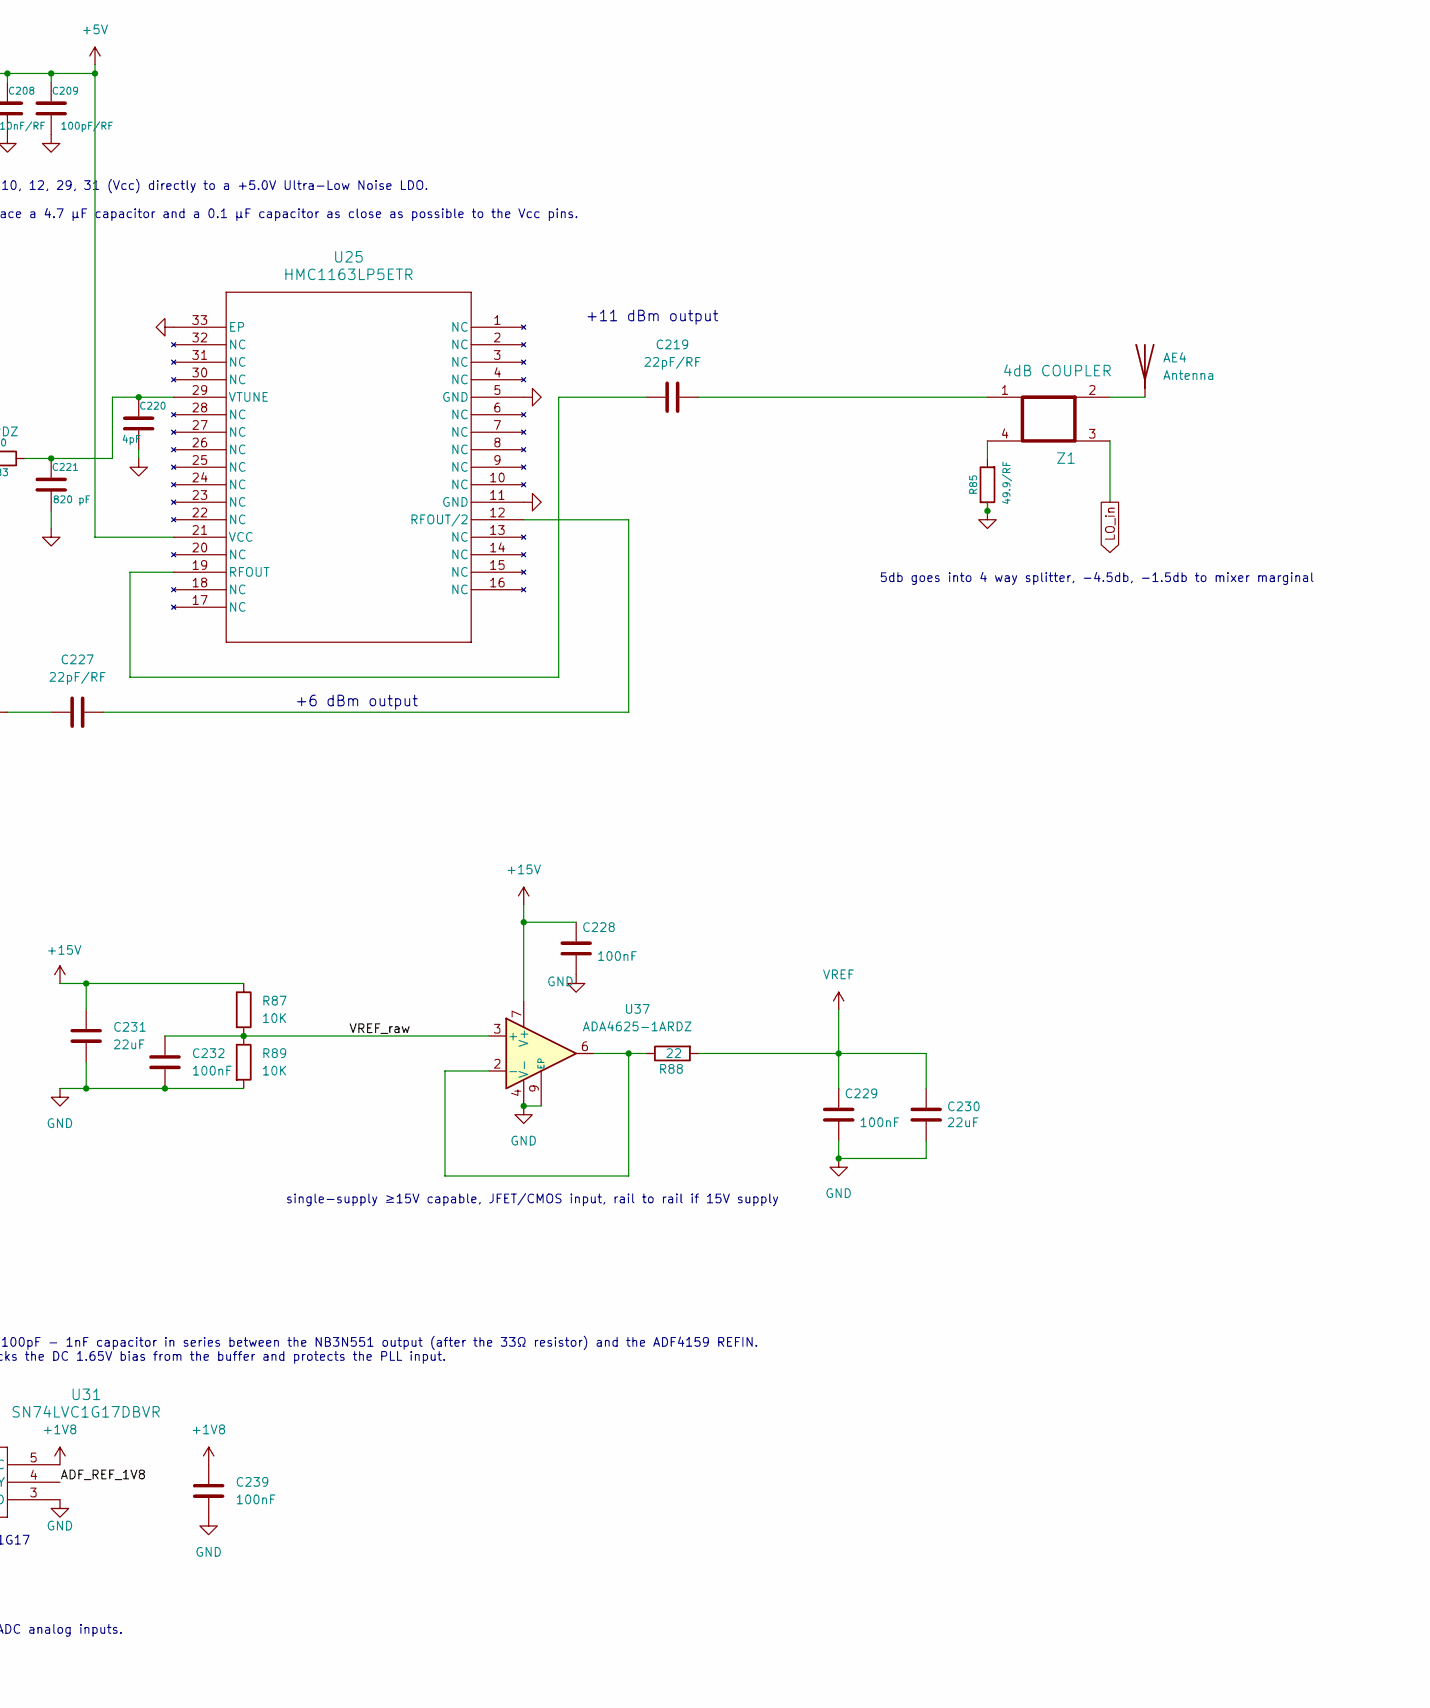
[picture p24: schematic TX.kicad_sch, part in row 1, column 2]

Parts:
AE4: Antenna; antenna
C207: 2.2uF/Tantalum; C_0805_2012Metric
C208: 10nF/RF; C_0402_1005Metric
C209: 100pF/RF; C_0402_1005Metric
C210, C212, C214, C217, C218, C228, C229, C232, C233, C236, C237, C239, C253, C255: 100nF; C_0402_1005Metric
C211, C213, C215, C216, C254, C256: 10pF; C_0402_1005Metric
C219, C226, C227: 22pF/RF; C_0201_0603Metric
C220: 4pF; C_0402_1005Metric
C221: 820 pF; C_0402_1005Metric
C222: 22pF; C_0402_1005Metric
C223: 1.5 nF; C_0402_1005Metric
C224: 47nF; C_0402_1005Metric
C225: 100pF; C_0402_1005Metric
C230, C231: 22uF; C_0805_2012Metric
C234, C235, C238, C242: 10nF; C_0402_1005Metric
FB3, FB4, FB5: 180Ω@100MHz; L_0603_1608Metric; Part# BLM18PG181SN1D; LCSC Part # C82850
R82: 100; R_0402_1005Metric
R83: 680; R_0402_1005Metric
R84: 5.1k; R_0402_1005Metric
R85: 49.9/RF; R_0402_1005Metric
R86: 95.3; R_0402_1005Metric
R87, R89: 10K; R_0402_1005Metric; LCSC Part # x
R88: 22; R_0805_2012Metric; LCSC Part # C108406
R90, R91: 470k; R_0402_1005Metric
R92, R93: 33; R_0805_2012Metric
U25: HMC1163LP5ETR; LFCSP-32-1EP_5x5mm_P0.5mm_EP3.1x3.1mm
U27: ADF4159CCPZ-RL7; LFCSP-24-1EP_4x4mm_P0.5mm_EP2.3x2.3mm
U29: PAT1220-6dB; ATTN_PAT1220-C-1DB-T5
U31: SN74LVC1G17DBVR; SOT-23-5
U32: KT2520K; Oscillator_SMD_Kyocera_2520-6Pin_2.5x2.0mm
U33: NB3N551; DFN-8-1EP_6x5mm_P1.27mm_EP4x4mm
U34: NC7S04P5X; SOT-353_SC-70-5
U36, U37: ADA4625-1ARDZ; SOIC-8-1EP_3.9x4.9mm_P1.27mm_EP2.29x3mm
Z1: 4dB COUPLER; branchline

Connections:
+1V8: C212.1, C213.1, C214.1, C215.1, C239.1, U27.18 (SDVDD), U27.19 (DVDD), U31.5 (VCC); also elsewhere on the board
+3V3_A: C210.1, C211.1, C253.1, C254.1, C255.1, C256.1, FB5.1, U27.6 (AVDD), U27.7 (AVDD), U27.8 (AVDD); also elsewhere on the board
+3V3_D: FB3.1, FB4.1; also elsewhere on the board
+5V: C207.1, C208.1, C209.1, U25.21 (VCC); also elsewhere on the board
+15V: C218.1, C228.1, C231.1, R87.1, U36.7 (V+), U37.7 (V+); also elsewhere on the board
/TX/ADF_REF_1V8: C225.1, U31.4 (Y)
/TX/VREF_raw: C232.1, R87.2, R89.1, U37.3 (+)
ADC_REF: R92.1; also elsewhere on the board
ADF_CE_1V8: U27.13 (CE); also elsewhere on the board
ADF_LE_1V8: U27.16 (LE); also elsewhere on the board
ADF_MUXOUT_1V8: U27.17 (MUXOUT); also elsewhere on the board
ADF_TXDATA_1V8: U27.12 (TXDATA); also elsewhere on the board
GND: C207.2, C208.2, C209.2, C210.2, C211.2, C212.2, C213.2, C214.2, C215.2, C216.2, C217.2, C218.2, C220.2, C221.2, C222.1, C223.2, C228.2, C229.2, C230.2, C231.2, C232.2, C233.2, C234.2, C235.2, C236.2, C237.2, C239.2, C242.2, C253.2, C254.2, C255.2, C256.2, R84.2, R85.1, R89.2, U25.5 (GND), U25.11 (GND), U25.33 (EP), U27.1 (CPGND), U27.2 (AGND), U27.3 (AGND), U27.10 (DGND), U27.11 (SDGND), U27.25 (EPAD), U29.3, U31.3 (GND), U32.1 (GND), U32.3 (GND), U33.6 (GND), U34.3 (GND), U36.4 (V-), U36.9 (EP), U37.4 (V-), U37.9 (EP); also elsewhere on the board
LO_in: Z1.3; also elsewhere on the board
unnamed: AE4.1 (A_1), Z1.2
unnamed: C219.2, Z1.1
unnamed: C224.1, R86.1
unnamed: C224.2, R83.2, U36.6
unnamed: C226.1, U29.2
unnamed: C227.1, U29.1
unnamed: C235.1, R90.1, R91.2
unnamed: C238.1, R90.2, U34.2
unnamed: R85.2, Z1.4
unnamed: C219.1, U25.19 (RFOUT)
unnamed: C227.2, U25.12 (RFOUT/2)
unnamed: C220.1, C221.1, R83.1, U25.29 (VTUNE)
unnamed: C223.1, R82.1, U27.24 (CP)
unnamed: C225.2, U27.9 (REFIN)
unnamed: C226.2, U27.5 (RFINA)
unnamed: C222.2, U27.4 (RFINB)
unnamed: R84.1, U27.23 (RSET)
unnamed: C216.1, C217.1, FB5.2, U27.22 (VP)
unnamed: R93.1, U31.2 (A)
unnamed: C238.2, U32.4 (OUT)
unnamed: C237.1, C242.1, FB4.2, U32.6 (VDD)
unnamed: R91.1, U33.1 (ICLK), U34.4
unnamed: C233.1, C234.1, C236.1, FB3.2, U33.7 (VDD), U33.8 (OE), U34.5 (VCC)
unnamed: R92.2, U33.3 (Q2)
unnamed: R93.2, U33.4 (Q3)
unnamed: R82.2, R86.2, U36.2 (-)
unnamed: R88.1, U37.2 (-), U37.6
SPI_MOSI_3V3: U27.15 (DATA); also elsewhere on the board
SPI_SCLK_3V3: U27.14 (CLK); also elsewhere on the board
VREF: C229.1, C230.1, R88.2, U36.3 (+)

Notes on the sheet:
Connect: Pins 10, 12, 29, 31 (Vcc) directly to a +5.0V Ultra-Low Noise LDO. Decoupling: Place a 4.7 µF capacitor and a 0.1 µF capacitor as close as possible to the Vcc pins.
33 Ohms limits the slew rate slightly to avoid noise coupling into the sensitive ADC analog inputs.
Place a 100pF - 1nF capacitor in series between the NB3N551 output (after the 33Ω resistor) and the ADF4159 REFIN. This blocks the DC 1.65V bias from the buffer and protects the PLL input.
SN74LVC1G17
single-supply ≥15V capable, JFET/CMOS input, rail to rail if 15V supply
DVDD
KT2520K 48Mhz: Generates a stable frequency but in a low-voltage Clipped Sine format. NC7S04P5X: Converts that low-voltage signal into a clean Square Wave (CMOS levels). NB3N551: Takes the clean square wave and distributes it to multiple components with minimal timing error (low skew).
+11 dBm output
+6 dBm output
SDVDD
5db goes into 4 way splitter, -4.5db, -1.5db to mixer marginal
20 mA

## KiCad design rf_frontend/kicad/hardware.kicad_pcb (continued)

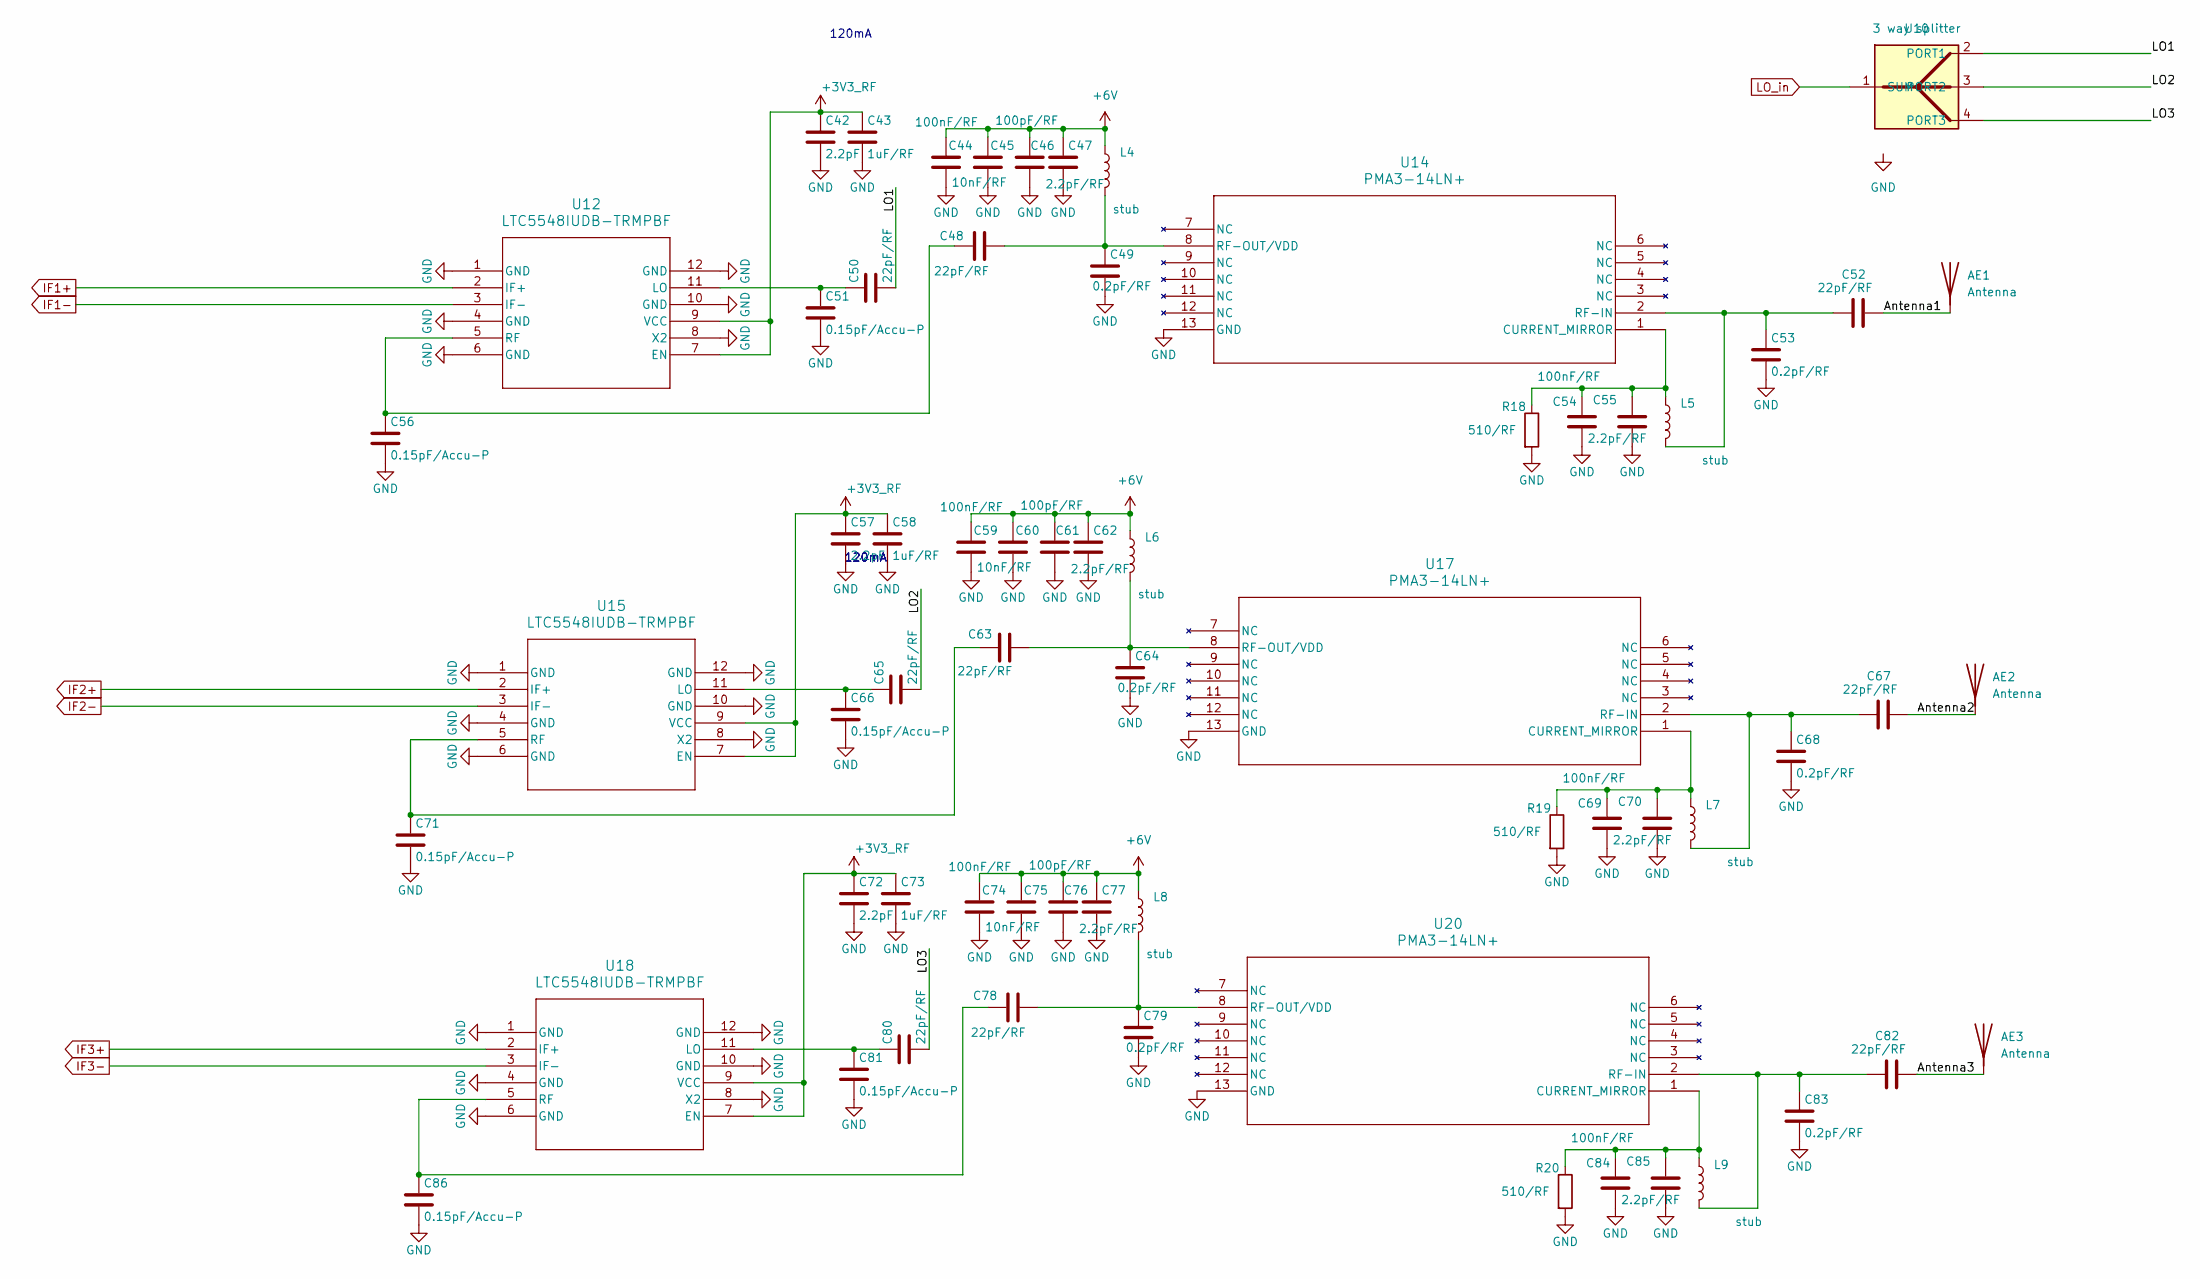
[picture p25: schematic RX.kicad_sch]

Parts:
AE1, AE2, AE3: Antenna; antenna
C42, C57, C72: 2.2pF; C_0201_0603Metric
C43, C58, C73: 1uF/RF; C_0402_1005Metric
C44, C54, C59, C69, C74, C84: 100nF/RF; C_0402_1005Metric
C45, C60, C75: 10nF/RF; C_0402_1005Metric
C46, C61, C76: 100pF/RF; C_0402_1005Metric
C47, C55, C62, C70, C77, C85: 2.2pF/RF; C_0402_1005Metric
C48, C50, C52, C63, C65, C67, C78, C80, C82: 22pF/RF; C_0201_0603Metric
C49, C53, C64, C68, C79, C83: 0.2pF/RF; C_0201_0603Metric
C51, C56, C66, C71, C81, C86: 0.15pF/Accu-P; C_0201_0603Metric
L4, L5, L6, L7, L8, L9: stub; NetTie-2_SMD_Pad0.5mm
R18, R19, R20: 510/RF; R_0402_1005Metric
U10: 3 way splitter; splitter
U12, U15, U18: LTC5548IUDB-TRMPBF; QFN-12-1EP_3x3mm_P0.5mm_EP1.45x1.45mm
U14, U17, U20: PMA3-14LN+; VQFN-12-1EP_4x4mm_P0.8mm_EP2.1x2.1mm; Part# PMA3-14LN+

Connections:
+3V3_RF: C42.1, C43.1, C57.1, C58.1, C72.1, C73.1, U12.7 (EN), U12.9 (VCC), U15.7 (EN), U15.9 (VCC), U18.7 (EN), U18.9 (VCC); also elsewhere on the board
+6V: C44.1, C45.1, C46.1, C47.1, C59.1, C60.1, C61.1, C62.1, C74.1, C75.1, C76.1, C77.1, L4.1, L6.1, L8.1; also elsewhere on the board
/RX/Antenna1: AE1.1 (A_1), C52.2
/RX/Antenna2: AE2.1 (A_1), C67.2
/RX/Antenna3: AE3.1 (A_1), C82.2
/RX/LO1: C50.2, U10.2 (PORT1)
/RX/LO2: C65.2, U10.3 (PORT2)
/RX/LO3: C80.2, U10.4 (PORT3)
GND: C42.2, C43.2, C44.2, C45.2, C46.2, C47.2, C49.2, C51.2, C53.2, C54.2, C55.2, C56.2, C57.2, C58.2, C59.2, C60.2, C61.2, C62.2, C64.2, C66.2, C68.2, C69.2, C70.2, C71.2, C72.2, C73.2, C74.2, C75.2, C76.2, C77.2, C79.2, C81.2, C83.2, C84.2, C85.2, C86.2, R18.2, R19.2, R20.2, U12.1 (GND), U12.4 (GND), U12.6 (GND), U12.8 (X2), U12.10 (GND), U12.12 (GND), U12.13, U14.13 (GND), U15.1 (GND), U15.4 (GND), U15.6 (GND), U15.8 (X2), U15.10 (GND), U15.12 (GND), U15.13, U17.13 (GND), U18.1 (GND), U18.4 (GND), U18.6 (GND), U18.8 (X2), U18.10 (GND), U18.12 (GND), U18.13, U20.13 (GND); also elsewhere on the board
IF1+: U12.2 (IF+); also elsewhere on the board
IF1-: U12.3 (IF-); also elsewhere on the board
IF2+: U15.2 (IF+); also elsewhere on the board
IF2-: U15.3 (IF-); also elsewhere on the board
IF3+: U18.2 (IF+); also elsewhere on the board
IF3-: U18.3 (IF-); also elsewhere on the board
LO_in: U10.1 (SUM); also elsewhere on the board
unnamed: C50.1, C51.1, U12.11 (LO)
unnamed: C48.1, C56.1, U12.5 (RF)
unnamed: C54.1, C55.1, L5.1, R18.1, U14.1 (CURRENT_MIRROR)
unnamed: C52.1, C53.1, L5.2, U14.2 (RF-IN)
unnamed: C48.2, C49.1, L4.2, U14.8 (RF-OUT/VDD)
unnamed: C65.1, C66.1, U15.11 (LO)
unnamed: C63.1, C71.1, U15.5 (RF)
unnamed: C69.1, C70.1, L7.1, R19.1, U17.1 (CURRENT_MIRROR)
unnamed: C67.1, C68.1, L7.2, U17.2 (RF-IN)
unnamed: C63.2, C64.1, L6.2, U17.8 (RF-OUT/VDD)
unnamed: C80.1, C81.1, U18.11 (LO)
unnamed: C78.1, C86.1, U18.5 (RF)
unnamed: C84.1, C85.1, L9.1, R20.1, U20.1 (CURRENT_MIRROR)
unnamed: C82.1, C83.1, L9.2, U20.2 (RF-IN)
unnamed: C78.2, C79.1, L8.2, U20.8 (RF-OUT/VDD)

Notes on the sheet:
120mA


Board: 4 copper layers, 377.3 x 130.4 mm, 351 parts (0 on the bottom side), 188 nets.

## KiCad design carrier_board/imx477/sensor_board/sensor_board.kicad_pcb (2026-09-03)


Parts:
C1: 10uF; C_0805_2012Metric; TOLERANCE ±20%; RATINGS 50V; X5R; MANUFACTURER PART NUMBE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 UMK325BJ106MM-T; LCSC Part # C88484
C2, C3, C4, C12, C13: 10uF; C_0805_2012Metric; RATINGS 50V; NP0; VOLTAGE - RATED 50V; MANUFACTURER PART NUMBE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 06035A561JAT2A; LCSC Part # C88484
C5, C6, C7, C8, C9, C10, C11, C14: 100nF; C_0805_2012Metric; TOLERANCE ±10%; RATINGS 16V; X7R; MANUFACTURER PART NUMBE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 CC0402KRX7R7BB103; LCSC Part # C49678
C15, C16: 10uF; C_0805_2012Metric; TOLERANCE ±10%; RATINGS 16V; X5R; MANUFACTURER PART NUMBE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 EMK212BJ475KG-T; LCSC Part # C88484
FB1, FB2: 1 kΩ @ 100 MHz; L_0805_2012Metric; Part# MPZ2012S102AT000; LCSC Part # C76817
H1, H2, H3, H4, H5, H6, H7, H8: MountingHole; MountingHole_2.5mm
L1: 2u2; L_Taiyo-Yuden_MD-4040; Part# CMLO0420H2R2MTT; LCSC Part # C438930
R1: 1K; R_0805_2012Metric; RATINGS 1/16 W; TOLERANCE ±5%; MANUFACTURER PART NUMBE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 RC0402JR-073K3L; LCSC Part # C95781
R2: 1.2K; R_0805_2012Metric; RATINGS 1/16 W; TOLERANCE ±5%; MANUFACTURER PART NUMBE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 RC0402JR-073K3L; LCSC Part # C114526
R3: 22; R_0805_2012Metric; RATINGS 1/16 W; TOLERANCE ±5%; MANUFACTURER PART NUMBE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 RC0402JR-073K3L; LCSC Part # C107702
R4: 2.2K; R_0805_2012Metric; RATINGS 1/16 W; TOLERANCE ±5%; MANUFACTURER PART NUMBE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 RC0402JR-073K3L; LCSC Part # C114237
R5: 10K; R_0805_2012Metric; RATINGS 1/16 W; TOLERANCE ±5%; MANUFACTURER PART NUMBE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 RC0402JR-073K3L; LCSC Part # C100047
R6: 27K; R_0805_2012Metric; RATINGS 1/16 W; TOLERANCE ±5%; MANUFACTURER PART NUMBE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 RC0402JR-073K3L; LCSC Part # C728647
R8: 30K; R_0805_2012Metric; RATINGS 1/16 W; TOLERANCE ±5%; MANUFACTURER PART NUMBE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 RC0402JR-073K3L; LCSC Part # C126352
U1: MICROCHIP MIC5504-1.8YM5-TR; SOT-23-5; Part# MIC5504-1.8YM5-TR; LCSC Part # C626116
U2: MICROCHIP MIC5504-2.8YM5-TR; SOT-23-5; Part# MIC5504-2.8YM5-TR; LCSC Part # C95749
U3: AP3417C; SOT-23-5; Part# AP3417CKTR-G1; LCSC Part # C500759
U4: APX803; SOT-23-3; Part# APX803S-23SA-7; LCSC Part # C2067713
X1: DSO221SR; Crystal_SMD_2520-4Pin_2.5x2.0mm

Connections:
1V05: C14.2, C15.1, C16.1, L1.2, R8.2; also elsewhere on the board
1V8: C10.2, C12.1, U1.5 (VOUT), X1.4 (VCC); also elsewhere on the board
2V8: C11.2, C13.1, U2.5 (VOUT); also elsewhere on the board
+5V: C2.1, C3.1, C4.1, C6.2, C7.2, C8.2, FB1.2, FB2.2, R4.2, U1.1 (VIN), U2.1 (VIN), U3.4 (VIN)
CAM_CLK: X1.3 (OUT); also elsewhere on the board
ENABLE_PWR: R5.2, U1.3 (EN), U2.3 (EN), U3.1 (EN); also elsewhere on the board
ENABLE_XCLR: R3.1; also elsewhere on the board
ENABLE_XTAL: R1.2; also elsewhere on the board
GND: C1.2, C2.2, C3.2, C4.2, C5.1, C6.1, C7.1, C8.1, C9.1, C10.1, C11.1, C12.2, C13.2, C14.1, C15.2, C16.2, R2.1, R5.1, R6.1, U1.2 (GND), U2.2 (GND), U3.2 (GND), U4.1 (GND), X1.2 (GND); also elsewhere on the board
unnamed: R6.2, R8.1, U3.5 (FB)
unnamed: L1.1, U3.3 (LX)
unnamed: C9.2, R3.2, R4.1, U4.3 (VCC)
unnamed: C5.2, R1.1, R2.2, X1.1 (OE)
VIN_5V: C1.1, FB1.1, FB2.1; also elsewhere on the board
XCLR: U4.2 (~RESET); also elsewhere on the board

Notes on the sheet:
1. The Circuit Logic (Weak vs. Strong) The APX803 is a voltage supervisor that monitors the voltage on its own VCC pin. If VCC drops below a specific threshold (e.g., 2.93V or 4.38V), it asserts the RESET signal (pulls it LOW). 5V via 2.2kΩ (2200Ω): This acts as a "Weak" source. It tries to pull th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
2.8V (VANA) Analog Pixel Array Low (~50mA) LDO Noise Sensitive. Any ripple here creates visible lines in the image. Efficiency doesn't matter because current is low. 1.8V (VIF) I/O Interface Low (~30mA) LDO Interface Level. Keeps signals clean for I2C communication. 1.05V (VDIG) Digital Logic Core 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
27Mhz crystal, can have an enable line here to control OE to start crystal


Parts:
C17, C18, C19, C62, C63, C64: 10uF; C_0805_2012Metric; RATINGS 50V; NP0; VOLTAGE - RATED 50V; MANUFACTURER PART NUMBE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 06035A561JAT2A; LCSC Part # C88484
C20, C21, C22, C23, C24, C25, C26, C27, C28, C29, C30, C31, C32, C33, C34, C35, C36, C37, C38, C39, C40, C41, C42, C43, C44, C45, C46, C47, C48, C49, C50, C51, C52, C53, C54, C55, C56, C57, C58, C59, C60, C61: 100nF; C_0805_2012Metric; TOLERANCE ±10%; RATINGS 16V; X7R; MANUFACTURER PART NUMBE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 CC0402KRX7R7BB103; LCSC Part # C49678
J1: DF40C-60DP-0.4V(51); Hirose_DF40C-60DP-0.4V_2x30-1MP_P0.4mm; Part# DF40C-60DP-0.4V(51); LCSC Part # C424647
R10, R11: 10K; R_0805_2012Metric; RATINGS 1/16 W; TOLERANCE ±5%; MANUFACTURER PART NUMBE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 RC0402JR-073K3L; LCSC Part # C100047
U5, U6: IMX477AACK-C; LGA-92_L10.5-W8.5-P0.80_IMX477-AAPK-C

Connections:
1V05: C20.2, C21.2, C23.2, C25.2, C27.2, C29.2, C31.2, C34.2, C37.2, C40.2, C42.2, C45.2, C48.2, C51.2, C53.2, C55.2, C57.2, C59.2, C60.2, C61.2, U5.A6 (VddLCN1), U5.B1 (VddLSC1), U5.B10 (VddLSC2), U5.F8 (VddLPL1), U5.G10 (VddLCN2), U5.H1 (VddLSC3), U5.H8 (VddLPL2), U5.J1 (VddLIF), U5.L10 (VddLSC4), U6.A6 (VddLCN1), U6.B1 (VddLSC1), U6.B10 (VddLSC2), U6.F8 (VddLPL1), U6.G10 (VddLCN2), U6.H1 (VddLSC3), U6.H8 (VddLPL2), U6.J1 (VddLIF), U6.L10 (VddLSC4); also elsewhere on the board
1V8: C32.2, C35.2, C38.2, C43.2, C46.2, C49.2, U5.C1 (VddMIO1), U5.J10 (VddMIO2), U5.K1 (VddMIF), U6.C1 (VddMIO1), U6.J10 (VddMIO2), U6.K1 (VddMIF); also elsewhere on the board
2V8: C22.2, C24.2, C26.2, C28.2, C30.2, C33.2, C36.2, C39.2, C41.2, C44.2, C47.2, C50.2, C52.2, C54.2, C56.2, C58.2, U5.C3 (VddHSN1), U5.D3 (VddHAN), U5.D8 (VddHSN2), U5.E8 (VddHCM1), U5.K3 (VddHSN3), U5.K5 (VddSUB), U5.K6 (VddHSN4), U5.K8 (VddHCM2), U6.C3 (VddHSN1), U6.D3 (VddHAN), U6.D8 (VddHSN2), U6.E8 (VddHCM1), U6.K3 (VddHSN3), U6.K5 (VddSUB), U6.K6 (VddHSN4), U6.K8 (VddHCM2); also elsewhere on the board
/sensors/CAM1_CLK_N: J1.46, U5.M5 (DCKN)
/sensors/CAM1_CLK_P: J1.48, U5.L5 (DCKP)
/sensors/CAM1_D1_N: J1.42, U5.M3 (DMO1N)
/sensors/CAM1_D1_P: J1.40, U5.L3 (DMO1P)
/sensors/CAM1_D2_N: J1.52, U5.M7 (DMO2N)
/sensors/CAM1_D2_P: J1.54, U5.L7 (DMO2P)
/sensors/CAM1_D3_N: J1.36, U5.M2 (DMO3N)
/sensors/CAM1_D3_P: J1.34, U5.L2 (DMO3P)
/sensors/CAM1_D4_N: J1.58, U5.M8 (DMO4N)
/sensors/CAM1_D4_P: J1.60, U5.L8 (DMO4P)
/sensors/CAM2_CLK_N: J1.16, U6.M5 (DCKN)
/sensors/CAM2_CLK_P: J1.18, U6.L5 (DCKP)
/sensors/CAM2_D1_N: J1.51, U6.M3 (DMO1N)
/sensors/CAM2_D1_P: J1.53, U6.L3 (DMO1P)
/sensors/CAM2_D2_N: J1.22, U6.M7 (DMO2N)
/sensors/CAM2_D2_P: J1.24, U6.L7 (DMO2P)
/sensors/CAM2_D3_N: J1.57, U6.M2 (DMO3N)
/sensors/CAM2_D3_P: J1.59, U6.L2 (DMO3P)
/sensors/CAM2_D4_N: J1.28, U6.M8 (DMO4N)
/sensors/CAM2_D4_P: J1.30, U6.L8 (DMO4P)
/sensors/SCL_1V8: J1.21, U5.B7 (SCL), U6.B7 (SCL)
/sensors/SDA_1V8: J1.23, U5.A7 (SDA), U6.A7 (SDA)
/sensors/XVS0: J1.15, U5.A2 (XVS)
/sensors/XVS1: J1.17, U6.A2 (XVS)
CAM_CLK: U5.K10 (INCLK), U6.K10 (INCLK); also elsewhere on the board
ENABLE_PWR: J1.31; also elsewhere on the board
ENABLE_XCLR: J1.29; also elsewhere on the board
ENABLE_XTAL: J1.27; also elsewhere on the board
GND: C17.2, C18.2, C19.2, C20.1, C21.1, C22.1, C23.1, C24.1, C25.1, C26.1, C27.1, C28.1, C29.1, C30.1, C31.1, C32.1, C33.1, C34.1, C35.1, C36.1, C37.1, C38.1, C39.1, C40.1, C41.1, C42.1, C43.1, C44.1, C45.1, C46.1, C47.1, C48.1, C49.1, C50.1, C51.1, C52.1, C53.1, C54.1, C55.1, C56.1, C57.1, C58.1, C59.1, C60.1, C61.1, C62.2, C63.2, C64.2, J1.11, J1.12, J1.13, J1.14, J1.19, J1.20, J1.25, J1.26, J1.32, J1.33, J1.35, J1.37, J1.38, J1.39, J1.41, J1.43, J1.44, J1.45, J1.47, J1.49, J1.50, J1.55, J1.56, R10.1, R11.2, U5.A3 (GYINT), U5.A5 (SDI), U5.B2 (VssLSC1), U5.B3 (TEST3/SDIC), U5.B6 (VssLCN1), U5.B9 (VssLSC2), U5.C2 (VssLSC3), U5.C4 (VssHSN1), U5.C7 (VssHSN2), U5.D1 (TEST1/CSBC), U5.D2 (TEST2/SCKC), U5.E3 (VssHAN), U5.G8 (VssLPL1), U5.G9 (VssLCN2), U5.H2 (VssLSC4), U5.J2 (VssLSC5), U5.J8 (VssLPL2), U5.K2 (VssLSC6), U5.K4 (VssHSN3), U5.K7 (VssHSN4), U5.K9 (VssLSC7), U5.L1 (VssLSC8), U5.L4 (VssLSC9), U5.L6 (VssLSC10), U5.L9 (VssLSC11), U5.M4 (VssLSC12), U5.M6 (VssLSC13), U5.M9 (VssLSC14), U6.A3 (GYINT), U6.A5 (SDI), U6.B2 (VssLSC1), U6.B3 (TEST3/SDIC), U6.B6 (VssLCN1), U6.B9 (VssLSC2), U6.C2 (VssLSC3), U6.C4 (VssHSN1), U6.C7 (VssHSN2), U6.D1 (TEST1/CSBC), U6.D2 (TEST2/SCKC), U6.E3 (VssHAN), U6.G8 (VssLPL1), U6.G9 (VssLCN2), U6.H2 (VssLSC4), U6.J2 (VssLSC5), U6.J8 (VssLPL2), U6.K2 (VssLSC6), U6.K4 (VssHSN3), U6.K7 (VssHSN4), U6.K9 (VssLSC7), U6.L1 (VssLSC8), U6.L4 (VssLSC9), U6.L6 (VssLSC10), U6.L9 (VssLSC11), U6.M4 (VssLSC12), U6.M6 (VssLSC13), U6.M9 (VssLSC14); also elsewhere on the board
unnamed: R10.2, U5.A9 (GPO)
unnamed: C19.1, U5.C8 (VPI)
unnamed: C18.1, U5.C6 (VRL)
unnamed: C17.1, U5.C5 (VRLRD)
unnamed: R11.1, U6.A9 (GPO)
unnamed: C62.1, U6.C8 (VPI)
unnamed: C63.1, U6.C6 (VRL)
unnamed: C64.1, U6.C5 (VRLRD)
VIN_5V: J1.1, J1.2, J1.3, J1.4, J1.5, J1.6, J1.7, J1.8, J1.9, J1.10; also elsewhere on the board
XCLR: U5.J9 (XCLR), U6.J9 (XCLR); also elsewhere on the board

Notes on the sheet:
clock input from crystal from page 2
Internal Pull
0011010 if NC/L
0010000 if H



Board: 4 copper layers, 100.0 x 55.0 mm, 92 parts (82 on the bottom side), 47 nets.

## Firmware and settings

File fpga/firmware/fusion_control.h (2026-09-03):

#ifndef FUSION_CONTROL_H
#define FUSION_CONTROL_H
/*
 * fusion_control.h  —  radar_3rx SIMPLE software trigger.
 *
 * Scope for this study: NO camera / computer-vision fusion, and NO hardware
 * peak tracker.  Everything is software:
 *
 *   1. Hear a ball-club impact (AUDIO_LABEL_CLUB) -> ARM a short window.
 *   2. For each completed radar frame, scan the region-C summed |X|^2 map that
 *      the pipeline already wrote to DDR.  From it compute, in software:
 *          peak       = max cell power
 *          mean       = average cell power (noise-floor estimate)
 *          snr        = peak / mean
 *          peak_vel   = velocity of the peak's Doppler bin
 *   3. The FIRST frame (while armed) with |peak_vel| > 50 mph AND snr over the
 *      threshold (~30 dB) requests that frame's A/B/C/D dump to the host AND
 *      asserts `halt` (early stop) so the 2-deep ping-pong does not overwrite
 *      the chosen frame while it streams.
 *
 * Because there are only two ping-pong buffer sets, "remember the best frame
 * across the trajectory" is impossible (it gets overwritten); first-over-SNR +
 * early-stop is the correct, simplest proof-of-concept.
 *
 * Host-testable: compile with -DTRIG_TESTBENCH.
 */

#include "audio_dsp.h"
#include <stdint.h>

/* ── Radar map geometry (matches radar_params.vh) ──────────────────────── */
#define RADAR_RANGE_BINS    128u
#define RADAR_DOPPLER_BINS  256u
#define RADAR_N_CELLS       (RADAR_RANGE_BINS * RADAR_DOPPLER_BINS)
#define RADAR_DOPPLER_CTR   (RADAR_DOPPLER_BINS / 2u)   /* zero-velocity bin */

/* ── Tunables (placeholders for the PoC) ───────────────────────────────── */
enum {
    /* 50 mph = 2235 cm/s radial-speed gate. */
    TRIG_SPEED_CMS        = 2235,

    /* cm/s per Doppler bin.  Placeholder — set from the real chirp/PRF later. */
    TRIG_VEL_RES_CMS      = 55,

    /* SNR gate as a linear POWER ratio.  ~30 dB = 10^3 = 1000.  peak >= snr*mean */
    TRIG_SNR_RATIO        = 1000,

    /* Arm window after impact, and cooldown after a dump (ms). */
    TRIG_ARM_WINDOW_MS    = 400,
    TRIG_COOLDOWN_MS      = 1500
};

/* ── FSM state ─────────────────────────────────────────────────────────── */
typedef enum {
    TRIG_IDLE     = 0,   /* waiting for a ball-impact sound                  */
    TRIG_ARMED    = 1,   /* impact heard; scanning frames                    */
    TRIG_COOLDOWN = 2    /* dump requested; halted, ignore further frames    */
} trig_state_t;

/* Which DDR buffer set a completed frame lives in (software reads STATUS regs).
 * Only B/C/D are dumped to the host; region A (range-FFT scratch) is redundant
 * with B and is not transferred, so there is no A buffer select. */
typedef struct {
    uint8_t  frame_buf_sel;  /* B/C/D set 0/1 */
    uint32_t frame_id;       /* tag echoed to host */
} radar_frame_meta_t;

/* What software writes into radar_dump_axi_regs when a frame qualifies. */
typedef struct {
    uint8_t  dump_request;   /* 1 => write DUMP_SEL/FID then CTRL.start_dump|set_halt */
    uint8_t  halt;           /* 1 => freeze the radar pipeline (early stop)           */
    uint8_t  frame_buf_sel;
    uint32_t frame_id;
    /* Diagnostics from the scan (handy for logging / threshold tuning). */
    uint32_t peak;
    uint32_t mean;
    int32_t  peak_vel_cms;
    trig_state_t state;
} trig_output_t;

/* ── Public API ────────────────────────────────────────────────────────── */
void          trig_reset(void);
trig_state_t  trig_state(void);

/* Audio classifier output; CLUB impact arms the trigger. */
trig_output_t trig_submit_audio(audio_label_t label, uint32_t now_ms);

/* Scan one completed frame's region-C map (RADAR_N_CELLS uint32 cells) and
 * decide.  `cmap` points at C0 or C1 in DDR per meta->frame_buf_sel. */
trig_output_t trig_submit_frame(const uint32_t *cmap,
                                const radar_frame_meta_t *meta,
                                uint32_t now_ms);

trig_output_t trig_last_output(void);

#endif /* FUSION_CONTROL_H */

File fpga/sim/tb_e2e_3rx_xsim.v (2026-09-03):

`timescale 1ns/1ps
`default_nettype none

// ============================================================================
// tb_radar_pipeline_e2e.v
//
// Single-file end-to-end testbench for the radar 01..08 B/C/D ping-pong path.
//
// Merges the former 01_tb_full_pipeline_top.v (DUT wiring) and
// 02_tb_full_pipeline_xsim_e2e_top.v (stimulus/checking) into one module.
//
// Benefits vs the two-file split:
//   - No hierarchical dut.signal references => no XSim initial-block
//     scheduling races (the bvalid race that required the bvalid_pending fix)
//   - No intermediate port boundary => no FIFOs invented to paper over it
//   - DUT wiring matches radar_test.v block design exactly: direct connections,
//     no axis_fifo_simple anywhere in the signal path
//   - One file to maintain instead of two
// ============================================================================

`timescale 1ns/1ps
`default_nettype none

`define AXI_WR_DECL(P) \
    wire [31:0] P``_awaddr; \
    wire [7:0]  P``_awlen; \
    wire [2:0]  P``_awsize; \
    wire [1:0]  P``_awburst; \
    wire        P``_awvalid; \
    reg         P``_awready; \
    wire [31:0] P``_wdata; \
    wire [3:0]  P``_wstrb; \
    wire        P``_wlast; \
    wire        P``_wvalid; \
    reg         P``_wready; \
    reg  [1:0]  P``_bresp; \
    reg         P``_bvalid; \
    wire        P``_bready

`define AXI_RD_DECL(P) \
    wire [31:0] P``_araddr; \
    wire [7:0]  P``_arlen; \
    wire [2:0]  P``_arsize; \
    wire [1:0]  P``_arburst; \
    wire        P``_arvalid; \
    reg         P``_arready; \
    reg  [31:0] P``_rdata; \
    reg  [1:0]  P``_rresp; \
    reg         P``_rlast; \
    reg         P``_rvalid; \
    wire        P``_rready

`define AXI_WR_PORTS(PORT, BUS) \
    .PORT``_awaddr(BUS``_awaddr), \
    .PORT``_awlen(BUS``_awlen), \
    .PORT``_awsize(BUS``_awsize), \
    .PORT``_awburst(BUS``_awburst), \
    .PORT``_awvalid(BUS``_awvalid), \
    .PORT``_awready(BUS``_awready), \
    .PORT``_wdata(BUS``_wdata), \
    .PORT``_wstrb(BUS``_wstrb), \
    .PORT``_wlast(BUS``_wlast), \
    .PORT``_wvalid(BUS``_wvalid), \
    .PORT``_wready(BUS``_wready), \
    .PORT``_bresp(BUS``_bresp), \
    .PORT``_bvalid(BUS``_bvalid), \
    .PORT``_bready(BUS``_bready)

`define AXI_RD_PORTS(PORT, BUS) \
    .PORT``_araddr(BUS``_araddr), \
    .PORT``_arlen(BUS``_arlen), \
    .PORT``_arsize(BUS``_arsize), \
    .PORT``_arburst(BUS``_arburst), \
    .PORT``_arvalid(BUS``_arvalid), \
    .PORT``_arready(BUS``_arready), \
    .PORT``_rdata(BUS``_rdata), \
    .PORT``_rresp(BUS``_rresp), \
    .PORT``_rlast(BUS``_rlast), \
    .PORT``_rvalid(BUS``_rvalid), \
    .PORT``_rready(BUS``_rready)

`define AXI_WRITE_SLAVE(P) \
    reg [31:0] P``_wr_addr; \
    reg [8:0]  P``_wr_beats_left; \
    reg [2:0]  P``_wr_size; \
    reg [1:0]  P``_wr_burst; \
    reg        P``_wr_active; \
    // bvalid_pending: bvalid was SET this negedge; do not clear until next negedge so \
    // the DUT's posedge always-block has a guaranteed window to sample it. \
    // Without this guard, XSim's initial-block negedge scheduling can set and clear \
    // bvalid in consecutive negedges straddling a posedge, making the DUT miss it. \
    reg        P``_bvalid_pending; \
    initial begin : P``_write_slave \
        P``_wr_addr = 32'd0; \
        P``_wr_beats_left = 9'd0; \
        P``_wr_size = 3'd2; \
        P``_wr_burst = 2'd1; \
        P``_wr_active = 1'b0; \
        P``_bvalid_pending = 1'b0; \
        P``_awready = 1'b1; \
        P``_wready = 1'b1; \
        P``_bresp = 2'b00; \
        P``_bvalid = 1'b0; \
        forever begin \
            @(negedge clk); \
            if (!rst_n) begin \
                P``_wr_addr = 32'd0; \
                P``_wr_beats_left = 9'd0; \
                P``_wr_size = 3'd2; \
                P``_wr_burst = 2'd1; \
                P``_wr_active = 1'b0; \
                P``_bvalid_pending = 1'b0; \
                P``_awready = 1'b1; \
                P``_wready = 1'b1; \
                P``_bresp = 2'b00; \
                P``_bvalid = 1'b0; \
            end else begin \
                P``_awready = !P``_wr_active; \
                P``_wready = 1'b1; \
                // Only clear bvalid if it was already asserted on the PREVIOUS negedge \
                // (P_bvalid_pending=0 now) so the DUT posedge between the two negedges \
                // has a full half-cycle window to sample bvalid=1. \
                if (P``_bvalid && P``_bready && !P``_bvalid_pending) begin \
                    P``_bvalid = 1'b0; \
                end \
                P``_bvalid_pending = 1'b0; \
                if (!P``_wr_active && P``_awvalid && P``_awready) begin \
                    P``_wr_addr = P``_awaddr; \
                    P``_wr_beats_left = {1'b0, P``_awlen} + 9'd1; \
                    P``_wr_size = P``_awsize; \
                    P``_wr_burst = P``_awburst; \
                    P``_wr_active = 1'b1; \
                end \
                if (P``_wvalid && P``_wready) begin \
                    if (!P``_wr_active) begin \
                        $display("ERROR: %s W beat before AW at %0t", `"P`", $time); \
                        $fatal(1); \
                    end \
                    ddr_write32(P``_wr_addr, P``_wdata, P``_wstrb); \
                    note_write(P``_wr_addr, P``_wdata); \
                    if (P``_wr_beats_left == 9'd1) begin \
                        if (!P``_wlast) begin \
                            $display("ERROR: %s missing WLAST at final beat, addr=0x%08x", `"P`", P``_wr_addr); \
                            $fatal(1); \
                        end \
                        P``_wr_active = 1'b0; \
                        P``_wr_beats_left = 9'd0; \
                        P``_bresp = 2'b00; \
                        P``_bvalid = 1'b1; \
                        P``_bvalid_pending = 1'b1; \
                    end else begin \
                        if (P``_wlast) begin \
                            $display("ERROR: %s early WLAST, addr=0x%08x beats_left=%0d", `"P`", P``_wr_addr, P``_wr_beats_left); \
                            $fatal(1); \
                        end \
                        P``_wr_beats_left = P``_wr_beats_left - 9'd1; \
                        if (P``_wr_burst == 2'd1) begin \
                            P``_wr_addr = P``_wr_addr + (32'd1 << P``_wr_size); \
                        end \
                    end \
                end \
            end \
        end \
    end
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
